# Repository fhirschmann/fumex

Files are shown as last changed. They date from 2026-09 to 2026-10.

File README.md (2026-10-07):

# FUMEX — a solder fume extractor that bends towards the work

Open the interactive 3D viewer (https://fhirschmann.github.io/fumex/)

Explore every part in the browser with an exploded view and section plane.

A 120 mm PWM fan pulls the smoke off the soldering iron through a 120 × 120 × 17 mm filter mat and blows it out the back, away from you. The housing stands upright over its electronics bay and then bends 15° forward, so the intake face looks down at the joint instead of past it. Battery powered: a 3.2 V 6000 mAh LiFePO4 pack runs it for hours and charges over USB-C while the fan keeps going.

Designed for a Bambu Lab H2S with AMS in Bambu PETG black and grey. The electronics are the ones from [LEO-AC1](https://github.com/fhirschmann/leo-ac1); only the fan is different.

**Status:** finished. The current revision has been printed and assembled, and all parts fit as designed.

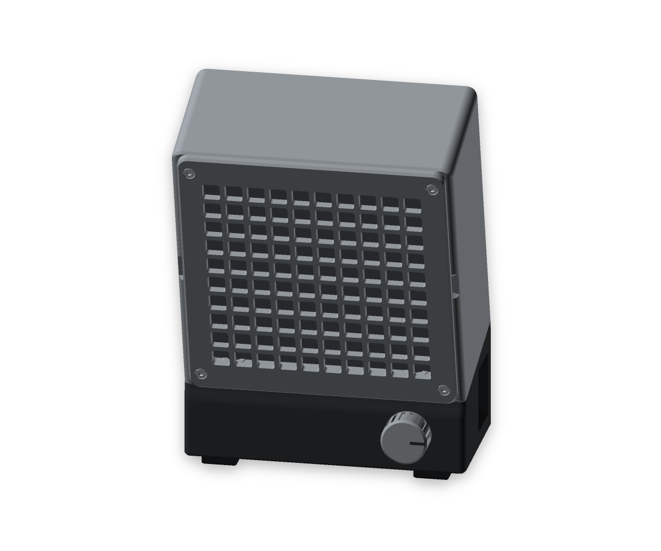
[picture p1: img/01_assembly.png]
Assembly (https://fhirschmann.github.io/fumex/)


| Exploded | Back |
|:---:|:---:|
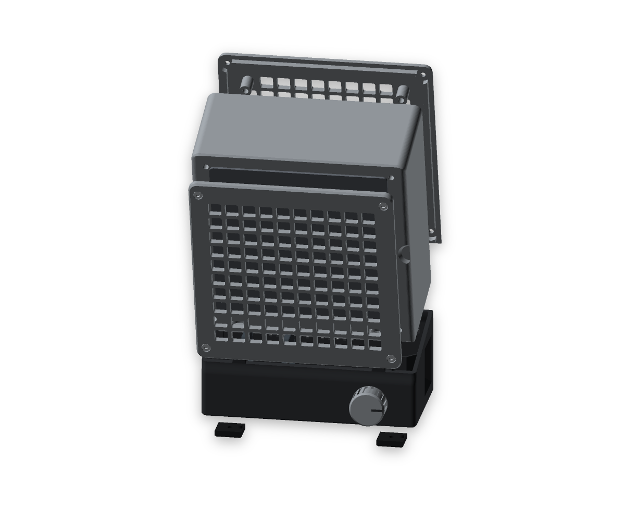
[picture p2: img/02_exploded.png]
Exploded
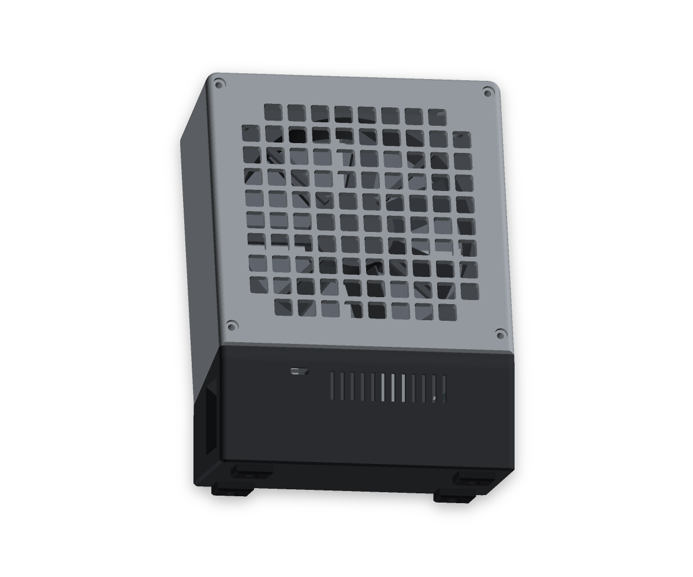
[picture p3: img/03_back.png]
Back
|  |  |

## How the air runs

```
grid of the cassette ─► mat 17 mm ─► support cross / throat 117 ─► fan 120 × 25 ─► plenum ─► slots in the back cover
```

The mat sits on the intake side, so flux resin settles in the fleece and the impeller stays clean. It is held by a continuous 2.25 mm lip around the 117 mm intake opening. A rear lip catches its edges, and a separate **support cross** behind the mat limits bowing towards the fan. Its solid 4 mm wide, 5 mm deep bars have a rounded centre and smooth transitions to wider end pads. The cross covers about 7.2 % of the opening, leaving 92.8 % open. It starts 0.5 mm behind the nominal mat rear face and leaves 5 mm between its central bars and the fan frame's front plane. The soft mat and printed bars can still flex; check for rubbing at full speed with the actual mat fitted.

| Filter support cross | Spring pad detail |
|:---:|:---:|
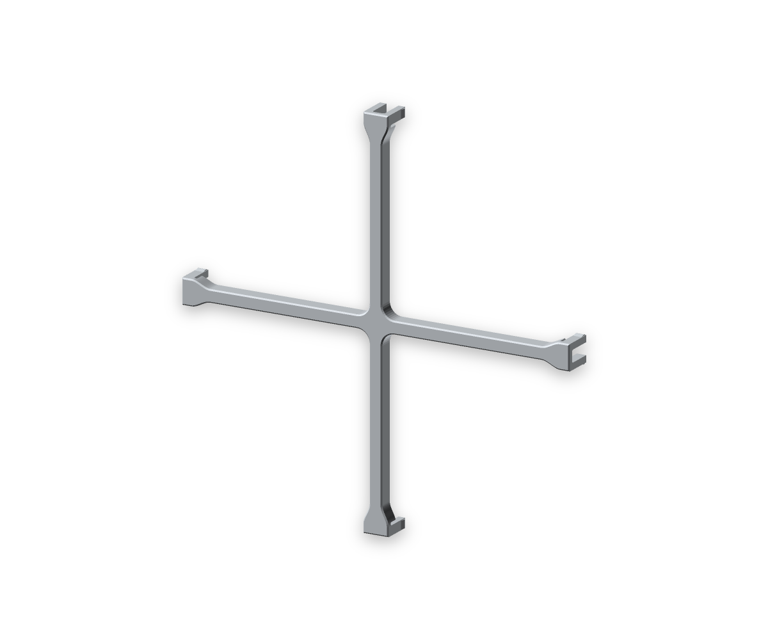
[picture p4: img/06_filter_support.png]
Filter support cross behind the mat
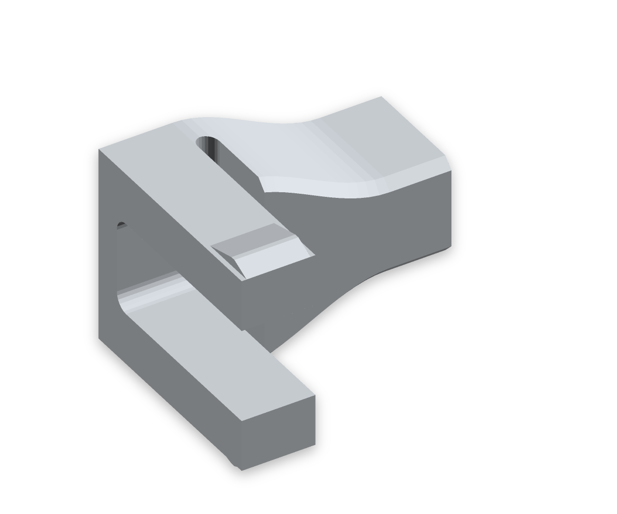
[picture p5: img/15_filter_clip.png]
Split spring pad and tapered gripping ribs
|  |  |

That rear lip is also the fan's seat: the filter tube ends as a ring the fan frame sits on. The support cross presses into four pockets from the back. Each end has two spring cheeks with tapered contact ribs: their free width is 8.7 mm against the existing 8.4 mm sockets, so they grip before the fan is fitted. Rounded relief slots let the cheeks flex; no screws or glue are needed. The fan frame supplies an additional rear stop. The fan is screwed to the **back cover** — four spacer posts on the cover carry its heat-set inserts, and the M3 × 30 go in from the front of the fan. Fan and cover are screwed together on the bench, where that face is reachable, and the pair goes into the head as one part. The four internal corner guides have 1.2 mm lead-in chamfers on both inner edges, widening the entry clearance to 1.6 mm per side before the straight 0.4 mm guides locate the frame.

Four **M3 × 8 Torx button-head screws** hold the filter cassette against the head, engaging Ruthex inserts in its four corners. The screws pass through Ø3.4 mm holes and sit in flat Ø6.4 mm recesses, 1.9 mm deep. Their heads lie fully inside the recesses, 0.25 mm below the cassette face. The cassette is 4 mm thick, with four smooth R6 corners matching the head’s upper corner radius. Its continuous 1.2 mm bevel leaves 2.8 mm of straight rim and R4.8 corners on the visible face. After removing the screws, use the two side finger scoops to lift it away. No magnets or insertion pauses are needed.

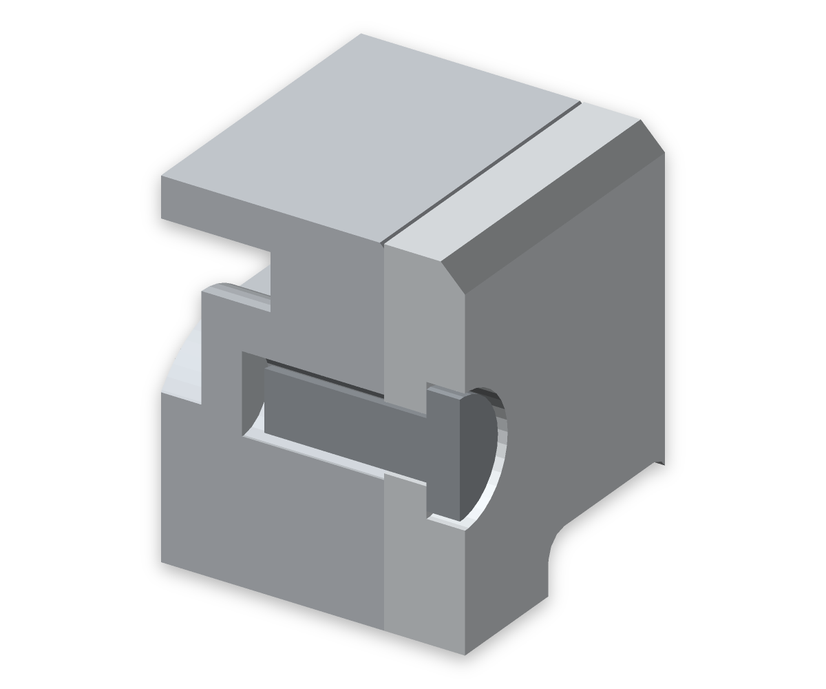
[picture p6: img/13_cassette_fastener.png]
Section through the recessed cassette screw and the head’s blind insert pocket


*Cassette corner section: the M3 × 8 head sits below the outer face; the Ruthex insert fits in the head’s blind pocket.*

The charge module stands upright on the ballast lid at the back of the bay. Its lower edge stands 9 mm above the lid. A separate holder modelled on LEO-AC1 grips only the cool OUT end: the end goes into a small L, then the board is pressed back until two spring jaws snap their hooks 0.9 mm over the part side at both long edges, and one cable tie through the holder's web secures it. The holder ends 11 mm from the OUT end, 5.7 mm before the 20 mm heatsink, and the hot end stays free. Its components face forwards and its heatsink faces the back wall, exposing both sides of the hot end to air. Five slots and the larger cable notch connect to the plenum behind the fan, with passages past the component side and the heatsink to the back-wall ventilation slots. This branch carries filtered air because it starts downstream of the mat. With the fan off, the same openings allow natural convection. Actual cooling must be checked with the assembled wiring and the housing closed.

| Component side | Heatsink side |
|:---:|:---:|
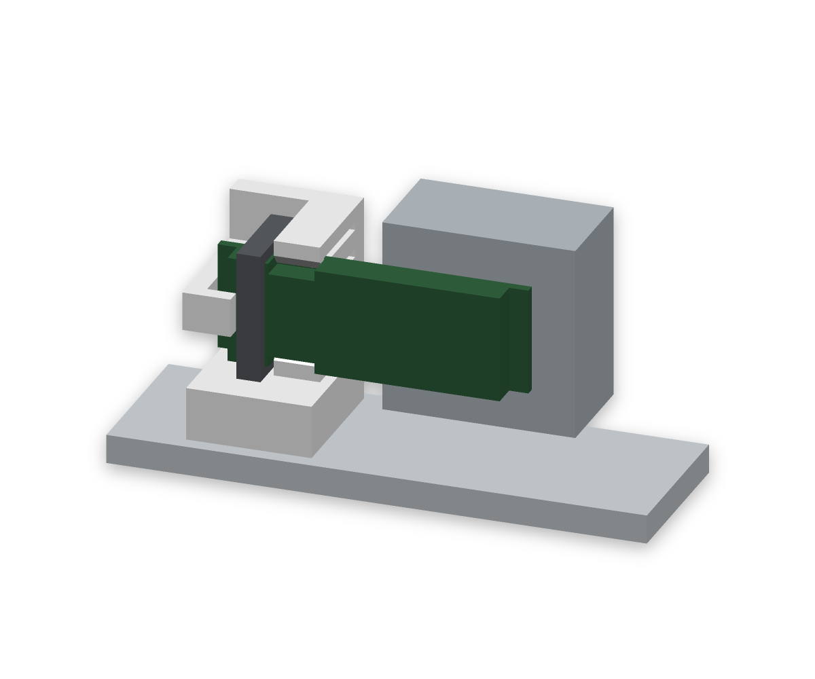
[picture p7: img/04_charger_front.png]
Upright charge module, component side
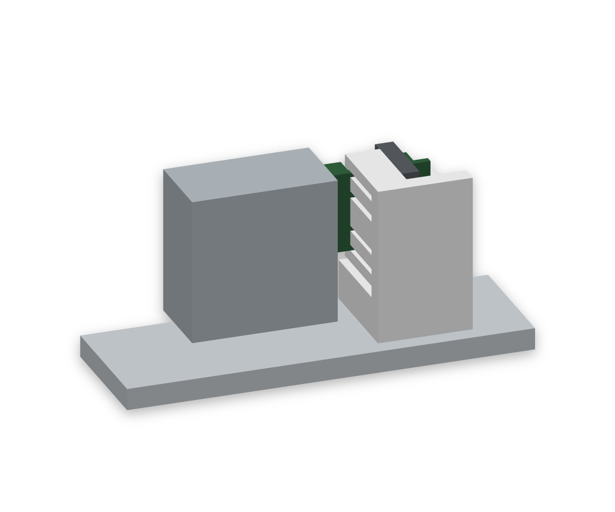
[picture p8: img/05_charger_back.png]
Upright charge module, heatsink side
|  |  |

## Printed parts

Nine part types, twelve printed pieces including the four feet.

| Part | Qty | Material | Size (mm) | Print orientation |
|---|---|---|---|---|
| `head` fan and filter housing | 1 | PETG grey | 145 × 145 × 70 | intake face on the bed |
| `base` electronics bay | 1 | PETG black | 145 × 74 × 57.3 | bottom on the bed |
| `head_back` back cover | 1 | PETG grey | 145 × 144.7 × 15.9 | outside on the bed |
| `ball_lid` ballast lid and USB keeper | 1 | PETG grey | 132.6 × 18.6 × 24.2 | flat on the bed |
| `chg_holder` charge-module clip holder | 1 | PETG grey | 13 × 21.5 × 16.1 | back plate on the bed, jaws upwards, 100 % infill |
| `filter_support` support cross | 1 | PETG grey | 123 × 123 × 9.8 | mat-facing side on the bed, four posts upwards |
| `cassette` filter cassette | 1 | PETG grey | 138 × 143 × 4 | grid face on the bed |
| `knob` speed knob | 1 | PETG grey + black pointer | Ø 24 × 13.5 | top on the bed |
| `foot` foot | 4 | TPU | 18 × 16 × 6.5 | ground face on the bed, 100 % infill |

All parts are in the Bambu Studio project [`stl/fumex_all_parts.3mf`](stl/fumex_all_parts.3mf): plate 1 head, plate 2 base, plate 3 cassette, plate 4 grey back cover, ballast lid, support cross and charge-module holder, plate 5 knob, plate 6 TPU feet. Head and cassette remain on their own plates; neither needs an insertion pause. The head is grey like the cassette, while the base is black. Filaments: 1 PETG black, 2 PETG grey, 3 TPU, 4 PETG black for the knob pointer. Map slots 1 and 4 to the same dark spool. The knob has a flush dark pointer in its first 0.8 mm and uses a prime tower on its own plate; all other plates are single-colour. Every part prints without supports.

Print profile: 0.20 mm layers, **1 wall on the first layer**, 4 walls on subsequent layers, 5 top/bottom layers, 20 % gyroid; support cross, charge-module holder and TPU feet at 100 % infill.

The six plates use about **480.1 g of filament and 16.3 hours**, including the knob's
two-colour prime tower. Head and cassette together use about **271.8 g and 8.1 hours**.

Use the **Engineering Plate with 3DLAC**. The saved positions let three successive
jobs use separate areas of one full-bed coating:

| Coating | Print these virtual plates in order |
|---|---|
| 1 | 1 Head → 2 Base → 3 Cassette |
| 2 | 4 Grey covers and support → 5 Knob → 6 TPU feet |

Between jobs, remove the finished parts, brims, prime tower and purge-line remnants;
leave the adhesive on the unused areas. Keep the saved positions instead of using
Auto Arrange or centring the parts again. The standard printer start and calibration
routines stay enabled and may revisit their usual areas. The filament profiles set
the Engineering Plate to 70 °C for PETG and 35 °C for TPU.

Before printing the base, use [`stl/fumex_usb_fit.3mf`](stl/fumex_usb_fit.3mf) to check the USB board in small sections of the real base and lid (about **10.0 g and 62 minutes**). With the lid section removed, lower the board in front of the channel and slide it towards the rear wall. Then place the lid section on its two small fixture pads and the retained screw-post seat: its central keeper secures the board from the front and above while leaving both side wire exits open. Two low triangular ribs brace the keeper against the lid. These two optional test pieces are not part of the full assembly.

A rounded end wall in the base sits beside the battery’s right end with 0.5 mm axial clearance. A full-height web joins the stop to the ballast trough wall for lateral support; its sloping top clears the removable lid. The left housing wall and this stop prevent lengthwise sliding. Two cable ties through integrated loops under the cell hold it down in its three saddles, including while the base is open. The ties run directly around the shrink-wrapped pack, without printed spacers. Tighten them gently by hand so the pack stays seated without crushing the wrap or electronics beneath it. Cut and replace the ties to remove the battery. Optional cushioning must not raise the cell from its designed seating height.

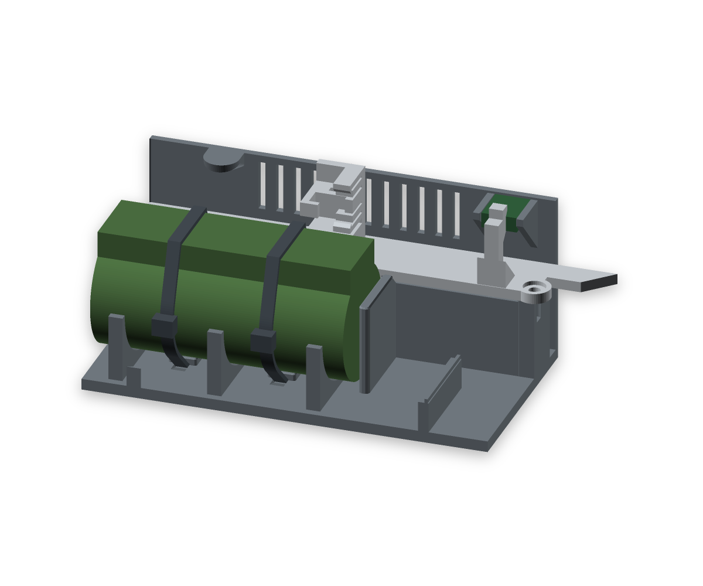
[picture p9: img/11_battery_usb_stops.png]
Direct battery cable ties and central removable USB-board keeper


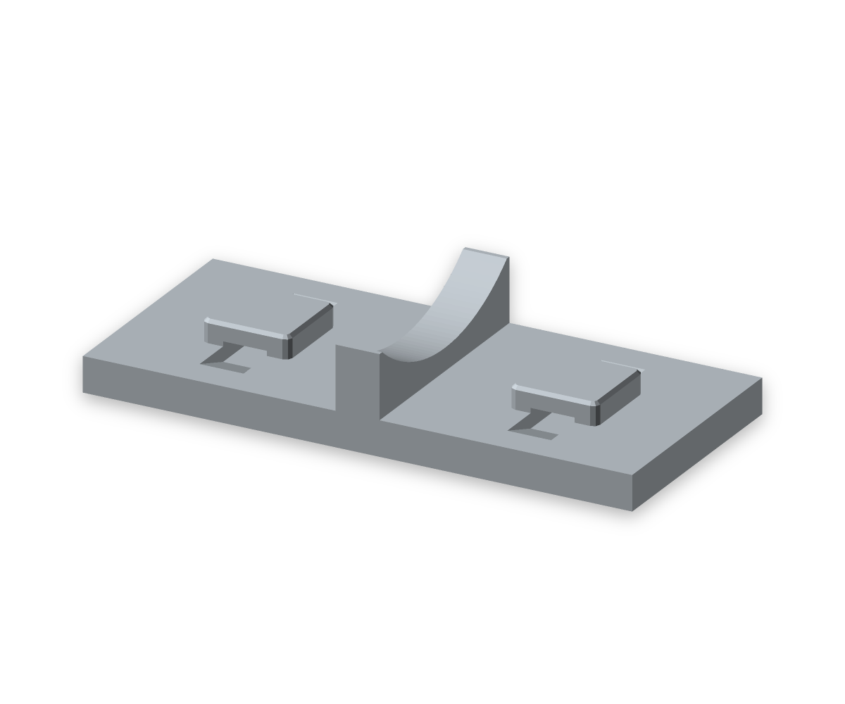
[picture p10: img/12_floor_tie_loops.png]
Two floor loops with shallow threading ramps, battery removed


## Bought parts

| Part | Qty | Link | Notes |
|---|---|---|---|
| Fan ARCTIC P12 Pro (PST) | 1 | [arctic.de](https://www.arctic.de/en/P12-Pro-PST/ACFAN00306A) | 120 × 120 × 25 mm, 185 g, 600–3000 rpm, 131 m³/h, 6.9 mmH₂O, 12 V / 0.33 A, 0 rpm below 5 % PWM; pressure-optimised, which is what a filter mat needs. Blowing towards the back |
| Filter mat, 120 × 120 × 17 | 1 | – | cut from a cooker hood mat: white fleece plus a carbon layer. **Fleece side to the front**, carbon behind it |
| Battery 3.2 V 6000 mAh LiFePO4 pack with protection board (BMS), JST-PH 2.0 | 1 | [eremit.de](https://www.eremit.de/p/3-2v-6000mah-pack-mit-schutz-arduino-aio-jst-ph-2-0-stecker) | cell Ø 32.5 × 71.6 mm, lying across the bay, protection board up; charge only with a LiFePO4 charger (3.65 V), **no** TP4056 |
| Charge/boost module "2-in-1 3.2 V LiFePO4", **12 V variant** | 1 | [AliExpress](https://de.aliexpress.com/item/1005008094801881.html) | eletechsup LFUPSMA, board 32.2 × 11 × 1.0 mm; IN± 5 V charging, B± battery, O± 12 V. See the note on its 0.32 A rating below |
| Aluminium heatsink 20 × 20 × 10 mm with a 1 mm insulating silicone thermal pad | 1 | – | on the back of the charge module behind the charger IC, overhanging the IN end by 4.5 mm and facing the back-wall vents; the pad must cover the whole heatsink face |
| PWM fan controller CNY-FA5-PRO, DC 8–24 V, with potentiometer and switch | 1 | [AliExpress](https://de.aliexpress.com/item/1005010113177510.html) | 41 × 32 × 15 mm, flat in the bay, shaft through the front panel |
| USB-C PD trigger module, Type A (default 5 V) | 1 | [AliExpress](https://de.aliexpress.com/item/1005010610660644.html) | charging socket high in the back wall, above the ballast lid. **Leave pads 1–4 open** (they select 9/12/15/20 V); the charge module only takes 4–6 V, check 5 V with a multimeter before connecting |
| ON-OFF rocker switch, snap-in, 21 × 15 mm (cut-out 19.2 × 12.2 mm) | 1 | [AliExpress](https://de.aliexpress.com/item/1005008871215158.html) | in the right side wall, long side upright |
| LED 3 mm, breathing/fading, 3.3 V, water clear | 1 | [AliExpress](https://de.aliexpress.com/item/1005005336879647.html) | charge indicator beside the knob, fitted from inside behind a closed 1.8 mm front skin; check visibility through the chosen PETG |
| Additional Ø3 mm LED, optional | 1 | – | second closed-front pocket beside the charge indicator; select and wire it for the intended signal |
| Resistor 220 Ω, 1/4 W | 1 | – | series resistor for the LED on the 5 V USB input |
| Resettable PTC fuse Bourns MF-R160 or RXEF160 (1.6 A hold) | 1 | – | optional, between battery plus and the switch, in heat shrink |
| Thermoplastic screws 2.5 × 8, flat underside, head Ø4.5 | 2 | user’s stock | PWM controller into the two floor bosses |
| Heat-set inserts Ruthex RX-M3x5.7 | 22 | [ruthex.de](https://www.ruthex.de) | 4 cassette, 4 fan, 4 back cover, 4 head screws, 4 feet, 2 ballast lid |
| M3 × 30, ISO 7380 Torx | 4 | – | fan to the back cover; the frame alone is 25 mm thick, so nothing shorter reaches a thread |
| M3 × 8, ISO 7380 Torx | 18 | user’s stock | cassette (4), back cover (4), head screws (4), feet (4), ballast lid (2) |
| Iron offcuts for the ballast | – | – | up to 40.3 cm³, about 189 g, loose in the trough under its lid |
| JST-PH 2.0 cable, 2-pin, mating the battery plug | 1 | – | battery to the switch and B+ / B− |
| Cable tie, 2.5 mm wide × 1.2 mm thick | 1 | – | secures the clipped charge module through the holder's web |
| Cyanoacrylate gel (superglue gel) | a few drops | – | glues the charge-module holder over its two pads on the ballast lid |
| Cable tie, 3.6 mm wide × 1.2 mm thick, 150 mm long | 2 | – | battery restraint directly around the wrapped pack through the floor loops; tighten gently by hand |
| Silicone wire 24 AWG, red and black | about 1 m | – | USB-C module, switch, LED, 12 V to the PWM controller |
| Heat-shrink tubing 2–3 mm | – | – | every solder joint |
| Thin cushioning, optional | – | – | only if it compresses without raising the cell; the ties provide retention. Leave the protection board free |

## Wiring

```
USB-C PD trigger 5 V ─┬──► IN+ / IN−   charge/boost module (12 V) ──► O+ / O− 12 V ──► PWM controller ──► 4-pin fan
                      └──► 220 Ω ──► LED ──► IN−
battery (JST-PH, built-in BMS) ──► (PTC) ──► rocker switch ──► B+ / B−
```

- The module charges the battery with up to 1 A and delivers 12 V at the same time, so the fan keeps running while it charges. Use a USB power supply with at least 2 A.
- With the switch in the battery line, off really disconnects the battery, and the battery only charges with the switch on. To charge without the fan running, turn the knob down until it clicks.
- The LED shows that the charging cable is plugged in, not the charge state.
- **Start slow.** The module is specified for 0–0.32 A at 12 V and the P12 Pro draws 0.33 A at full speed, so the top of the knob range sits right at its limit: it gets warm there, and switching on at 100 % may brown out. Turn the knob up once the fan is running. At half speed the pack lasts far longer than the roughly four hours it manages flat out.
- The CN3058E on the module is a linear charger: at 1 A from 5 V it turns about 1.6 W into heat while the battery charges. The upright board exposes its components at the front and its heatsink at the back to the passages between the head-floor slots and the back-wall vents. Keep wires clear of both sides and check temperatures in the closed housing while charging, with the fan running and stopped.
- If that is still not cool enough for your taste, replace the ISET resistor (marked 122, 1.2 kΩ) with 2.4 kΩ: half the charge current, half the heat, and 12–13 hours for a full charge.

## Assembly

The spring support cross fits the existing 8.4 mm head sockets: replace only the cross to add retention in an already printed head. The front insert posts extend farther down into the base front wall at their original 9.2 mm width, without broad reinforcement feet. Their wall connections follow the curved outer face without a projecting ledge. Their screw positions and upper fit still match an already printed head. The screw-fastened cassette requires the matching **new head and cassette**; the former magnetic parts do not provide this screw interface. If the screw-version head is already printed, only the cassette needs replacing for the rounded-corner refinement. The base and current back cover remain compatible. Very early versions need the current back cover with its shorter fan posts.

1. Press in the 22 heat-set inserts: 4 into the head’s intake corners from the front, 4 into the spacer posts of the back cover from the fan side, 4 into the bosses along the head’s side walls from the back, 2 into the raised base bosses behind the front wall and 2 into its rear rim, all four from above, 4 into the base floor from below, and 2 into the ballast-lid posts from above. The cassette inserts sit flush with the intake face in Ø4 × 7 mm blind pockets; their bosses have 2 mm closed ends.
2. Align all four support-cross pads with the rear-open pockets, then press the cross in evenly, with its flat crossed face towards the mat. The split spring pads grip the sockets without the fan fitted. Check that every pad holds and that the cross stays seated when the open head is turned over. Pull it out evenly for service; do not twist the spring tips. No screws or glue are needed.
3. Lay the back cover on the bench, set the fan on its four posts **blowing towards the cover**, so it pushes the air out through its grid, and screw it down with M3 × 30 from the front of the fan. The cable comes out on the side that will face the head floor.
4. Place the PWM controller flat on its rib pads, with the potentiometer through the front wall. Insert it before the rocker switch: keep the PCB rear tilted up, feed the shaft through the covered front slot, then lower it onto the pads and bosses. Fasten its two front PCB holes into the floor bosses with the 2.5 × 8 thermoplastic screws, without a nut or washer on the front. Use a driver with a slim shaft no wider than 4 mm for the first 25 mm above the head and tighten gently by hand.
5. Glue the LED into its blind pocket from inside, with its flange against the rear of the boss and the front skin intact. A second matching pocket sits 12 mm to its left. With the head and ballast lid removed, lower the USB-C board into the bay in front of its channel, then slide it straight towards the back wall until the receptacle sits in the opening. The channel’s two raised 45° gussets support the board. Its 10.26 mm guide width gives the 10.06 mm PCB a nominal 0.10 mm clearance per side; small lead-in bevels ease insertion through the open front. Route the wires upwards on both sides of the central lid keeper and leave the rocker switch out until the ballast lid is secured. Keep wires clear of the lid and switch recess.
6. Put CA gel into the two sockets under the charge-module holder and press it over the two pads on the ballast lid until the socket floors sit on the pads. Stick the insulating pad onto the metal pad on the back of the charge module and the heatsink onto the pad, centred across the board and 4.5 mm past the IN end. With the IN end swung slightly forwards, slide the board's OUT end into the holder's small L, components facing forwards; then press the board back until both jaws snap over its long edges. Secure it with one 2.5 × 1.2 mm cable tie through the tunnel in the holder's web and around the board, 3.35–5.85 mm from the OUT end, between the OUT wire pads and the jaws. Check the hooks and tie against the actual components and solder joints before tightening. Leave the heatsink end free, leave slack in the wires and keep the air passages open. To remove the board, cut the tie, spread both jaws, slide the board 3.5 mm towards its IN end out of the L, pull it forwards from under the upper jaw and lift it out.
7. Fill the ballast trough behind the battery with iron offcuts — up to about 189 g. With the battery and rocker switch still out, lower the loaded lid into the bay in front of the USB channel. Slide it rearwards in two stages, lowering it between them, until it rests on its two screw posts. The central keeper sits just in front of the USB board and overlaps its upper edge, leaving both wire exits open. Two triangular ribs at its foot spread the load into the lid. The raised 45° supports stay above the plain lid. Fasten it with two M3 × 8 into the heat-set inserts; the right screw sits farther inwards and forwards so a straight driver clears the head-mounting bosses. Refit the rocker switch. Fill the trough properly or pack the rest with foam to prevent loose pieces rattling.
8. Thread a cable tie through each floor loop before laying the battery into its three saddles, protection board up and cable end to the right. Its right end sits beside the base’s rounded end wall. Close each tie directly around the wrapped pack and tighten gently by hand, with the tie heads in front of the cell, and trim the tails. Keep the battery cable above the end stop. The ties hold the battery even before the head is installed.
9. Push the knob onto the shaft until it bottoms; it then stands 1.2 mm off the wall and turns freely. Keep it as a removable press fit for access to the controller; check retention on the actual shaft.
10. Lower the head onto the base rim. With the cassette and mat removed, fit two M3 × 8 straight down through the shallow front pockets into the raised base inserts, in the same direction as the rear pair. Reach them through the intake with the small Wera ratchet and a 25 mm TX10 bit fitted directly into the ratchet. Fit the rear pair of M3 × 8 down through the head floor before installing the fan-and-cover assembly. All four screws clamp directly against the base. Bend the lower edge of the soft mat over the two exposed front screw heads when refitting it; they extend about 2.8 mm into its nominal envelope. Hold the fan-and-cover assembly back while feeding its connector down into the base. Lay the cable into the **16 mm wide, rear-open floor notch**, then slide the assembly in from the back — the corner guides in the head take it onto its seat — and check that the actual fan frame captures all four support-cross posts. Screw the cover down with 4 × M3 × 8.
11. Screw the four TPU feet on from below with M3 × 8; the small peg beside each screw stops them turning.
12. Push the mat in past the lip so the white fleece ends up facing **forwards**, towards the cassette, and the dark carbon layer faces the fan. Place the cassette on the intake face and fasten its four corners with M3 × 8. Tighten gently by hand against the flat bottoms of the recesses; the button heads sit fully below the cassette face.

| Two lid screws, lifted for clarity | USB-C mount, cutaway |
|:---:|:---:|
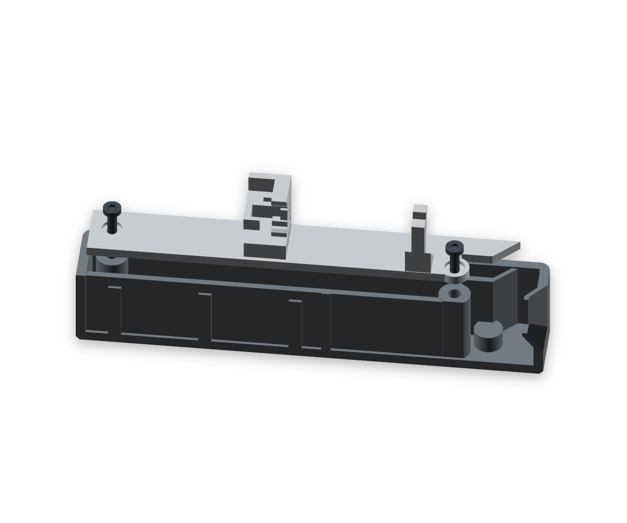
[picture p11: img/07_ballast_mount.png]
Two M3 screws into Ruthex insert posts
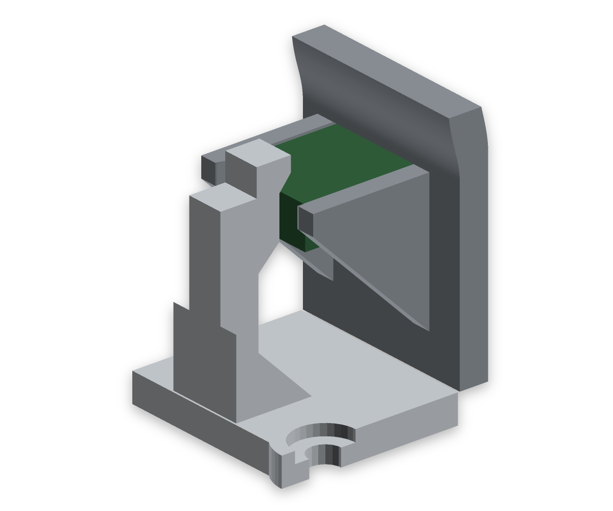
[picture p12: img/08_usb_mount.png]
USB-C channel supported by 45-degree back-wall gussets
|  |  |

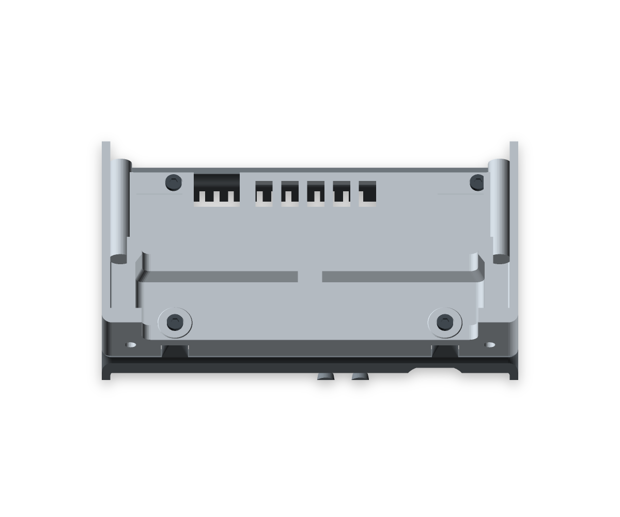
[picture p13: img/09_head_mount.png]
Four head screws with narrow, downward-extended front insert posts


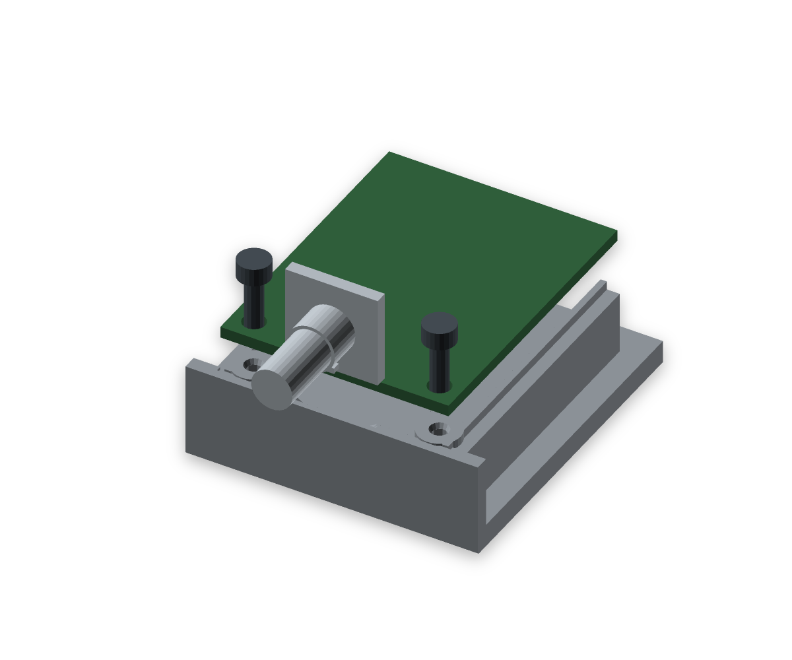
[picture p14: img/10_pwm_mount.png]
PWM PCB and two floor bosses, exploded with components omitted


To change the mat: remove the four M3 × 8 cassette screws, lift the cassette off using its side scoops, pinch the flexible mat and pull it past the retaining lip, then press the new one in and refasten the cassette.

For electronics service, remove the head, cut the two battery ties and lift out the battery, release the rocker-switch clips and pull the switch out through the side. Unscrew the ballast lid, lift it about 3.4 mm, pull it 4 mm forwards, lift it another 3 mm, then pull it another 16 mm into the empty battery bay. Centre it slightly to the right (about 0.2 mm) and lift it out. Leave enough wire slack for this movement. The USB board then slides forwards out of the rear opening and lifts out. For PWM-controller removal, also remove the knob and its two PCB screws before tilting and withdrawing the PCB. Tilt its rear up partway, pull it farther backwards under the front insert post, then continue tilting it upwards. Once the shaft clears the front rim, move the controller about 9 mm left before the final upward lift, clearing the rear mounting area.

## Design notes

- The base has a 145 × 74 mm footprint. Its upper 8 mm curve inwards to meet the projected outline of the head at the 15° joint, so the head closes the electronics bay without a separate cover or a projecting base lip. The four cassette fasteners sit in the intake corners, clear of the airflow opening.
- The head leans forward, so the centre of mass moves towards the front feet. The model computes it from the part masses and checks that it stays at least 15 mm inside the foot polygon: 29.3 mm at the front, which is 21.8° of tip angle at about 1.01 kg. That angle is measured from the sole of the feet and against the contact patch the pads' bottom chamfer actually leaves, not against their full outline. The ballast does most of that work — the cell sits well forward so everything behind it is one trough across the full width, 40.3 cm³ or about 189 g of iron offcuts under a screwed lid, with the USB-C socket above it.
- **Filling the ballast:** only behind the cell, never in front of it — mass ahead of the centre of mass makes tipping worse, and the large free space at the front is exactly the wrong place. The screwed lid keeps the loose pieces away from the wiring. Two M3 × 8 screws at the left and right ends engage heat-set inserts in the printed posts.
- Walls 3 mm, base floor 3.2 mm, back cover 4 mm. Corner radius 6 mm at the top of the head, 3.5 mm on the four vertical edges, and 0.5 mm where head and base meet — the joint is a straight parting line that runs into the rounded vertical edge, and that edge carries the corner. A larger radius there put two different arcs plus the chamfers around the joint into the same corner, which looked like a jumble. The plan and elevation radii blend smoothly at the four upper corners. The base rim follows the tilted head contour around the joint; the deliberate 15° bend and rear edge chamfers remain. The existing outline and corner radii are retained around the new cassette insert bosses.
- The joint plane rises 15° towards the back, so it meets the vertical back face of the base at 75°. That edge — the one the back cover lands on — is chamfered at 45°, as is the lower edge of the cover itself, and the two form one groove instead of a sharp rim.
- Four M3 × 8 screws secure the corner regions of the joint directly into the base. The front insert posts retain their 9.2 mm width and continue farther down into the front wall. Their lower ends slope upwards towards the inside to print without supports and clear the PWM controller. There are no broad reinforcement feet. The top faces, insert entries and screw positions still fit the existing head. Their screw heads sit in shallow 0.7 mm pockets; fit the front pair through the empty intake with a small bit ratchet and the rear pair before the fan and cover. The soft mat bends locally over the exposed front screw heads.
- The mat is 17 mm of soft fleece, so it seals against the chamber walls: everything downstream of it is filtered air.
- The two LED pockets are Ø3.2 mm, 12 mm apart, and stop 1.8 mm behind the closed front surface. Their flange seats are 6.8 mm behind the front, leaving the LED lenses 0.3 mm clear of the pocket bottoms. Leave the front closed and check LED visibility through the chosen printed material.
- PETG softens well below a soldering iron. Keep the tip away from the housing.

## Build from source

Model: [`fumex.scad`](fumex.scad) (OpenSCAD, parameters at the top), project settings and checks: [`print_project.py`](print_project.py). The tools of the skill `openscad-print-project` (`opp`, version pinned in [`requirements.txt`](requirements.txt); not public, they run locally) export and check the meshes, slice with the Bambu Studio CLI and build the [3D assembly viewer](https://fhirschmann.github.io/fumex/), published from [`docs/index.html`](docs/index.html) on GitHub Pages. [BOSL2](https://github.com/BelfrySCAD/BOSL2) supplies the edge profiles and is pinned as the `BOSL2/` Git submodule; initialise it before opening the model in OpenSCAD or running the tools.

```sh
git clone --recurse-submodules https://github.com/fhirschmann/fumex.git
cd fumex
git submodule update --init --recursive          # pinned BOSL2 geometry library
python3 -m venv .venv
.venv/bin/python -m pip install -r requirements.txt   # opp, needs access to the private tools repository
.venv/bin/opp all      # export and check stl/, asm/, docs/verification.json; islands, overhangs, thickness,
                       # fins, inlays; Bambu Studio CLI and project 3MF; viewer incl. docs/index.html
.venv/bin/opp render   # img/, transparent PNGs
```

The fan in the model and the viewer is a simple parametric placeholder; no manufacturer CAD is used or needed.

## Licence

Model, printable files, images and documentation: [CC BY-NC-SA 4.0](LICENSE). The BOSL2 submodule retains its own [BSD-2-Clause licence](BOSL2/LICENSE).

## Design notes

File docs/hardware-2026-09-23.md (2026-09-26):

# FUMEX – Filterstütze, Platinenhalter und Ballastdeckel

Stand: 23. September 2026. Dieser Nachtrag ersetzt die früheren Beschreibungen der Ladeplatinenhalter und Deckelverschraubung im [BOSL2-Bericht](bosl2-charger-2026-09-23.md). Das [ursprüngliche Audit](audit-2026-09-23.md) bleibt als historischer Prüfstand erhalten.

## Änderungen

| Bereich | Aktueller Aufbau und Nachweis |
|---|---|
| Filtermatte | Separates, eingeschobenes Kreuz mit 2,4 mm breiten und 3,2 mm tiefen Stegen. Vier Enden werden zwischen Kopf und Lüfterrahmen gehalten. 2,3 mm Abstand zur nominellen Mattenrückseite, 5,0 mm von den mittleren Stegen zur Rahmenvorderseite. Das Kreuz belegt 4,101 % des freien Ansaugquerschnitts. |
| Ladeplatine | Einseitige Befestigung am kühlen OUT-Ende wie bei LEO-AC1. Die Kühlkörperseite hängt frei; der gedruckte Halter endet 4,7 mm davor. Untere Auflage, rückseitige Auflage und Endanschlag sind jeweils durch Kontaktproben nachgewiesen. |
| Kabelbinder | Ein 2,5 × 1,2 mm breiter/dicker Binder läuft an der LEO-Position 11,25–13,75 mm vom OUT-Ende durch die Halterung. Zusammenhängender Durchgang, 0,3 mm Spiel zum gedruckten Halter und kollisionsfreies Band nachgewiesen. Zum Platinenwechsel Binder durchschneiden und ersetzen. |
| USB-Platine | Der innere Kabelausgang ist offen; ein 2,7 mm breiter seitlicher Anschlag nimmt die Steckkraft auf. Der Anschlag greift nach 0,25 mm. Zentraler Endkorridor und Kabelwege ober- und unterhalb der Platine bleiben frei. |
| Rückwand | Die beiden bisherigen Kabelbinderösen sind entfernt. |
| Ballastdeckel | Genau zwei M3 × 8, links und rechts mittig bei (10, 63) und (135, 63) mm. Ruthex RX-M3x5.7 in Ø4 × 7 mm Taschen und Ø10 mm Domen. Geschlossene Kopfsitze, vollständiger Gewindeeingriff, 0,8 mm Abstand zum Taschenboden und gerader Werkzeugzugang sind geprüft. |
| Schalter | Aussparung in Wanne und Deckel folgt dem Schaltergehäuse und der verbreiterten Aufnahme. Auch die Anschlussfahnen haben jetzt 1,5 mm Abstand; vorher lag die Deckelkante dort tangential an. |
| Ballastabdeckung | Die hinteren Deckelecken folgen der tatsächlichen Innenkontur. Nach Entfernen der früheren Eckpfosten hätten die alten 5-mm-Abschrägungen Öffnungen hinterlassen. Der neue Deckel schließt die Ballastfläche bis auf die vorgesehene 0,2-mm-Montagefuge. |

Ladeplatine mit einseitigem Halter und Kabelbinder

## Aussagekraft der Prüfungen

Die neuen Prüfungen verwenden exportierte Netze. Negativkontrollen erkennen den alten beidseitigen Platinenhalter, den verschlossenen Binderkanal, den früheren USB-Querbalken, die vier alten Deckelschrauben, die zu großen hinteren Deckelecken und die Berührung der Schalteranschlüsse.

Die Ladeplatine samt Kühlkörper lässt sich nach Entfernen des Binders 30 mm nach oben herausnehmen. Der bestückte Deckel ist einschließlich Binder über 10 mm Hub geprüft. Ein vollständiger Ausbau durch anschließendes Kippen ist mit diesem geraden Prüfweg nicht nachgewiesen.

Die Lüfterseite des Stützkreuzes ist auf das vereinfachte Lüftermodell abgestimmt. Nachgiebigkeit und Kriechen der gedruckten Stege sowie Wölbung und lose Fasern der realen Filtermatte sind nicht simuliert. Die reale Matte deshalb bei maximaler Drehzahl auf Berührung prüfen. Die freien Luftkorridore an der Ladeplatine belegen geometrischen Zugang, keine ausreichende Kühlleistung. Kabelbinderkopf, tatsächliche Lötstellen und flexible Kabel bleiben reale Montageprüfungen.

## Abschließende Prüfung

Der vollständige Export besteht: **8 Druckteiltypen, 11 Druckteile, 340 koaxiale Merkmals-Paare, 496 Baugruppenpaare und 9 geradlinige Montagewege**. Alle Drucknetze sind geschlossen, jeweils ein Körper und ohne degenerierte Dreiecke. Alle vier Analysen über alle acht Typen sind **CLEAN**: Inseln, Überhänge (100-mm²-Schwelle), Wanddicke und freie dünne Stege. Die bekannten numerischen Trimesh-Warnungen am Kopf bleiben; 64.941 von 65.128 Wanddickenproben liefern einen Messwert.

Bambu Studio slict alle acht Teile und vier Platten erfolgreich mit deaktivierten Stützen: **468,9 g / 15,3 h** als angeordnete Platten, **469,3 g / 16,3 h** als Einzelteilaufträge. Die bekannten Hinweise „floating cantilever“ an Basis und Kopf bleiben bestehen. Deckel und Stützkreuz erzeugen keinen zusätzlichen Slicerhinweis.

Ballastkapazität **44,0 cm³**, etwa **207 g** bei der angenommenen Packungsdichte. Geschätzte Gesamtmasse **1.020,5 g**, Kippwinkel **21,8°**, Abstand des Schwerpunkts zur vorderen Aufstandskante **28,9 mm**. Keine physischen Druck-, Festigkeits-, Luftstrom- oder Temperaturversuche.

STLs, 3MF, Bilder, README und beide Viewerdateien wurden neu erzeugt. Modell-SHA-256: `7381a66bf0c48c11e6b923835a3fbaf9c79f2a9c6862184d3fb3efd0b7a828b8`.

Nachweise: [Geometrie und Montage](verification.json), [Druckbarkeitsanalysen](hardware-2026-09-23/analysis.json), [Slicer](slicer-summary.json), [Viewer](index.html).

Die allgemeine Falle beim Versetzen von Eckpfosten wurde im Skill `openscad-print-project` ergänzt: Deckung eines Inhaltsvolumens separat von Netzdichtigkeit und Schraubenkontakt prüfen; Insertbohrungen nicht als Ballastvolumen mitzählen.

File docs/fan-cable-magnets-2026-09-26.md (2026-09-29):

# FUMEX – Korrektur nach dem ersten Druck

Stand: 26. September 2026  
Modell-SHA256: `d2d21113b80c1214a133452ce8b9820178cb5de3a1354b2a165ddce98acb4137`

> Historical report for the source revision above. The 2026-09-29 cassette screw conversion supersedes its magnet geometry, hardware and insertion-pause instructions. The linked production 3MF contains the current screw version; this report and its magnet-section image remain historical evidence.

## Ergebnis und benötigte Teile

Die Lüfterkabeldurchführung ist vergrößert und nach hinten geöffnet. Alle acht Magnete werden jetzt während des Drucks eingelegt und vollständig eingeschlossen, mit **1,2 mm Kunststoff auf beiden axialen Seiten**. Neu zu drucken sind **Kopf, Kassette und Rückdeckel**. Die Base und das Filterkreuz können weiterverwendet werden.

Die Kopf-Ansaugplatte ist nun 5,6 mm dick. Filter, Stützkreuz und Lüfter sitzen innen 2,4 mm weiter hinten; die vier Rückdeckelpfosten werden entsprechend kürzer. Dadurch bleiben der volle Filterraum und der 5-mm-Abstand zwischen Kreuz und Lüfterrahmen erhalten. Ein bloßes Ansetzen von vier Magnetböden nach innen hätte stattdessen die Filterecken gedrückt. Die Außenmaße des Kopfs bleiben unverändert, die Kassette wird von 4,5 auf 5,6 mm dicker.

## Magnete und Druckpausen

- Acht geschlossene Kavitäten Ø10,3 × 3,2 mm für nominell Ø10 × 3 mm große Magnete.
- In beiden Drucklagen: Taschenboden bei Z1,2, Taschenende bei Z4,4 und Teilwandende bei Z5,6 mm.
- Das Projekt-3MF enthält auf **Platte 1 „Head“ und Platte 3 „Cassette“** jeweils eine Pause **vor der 4,6-mm-Schicht**, bevor diese die vier Kammern schließt. Das gilt für das enthaltene 0,2-mm-Schichtprofil; nach Änderung der Schichthöhe die Pausenposition erneut prüfen.
- Vorher denselben Pol auf allen acht Magneten markieren. Auf beiden Platten jeweils vier Magnete **mit der Markierung nach oben** einlegen; in Einbaulage stehen sich dadurch anziehende Pole gegenüber.
- Jeden Magneten flach auf den Taschenboden setzen. Ein 3-mm-Magnet endet bei Z4,2, also 0,2 mm unter dem zuletzt gedruckten Rand. Erst dann fortsetzen. Kleber ist nicht erforderlich.
- Die beiden sichtbaren Kunststoffhäute ergeben 2,4 mm Wand zwischen den Paaren; mit dem modellierten axialen Spiel beträgt der Abstand der auf ihren Druckböden liegenden Magnete 2,6 mm. Eine reale Abzugskraft ist nicht gemessen.

**Die Pausen stecken im [Projekt-3MF](../stl/fumex_all_parts.3mf), nicht in den STL-Dateien.** Auch einzelne Diagnose-3MFs unter `build/` sind keine Druckvorlage mit diesen Pausen.

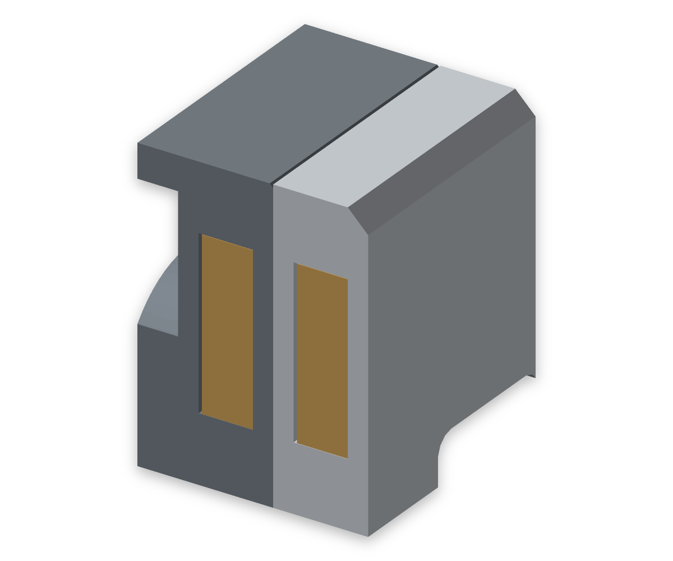
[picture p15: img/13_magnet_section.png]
Schnitt durch Kopf und Kassette mit eingeschlossenen Magneten


## Kabeldurchlass

Der neue U-Ausschnitt ist **16 × 13,3 mm** groß und reicht bis zur offenen Rückseite des Kopfs. Die benachbarte erste Lüftungsöffnung entfällt; zur nächsten bleiben 5,5 mm Boden stehen. Die übrigen fünf Schlitze bleiben an ihrer ursprünglichen Position, mit 3,3 mm Material bis zum hinteren Bodenrand.

Bei der Montage die auf dem Lüfter befestigte Rückwand noch etwa 40 mm zurückhalten, den Stecker in die Base führen und das Kabel in die offene Aussparung legen. Erst danach Lüfter und Rückwand einschieben. So muss kein Stecker durch ein bereits geschlossenes Gehäuse gefädelt werden. Schraubensitz und Auflagering neben dem Ausschnitt bleiben vollständig erhalten.

Der geprüfte kontinuierliche Einlegeweg verwendet eine **angenommene** Steckerhülle von 14 × 8 × 16 mm, mit mindestens 0,65 mm geometrischem Abstand. Der anschließende 8 × 4 mm große Kabelkorridor bleibt auch während des Einschiebens frei. Der tatsächliche Arctic-Stecker und der flexible Verlauf bis zum Kabelauslass sind nicht vermessen.

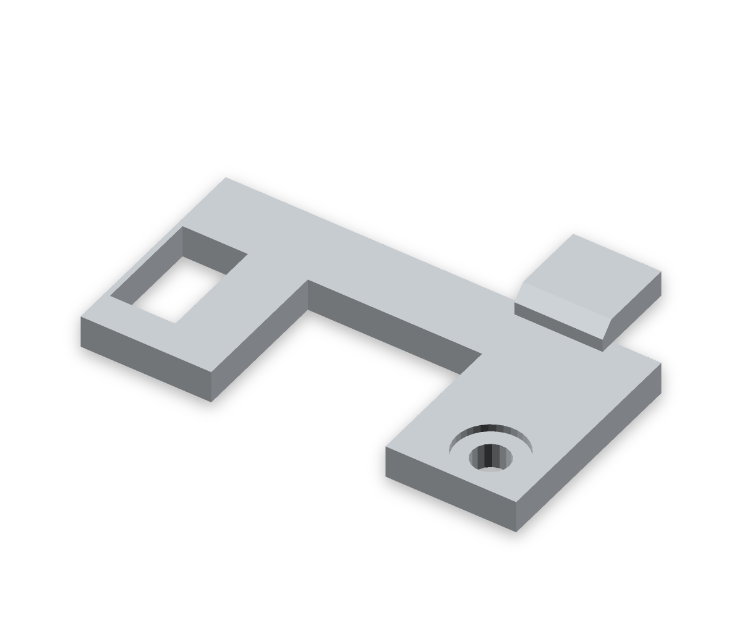
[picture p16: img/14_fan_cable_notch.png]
Kabelöffnung und benachbarter Schraubensitz


## Korrektur der bisherigen Prüfung

Beim alten Kopf waren sowohl Frontplatte als auch Magnettaschen 3,2 mm tief: Die Taschen hatten dadurch keinen durchgehenden Boden. Die bisherigen Proben erfassten nur die radialen Seitenwände. Auch der zu kleine Kabeldurchlass war ohne Steckerweg als plausibel eingestuft worden. Diese beiden Aussagen des [vorherigen Audits](preprint-audit-2026-09-25.md) werden durch die reale Druckrückmeldung und die neuen Prüfungen korrigiert.

Die neuen Proben untersuchen alle acht Kavitäten, beide vollflächigen axialen Wände, die ebenen Anschläge, Magnetlage sowie Kabelöffnung und Steckerweg am exportierten Netz. Als Gegenprobe fallen die alten Kopf- und Kassettennetze durch; die alte Kabelöffnung blockiert die neue Mindestöffnung mit 232,255 mm³. Geschlossene Hohlraumschalen werden jetzt korrekt von getrennten Materialkörpern unterschieden. Diese allgemeine Werkzeugkorrektur ist im gemeinsamen Skill als `9fedfc0` übernommen und mit 13 Regressionen sowie der vollständigen Projektvorlage geprüft.

## Freigabeprotokoll

- **Export:** zehn gültige Drucknetze mit jeweils einem Materialkörper; Kopf und Kassette enthalten zusätzlich je vier korrekt orientierte Kavitätsschalen. 431 koaxiale Merkmals-Paare und alle zehn regulären Montagewege bestanden. 561 mögliche Körperpaare ergeben nach 29 begründeten Ausnahmen 532 allgemeine Kollisionsprüfungen.
- **Detailproben:** alle acht Magnetkavitäten und Vollhäute bestanden. Beide kontinuierlichen Steckerwege frei; fünf hintere Stege gemessen jeweils 3,300 mm. Alle vier verkürzten Lüfterauflagen samt Insertwänden und Blindböden vollständig. Lokale Mattenberührungen bleiben auf die bisherigen Schraubenzonen begrenzt.
- **Druckbarkeit:** Inseln, Überhänge, Wanddicke und freistehende dünne Stege jeweils CLEAN im regulären Prüflauf. Zehn einzelne Teile, alle fünf Produktionsplatten und die USB-Testplatte ohne Slicerwarnungen, Supports deaktiviert.
- **Pausen:** Die unabhängige [G-Code-Auswertung](fan-cable-magnets-2026-09-26/gcode-pauses.json) findet bei allen acht Taschen Bodenbahnen bis Z1,2, keine Überdeckung zwischen Z1,4 und Z4,4 und die erste Deckbrücke bei Z4,6. Auf beiden Platten steht die Pause vor der ersten Extrusion dieser Lage.
- **Material/Zeit:** 491,4 g und 16,5 h für die fünf angeordneten Produktionsplatten; 491,7 g und 17,4 h als Einzeljobs. Die neuen drei Teile einzeln: Kopf 225,6 g, Kassette 60,8 g, Rückdeckel 59,3 g. Zeiten enthalten keine manuelle Wartezeit beim Einlegen.
- **Nachweise:** [Exportbericht](fan-cable-magnets-2026-09-26/verification.json), [Slicerbericht](fan-cable-magnets-2026-09-26/slicer-summary.json), [Geometrievergleich](fan-cable-magnets-2026-09-26/change-scope.json), [Negativkontrollen](fan-cable-magnets-2026-09-26/regression-controls.json), [Dateiprüfsummen](fan-cable-magnets-2026-09-26/manifest.json). Das bisherige Generic-PETG-Profil bleibt unverändert; die im vorigen Audit beschriebene Auswahl eines passenden Profils für die tatsächliche XPETG-Rolle gilt weiterhin.

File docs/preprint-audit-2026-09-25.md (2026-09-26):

# FUMEX – Audit vor dem Druck

> **Korrektur nach dem realen Druck, 26.09.2026:** Der Nutzer hat fehlende Rückwände der Kopf-Magnettaschen und einen zu kleinen Lüfterkabeldurchlass festgestellt. Dieses Audit hatte nur die radialen Magnetwände geprüft und keinen Steckerweg durch den Durchlass. Die damalige Bewertung deckt diese beiden Stellen nicht ab. Die konstruktive Korrektur und erweiterte Prüfung stehen im [Nachtrag](fan-cable-magnets-2026-09-26.md).

**Stand: 25. September 2026 · geprüfter Commit: `4a11856`**  
Modell-SHA256: `152bdde96866f33b4eff4f85b12d2b582b43e39602d3c16a702fa8b487168946`

**Ergebnis: Kein neuer geometrischer Druck- oder Montageblocker gefunden. Die aktuelle Konstruktion ist für den nächsten Prototypendruck plausibel. Das ausgelieferte 3MF sollte mit deinem extrudr XPETG aber erst nach Wahl eines passenden Filamentprofils neu gesliced werden: Es enthält weiterhin 255 °C für Generic PETG.**

Das Audit verändert weder Modell noch Druckprofile. Es prüft die aktuellen STL-/3MF-Dateien, deren Übereinstimmung mit dem unmittelbar zuvor vollständig geprüften Export, zusätzliche Montageproben, kleinere Überhänge, kritische Wandbereiche und die sichtbare Form. Die identischen Slices wurden nicht unnötig wiederholt. Die Referenzberichte sind für diesen Stand als [Exportprüfung](preprint-audit-2026-09-25/verification.json) und [Slicerprüfung](preprint-audit-2026-09-25/slicer-summary.json) eingefroren; Dateiprüfsummen stehen im [Manifest](preprint-audit-2026-09-25/manifest.json).

## Vor dem Druckstart

| Punkt | Bewertung | Konkrete Konsequenz |
|---|---|---|
| **F1 – XPETG-Profil** | Vor dem Druck korrigieren | Materialfamilie PETG beibehalten, für die tatsächlich eingelegte XPETG-Rolle jedoch ein passendes Temperatur-/Kühlprofil wählen und neu slicen. |
| **F2 – USB-Passung** | Vor dem großen Base-Druck prüfen | Den vorhandenen kleinen USB-Passtest mit der echten Platine, Buchse und angelöteten Kabeln verwenden. Die Geometrie passt zur gemessenen Hülle; die obere Haltenase ist nicht gegen jedes reale Bauteil auf der Platine abgesichert. |
| **F3 – Knappe reale Passungen** | Beim ersten Zusammenbau prüfen | Werkzeug, PWM-Platine und beladener Deckel haben stellenweise nur etwa 0,2–0,3 mm modelliertes Spiel. Das berücksichtigt keine Druckabweichungen oder frei liegende Kabel. |
| **F4 – Betrieb und Wärme** | Vor längerem Betrieb prüfen | Lüfter/Filter auf Schleifen und Ladeelektronik im geschlossenen Gehäuse auf Erwärmung prüfen. Die bekannten Leistungs- und Temperaturgrenzen sind durch CAD-Prüfungen nicht erledigt. |

### F1: Das 3MF ist geometrisch aktuell, das Filamentprofil passt noch nicht zur gewählten Rolle

Beide PETG-Slots verwenden tatsächlich `Generic PETG @BBL H2S`. In `Metadata/project_settings.config` stehen **255 °C für erste und weitere Schichten**, **70 °C auf Textured PEI**, **12 mm³/s** Volumenlimit und **40–90 %** normale Bauteilkühlung. Vorhandener Diagnose-Gcode bestätigt die Temperatur mit echten Heizbefehlen; es handelt sich nicht nur um einen falschen Profilnamen.

Extrudr empfiehlt für XPETG Matt **210–240 °C**, **60–90 °C Bett**, **20–50 % Kühlung** und höchstens **12 mm³/s**. Bett und Volumenlimit passen; Temperatur und obere normale Kühlung weichen ab. Die Herstellerwerte sind ein Ausgangspunkt für das passende Profil, keine Garantie für die konkrete Rolle oder jeden Brückenbereich. [Extrudr, aktuelle Materialangaben](https://www.extrudr.com/en/gb/products/xpetg-matt/).

Die Einstufung als **PETG im AMS bleibt richtig** und ist von diesen Druckparametern getrennt. Das Audit erfasst die exportierten Dateien, nicht eventuell bereits abweichende Einstellungen in deinem offenen Bambu Studio. Die graue Rolle wurde dabei nicht als XPETG identifiziert; nur die tatsächlich damit belegten Slots entsprechend einstellen. Das 3MF enthält kein ausführbares Gcode und muss ohnehin gesliced werden. Die folgenden Gewichts-/Zeitangaben gelten für das bisherige Generic-PETG-/TPU-Profil.

## Geometrie und sichtbare Übergänge

Die Gesamtform wirkt weiterhin zusammengehörig: senkrechte Base, nach vorne geneigter Kopf, bewusst aufgesetzte Kassette, innenliegende Füße und eine ruhige Außenfläche. Die letzten Änderungen bleiben im Innenraum. Die neue Verbindung zwischen Akku-Anschlag und Wanne beseitigt einen freistehenden Wandabschnitt, ohne neue Außenkanten zu erzeugen.

- **Obere Kopfecken:** Der frühere Schnitt zweier Radien mit etwa 38° Normalensprung ist ersetzt. Die unabhängige Wiederholung der Eckprüfung findet an Kopf und Rückdeckel maximale benachbarte Facettenwinkel von **6,11–7,83°**, keine Kantenlänge oberhalb der Prüfgrenze. Das sind tessellierte Rundungen, keine mathematisch glatte STL-Oberfläche.
- **Kopf-/Base-Fuge:** Der frühere rund 1,26 mm breite Versatz wurde durch den 8 mm hohen Übergang ersetzt. Der beabsichtigte 15°-Knick, die Trennfuge und ihre Fasen bleiben sichtbar. Die gemeldete Spannendifferenz von etwa 0,408 mm stammt aus Schnitten **2 mm ober- und unterhalb** der Fuge; sie ist kein gemessener 0,408-mm-Spalt und kein Beweis vollständiger Tangentenstetigkeit.
- **Fasen:** Die fertigen Konturen werden mit BOSL2 verrundet beziehungsweise gefast. Die vorhandenen Profilprüfungen messen die tatsächlichen Exportkanten; die früher abgeschnittene seitliche Kassettenfase ist nicht wieder aufgetreten. Die bewussten Funktionskanten an Schraubensitzen, Griffmulden und Steckführungen bleiben.
- **Frontbefestigung:** Zusätzliche Querschnitts-/Materialproben finden keine früheren dünnen Resthäute vor den erhöhten Schraubdomen. Erhaltene Frontwand und der geschlossene Ring unter den Kappen sind vollständig vorhanden.
- **Magnettaschen:** Die geprüften radialen Materialringe von 1,21 mm bleiben erhalten. Reale Magnetmaße und Klebehalt sind weiterhin eine Passprobe.

[Zusätzliche Oberflächenmessungen](preprint-audit-2026-09-25/surface-evidence.json), [linker Frontschnitt](preprint-audit-2026-09-25/front-root-section-x25.5.svg) und [rechter Frontschnitt](preprint-audit-2026-09-25/front-root-section-x119.5.svg).

| Obere Ecke am exportierten Netz | Fuge zwischen Kopf und Base |
|---|---|
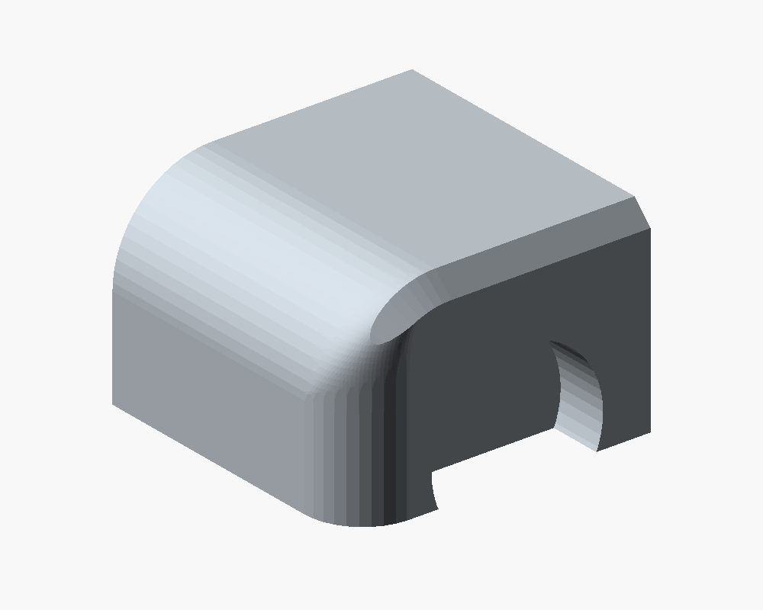
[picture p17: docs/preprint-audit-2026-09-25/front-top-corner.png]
Vergrößerte obere Ecke
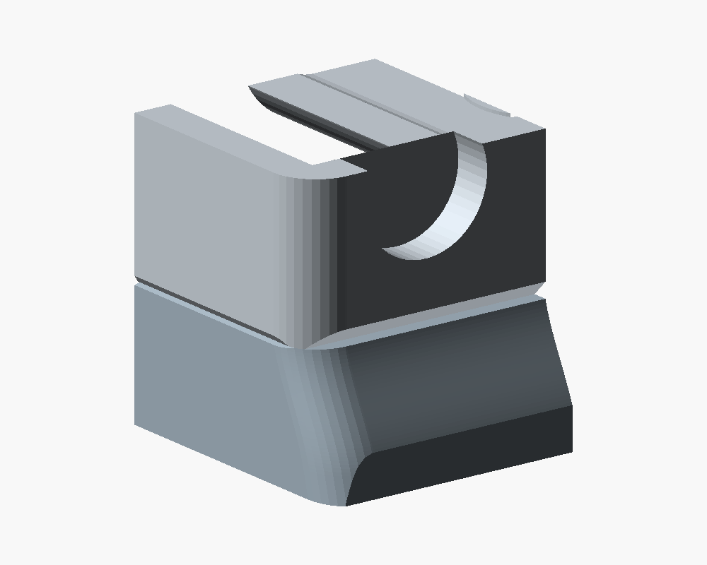
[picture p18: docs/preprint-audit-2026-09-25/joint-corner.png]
Vergrößerte Gehäusefuge
|  |  |

Die Ausschnitte sind zur Prüfung aufgeschnitten; die großen offenen Schnittflächen sind keine zusätzlichen Öffnungen am Bauteil.

## Montage und Befestigungen

| Bereich | Ergebnis am aktuellen Modell | Grenze der Aussage |
|---|---|---|
| Akku längs | Rechts 0,50 mm Nennspiel; linker Anschlag greift bei ungefähr 0,85 mm. Beide Seiten in neun verschobenen/angehobenen Lagen geprüft. | Schrumpfschlauch, tatsächliche Kabel und Drucktoleranzen sind nicht vollständig modelliert. |
| Akku nach oben | Zwei geschlossene Kabelbinder über den vorhandenen Bodenschlaufen; etwa 2,71 mm Abstand zum Kopf. 150-mm-Binder haben rund 29,55 mm Reserve für Verschluss und Ende. | Die Binder liegen direkt über dem gesamten Pack einschließlich BMS. Nur handfest anziehen; keine Druckentlastung der Elektronik behauptet. |
| Neuer Anschluss zur Wanne | 3 mm breiter, durchgehend am Boden angebundener Steg. Material über dem ehemaligen Spalt und in beiden Anschlüssen vollständig vorhanden. | Zur Deckelvorderkante bleiben diagonal 0,283 mm, vertikal über der Wannenwand 0,4 mm. Festigkeit und Kriechen wurden nicht physisch gemessen. |
| Wannendeckel | Genau zwei M3×8 in Ruthex-Inserts. Vollständiger Ausbau mit montiertem Lademodul, Kühlkörper und Binder besteht; nach dem ersten Hub mindestens 0,20 mm Abstand. | Kopf, Akku, Schalter und Deckelschrauben vorher entfernen; Kabelschlaufen müssen den beschriebenen Weg mitmachen. |
| USB-PD-Modul | Offener Einbauweg, mittiger unterer Anschlag und obere Sicherung. Einsetzen zusätzlich mit bereits montiertem PWM, Poti und LEDs kontinuierlich geprüft. Beide Kabelseiten bleiben frei. | Die gemessenen 4,3 mm beschreiben die Modulhülle einschließlich Bestückung. Tragfähige, bauteilfreie Kontaktfläche unter der oberen Nase am Original prüfen. |
| Kopf auf Base | Vier M3×8 mit direkter Gegenauflage, zwei vorne und zwei hinten, alle gleich nach unten. Je Schraubenkopf etwa 16,44 mm² Auflage. Vorne 1,6 mm tragender Sitz, 6,4 mm Eindringtiefe und 0,6 mm Bodenreserve. | PETG-Klemmkraft, Insert-Auszug und Langzeitkriechen sind keine rein geometrischen Eigenschaften. |
| Schraubenzugang | Frontweg der modellierten kleinen Ratsche mit 25-mm-Bit frei, begrenzter Schwenkweg mit mindestens 0,902 mm Reserve. | Wera-Maße sind angenommen. Hinten rechts hat der modellierte Schraubendreher lokal nur 0,325 mm Abstand zur Wand. |
| PWM-Platine | Zwei Bodenschrauben und ihre Auflagen stimmen. Zusätzliche Wegprüfung findet nach dem Freiheben mindestens etwa 0,192 mm im ersten Kippabschnitt. | Beim anfänglichen Hub schneiden zwei winzige Ecken der konservativen Anschluss-Hülle die Bosskanten, maximal 0,0000517 mm³. Das liegt unter der Prüftoleranz, ist aber kein absolut kollisionsfreier Nachweis für die reale Verkabelung. |
| Ladeplatine | Nur das kühle OUT-Ende gehalten; 4,7 mm Abstand zwischen Halter und Kühlkörper. Vorder- und Rückseite besitzen offene Luftwege. | Binderverlauf, Lötstellen und Kabel am echten Modul prüfen; freie Luftwege beweisen keine ausreichende Kühlung. |
| LEDs | Zwei geschlossene 1,8-mm-Fronthäute, 12 mm Mittenabstand, Einsetzen von innen möglich. | Sichtbarkeit durch anthrazitfarbenes XPETG ist ungeprüft. |
| Filterstütze | Verstärktes Kreuz sitzt in vier Aufnahmen und wird vom Lüfterrahmen gehalten. Zentral 5 mm Rahmenabstand, ungünstigster nominaler Anschlag 4,8 mm. | Den echten Rahmenkontakt aller vier Enden prüfen. Flexible Matte, lose Fasern und Biegung bleiben unmodelliert. |

**Poti-Achshöhe zusätzlich prüfen:** Die gemeinsame Messnotiz nennt nur ungefähr 6,0 mm über der PWM-Platine; das Modell verwendet 6,3 mm bei 0,2 mm radialem Buchsenspiel. Falls die echte Höhe genau 6,0 mm ist, wäre das nominelle Spiel um etwa 0,1 mm überschritten. Das ist eine konkrete Messunsicherheit, kein bestätigter Passungsfehler. Vor dem Festschrauben prüfen, dass die Platine flach auf beiden Bossen und den Auflagen liegt und das Poti frei sitzt.

Der Schnappmechanismus des Schalters und der Verschlusskopf des Ladeplatinen-Binders sind nicht vollständig modelliert. Den beladenen Deckel deshalb vor endgültiger Verdrahtung probeweise einsetzen und herausnehmen, einschließlich erreichbarer Schalterclips und tatsächlich platzierter Kabel/Binderköpfe.

Die örtliche Verformung der weichen Filtermatte über den vorderen Schraubenköpfen ist die ausdrücklich gewählte Lösung: maximal **2,75 mm**, auf zwei Bereiche begrenzt. Sie ist kein versehentlicher harter Teilekontakt. Die beiden früheren Akku-Auflagen sind auch im Druckprojekt vollständig entfernt.

Die Ballastwanne hat keine große offene Ecke mehr. Es bleiben konstruktive Fugen von ungefähr 0,25 mm seitlich beziehungsweise 0,4 mm über der Wand: grobe Metallreste werden zurückgehalten, feine Späne oder Metallpulver sind dadurch nicht zuverlässig eingeschlossen.

[Zusätzliche mechanische Proben](preprint-audit-2026-09-25/mechanical-probes.json).

## Druckbarkeit und Dateikonsistenz

| Prüfung | Ergebnis |
|---|---|
| Drucknetze | 10 gültige Netze: 8 Produktionstypen und 2 optionale USB-Testtypen; je ein geschlossener Körper, keine entarteten Dreiecke. |
| Tatsächliche Teilezahl | 11 Produktionsteile einschließlich 4 Füßen; keine Akku-Auflagen. |
| STL → 3MF | Rücktransformierte Netzkoordinaten stimmen innerhalb von 0,000006 mm überein; keine stillen Reparaturen. |
| Lage und Bauraum | Alle Teile in vorgesehener Drucklage auf Z0, innerhalb des H2S-Bauraums; nur Drehungen in der Plattenebene. Mindestens 2 mm Abstand zwischen Objekten. |
| Platten | Kopf/Deckel/Kreuz; Base/Rückdeckel; Kassette/Knopf; vier TPU-Füße. Separates 3MF für die zwei USB-Testteile. |
| Standardanalysen | Inseln, Überhänge, Wandstärke und dünne freistehende Stege ohne Befund bei den festgelegten Schwellen. |
| Zusätzliche Überhangprüfung | Bei 5 statt 100 mm²: 31 kleine Bereiche an den Produktionsteilen, 2 Wiederholungen im USB-Testboden. Keine neue freischwebende Geometrie. |
| Slicer | 10 Einzelnetze, 4 Produktionsplatten und USB-Testplatte ohne Warnungen und ohne Supports gesliced. |
| Prozess | 0,20 mm, 4 Wände, 5 Deck-/Bodenschichten, 20 % Gyroid; Kreuz und Füße 100 %. Jede Platte verwendet nur ein Filament. |
| Aktuelle Schätzung | 475,9 g / 15,8 h als angeordnete Platten; 476,3 g / 16,8 h als Einzeljobs. USB-Passtest etwa 10,0 g / 62 Minuten. |

Die kleinen Überhänge sind nicht wegdefiniert: Der größte ist die **10,75-mm-Brücke unter dem USB-Sitz** mit etwa 60 mm². Dazu kommen Griffmulden, kurze Führungsansätze, Tunnel, Insertdächer und Öffnungen. Sie sind supportfrei angelegt; ihre Unterseiten und Maßhaltigkeit am ersten Druck prüfen, besonders nach dem Wechsel zum XPETG-Profil.

Die Dickenanalyse ist eine Stichprobe mit Flächen- und Kantenfiltern. Beispielsweise bleiben am Kopf 65.253 gültige Messstrahlen von 65.414; einzelne numerische Strahlfehler sind bekannt. „Ohne Befund“ bedeutet deshalb nicht, dass jeder winzige Rand mindestens 1,2 mm dick ist. Die belasteten Schrauben-, Stop- und Halterbereiche werden zusätzlich separat geprüft.

**Prüfzahl präzisiert:** 34 Baugruppenkörper ergeben 561 mögliche Paare. Davon werden **533** regulär auf Kollision geprüft; **28** sind begründete Montagezustände oder beabsichtigte Kontakte. Kritische Ausnahmen für PWM-Schraubgewinde und flexible Matte sind zusätzlich begrenzt. Akku, USB und der neue Wannenanschluss besitzen keine pauschale Kollisionsausnahme. [Datei- und 3MF-Nachweise](preprint-audit-2026-09-25/artifact-evidence.json).

## Stabilität und Betrieb

Die bestehende Rechnung ergibt mit etwa 189 g Ballast **28,3 mm vordere Standreserve und 21,0° Kippwinkel** bei 1,013 kg. Eine zusätzliche Rechnung mit den aktuellen Slicer-Massen der Druckteile statt der pauschalen effektiven Dichte ergibt **27,5 mm, 20,2° und 1,090 kg**. Der Schwerpunkt bleibt deutlich innerhalb der geforderten 15-mm-Reserve; die veröffentlichte Massenschätzung ist aber rund 77 g niedriger als dieser alternative Ansatz. Beide Rechnungen verwenden vereinfachte Masseverteilungen und geschätzte Kaufteilmassen.

Mit halbem Ballast sinkt der Winkel im bisherigen Modell auf etwa 17,5°, ohne Ballast auf etwa 13,7°. Das ist eine Sensitivitätsrechnung, kein physischer Kipptest und keine Aussage über Zug am USB-Kabel. [Berechnung](preprint-audit-2026-09-25/tipping-sensitivity.json).

Die bekannte elektrische Reserve bleibt offen: Der P12 Pro PST ist mit **0,33 A bei 12 V** spezifiziert. Die Projektnotizen nennen für das LFUPSMA-Modul **0,32 A**; dessen reale Ausgangsleistung wurde in diesem Audit nicht neu gemessen oder unabhängig vom vorhandenen Modulnachweis bestätigt. Ein problemloser Dauerbetrieb bei Vollgas ist damit nicht nachgewiesen. [ARCTIC-Datenblatt](https://www.arctic.de/media/2c/de/c6/1750758983/Spec_Sheet_P12_Pro_PST_EN.pdf).

Die Luftkanalprüfung zeigt freie Wege auf beiden Seiten des Ladeboards, keine Temperaturmessung. XPETG-Materialkennwerte ersetzen diese Messung ebenfalls nicht; Extrudr nennt aktuell 67 °C HDT/B unter einer definierten Prüflast, keine pauschale zulässige Dauergebrauchstemperatur für diese dünnen Halter. [Extrudr](https://www.extrudr.com/en/gb/products/xpetg-matt/). Filter-Druckverlust, Absaugwirkung und tatsächliches Schleifen bei voller Drehzahl bleiben Funktionsprüfungen am aufgebauten Gerät.

## Praktischer Ablauf

1. In Bambu Studio das passende Profil für die tatsächlich eingelegte XPETG-Rolle wählen, Materialfamilie PETG lassen und neu slicen.
2. Zuerst den vorhandenen USB-Passtest mit echter Platine und Kabeln zusammenstecken: Einschub, oberen Halt und seitliche Kabelwege prüfen.
3. Danach die Base aus dem geprüften Stand drucken. Die letzte Verstärkung änderte ausschließlich ihre Produktionsgeometrie; die übrigen passenden Teile müssen dafür nicht neu gedruckt werden.
4. Beim Zusammenbau Binder nur handfest, knappe Wege ohne Gewalt und alle vier Filterstützen auf tatsächlichen Rahmenkontakt prüfen. Abschließend Lüfterlauf und Erwärmung im geschlossenen Aufbau testen.

Es ist derzeit keine weitere CAD-Änderung aus diesem Audit zwingend abgeleitet. Der offene Punkt vor dem XPETG-Druck ist das Profil; die restlichen genannten Grenzen betreffen Passung und Betrieb des realen Prototyps.

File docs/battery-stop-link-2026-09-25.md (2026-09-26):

# Battery end-stop connection — 2026-09-25

The battery's axial stop is joined directly to the ballast trough front wall. A 3 mm thick web closes the former 2 mm gap and grows continuously from the base floor. Its top slopes down towards the trough so the removable ballast lid stays clear.

The web spans x76.1..79.1 and y49.6..54. Its top descends at 45 degrees from z29 to z25.6 at y53, then extends 1 mm into the trough wall. The original rounded and beveled battery contact wall remains; the connection is added at its rear end. Nominal axial pack clearance stays 0.5 mm. The top is below the BMS and cable exit.

Only the base production geometry changes. A mesh comparison against commit `1b54fd944d2346e6f1fc193c08e591844d3a9e4e` finds 154.869 mm³ added and no material removed, with unchanged outside dimensions. The other seven production STLs are byte-identical and both USB fit pieces are geometrically unchanged. The connection prints with the base without supports; the lid remains a separate removable part. This provides a second attachment for the stop but does not establish an ultimate strength or creep rating.

## Verification

Source SHA-256: `152bdde96866f33b4eff4f85b12d2b582b43e39602d3c16a702fa8b487168946`.

The [assembly report](verification.json) passes with ten closed single-body print meshes, zero degenerate faces, 443 coaxial feature pairs, 561 assembly pairs and ten standard service paths. Independent material probes cover the full height of the former gap and both stop/trough junctions: all report 100% material. The same gap probe rejects the preceding base from commit `1b54fd944d2346e6f1fc193c08e591844d3a9e4e`, where only the floor fills about 0.67% of it.

Battery clearance remains 0.5 mm in the installed pose, and all nine shifted/lifted axial-retention checks pass. The upper BMS/cable corridor has no overlap. The actual connection has 0.283 mm minimum distance to the lid's front edge across its diagonal top (0.4 mm vertically over the trough wall). Battery, head, PWM and complete loaded-lid removal remain clear; loaded-lid clearance after the initial lift remains at least 0.20 mm.

All ten meshes are CLEAN at the configured thresholds in [islands](battery-stop-link-2026-09-25/islands.json), [overhangs](battery-stop-link-2026-09-25/overhangs.json), [thickness](battery-stop-link-2026-09-25/thickness.json) and [fins](battery-stop-link-2026-09-25/fins.json). All ten individual slices, four production plates and the USB fit plate pass without slicer warnings or supports. The [slicer report](slicer-summary.json) gives 119.472 g for the base, 475.9 g / 15.8 h for arranged production and 476.3 g / 16.8 h for individual jobs. The USB fit plate stays at 10.0 g / about 62 minutes.

The static assembled estimate is 1012.8 g, with a 28.3 mm front margin and 21.0° tip angle. Both 3MF projects, all twelve documentation views and both viewer copies are rebuilt. Shared scripts match the print-project skill. The local file viewer requires manual reload because automatic refresh is blocked.

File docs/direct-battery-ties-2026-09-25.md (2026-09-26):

# Direct battery cable ties — 2026-09-25

The two loose printed bridges between the battery and cable ties are removed at the user's request. The ties now follow the shrink-wrapped pack directly and use the same two floor loops. No replacement spacers are added. The remaining printed parts, including the base and head, retain their geometry.

The removed bridges were load spreaders: they bore on the cell shoulders above a free channel for the BMS. The direct strap envelope instead includes the measured full-length side board (approximately 20 mm wide and 4 mm thick) as part of the wrapped pack. It does not demonstrate pressure isolation of that board. Tighten gently by hand, without crushing the wrap or electronics, and cut the ties for battery removal.

The print set now has eight production types and eleven pieces, including the four feet, plus two optional USB fit types. The bridge STL, plate instances, assembly body and viewer item are removed. The shallow existing head reliefs stay compatible with previously printed housing parts.

## Verification

Source SHA-256: `b918a76215a4885e8c215c0fe97e16c3aa9fbab6748c803e2b0783f3ac3178f7`.

The [assembly report](verification.json) passes with ten closed single-body print meshes, zero degenerate faces, 443 coaxial feature pairs, 561 assembly pairs and ten standard service paths. The complete PWM, USB and loaded-lid paths also pass. The two ties remain in place during the 60 mm head-removal check.

The direct ties clear the head by 2.709 mm. Each band needs about 120.448 mm along its centreline, leaving 29.552 mm for buckle and tail with a nominal 150 mm tie. The existing tunnels have 0.4 mm width and 0.6 mm thickness clearance; all floor, roof and side-wall material probes pass. The battery cable corridor stays clear.

The model deliberately reports cell and BMS contact separately: at 0.1 mm upward pack movement, contact is with the BMS envelope only (3.600053 mm³ per band); at 0.3 mm, contact also includes the cell (0.929589 mm³). This is direct pack restraint, not the previous bridge's load isolation. Clamp force, shrink-wrap integrity and flexible strap behaviour have not been tested physically.

All ten meshes are CLEAN at the configured thresholds in [islands](direct-battery-ties-2026-09-25/islands.json), [overhangs](direct-battery-ties-2026-09-25/overhangs.json), [thickness](direct-battery-ties-2026-09-25/thickness.json) and [fins](direct-battery-ties-2026-09-25/fins.json). Thickness sampling retains 65,253 of 65,414 head rays with the known numerical warnings. All ten individual slices, four production plates and the USB fit plate pass without slicer warnings or supports. The [slicer report](slicer-summary.json) gives 475.8 g / 15.8 h for arranged production and 476.2 g / 16.8 h for individual jobs. The USB fit plate remains 10.0 g / about 62 minutes.

All eight remaining production types and both USB test pieces are geometrically unchanged from commit `2beb14ea21e3c4499f302b4efcb3e42927a42121`. Seven production STLs and the fit lid are byte-identical. The base and fit base have different STL serialization but zero bidirectional Boolean difference and identical bounds. No housing reprint is required for this change.

The static assembled estimate is 1012.6 g, with a 28.3 mm front margin and 21.0° tip angle. Both 3MF projects, all twelve documentation views and both viewer copies are rebuilt. Shared scripts match the print-project skill. The local file viewer requires manual reload because automatic refresh is blocked.

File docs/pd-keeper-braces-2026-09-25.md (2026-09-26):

# Reinforced PD-trigger keeper foot — 2026-09-25

Two triangular cheeks now brace the lid-mounted USB-PD keeper at its foot. Each extends 2 mm beyond the 4 mm stem, overlaps it by 0.2 mm, rises 8 mm above the lid, and runs 8 mm rearwards. The widened and lengthened foot distributes plug loads into the lid. The sloped tops print without support.

The cheeks occupy x102..104.2 and x107.8..110, with feet from y53.2 to y61.2 and upper tips at z37. The keeper's PCB-edge stop, upper return and the two side cable exits remain unchanged. The ribs end below the wire corridors; they are integral to the lid, with no separate fasteners or glue.

Changed print geometry: `ball_lid` and the matching `usbc_fit_lid` coupon. Base and other production parts keep their existing geometry.

## Verification

Source SHA-256: `7e90185f184b1b34f1a70f9b1028df8e681000716e65b3594a7d6f6cf688a46d`.

The [assembly report](verification.json) passes with eleven closed single-body print meshes, zero degenerate faces, 445 coaxial feature pairs, 595 assembly pairs and ten standard service paths. Both ribs have complete material at their feet, through the webs, into the stem and in the lid beneath them. The new probes reject the preceding unbraced lid.

All six cable corridors stay clear. The lower PCB stop, upper return and 2.9° lift-capture check remain valid. The complete loaded-lid service path passes with at least 0.20 mm clearance after the initial lift. The keeper clearance probe includes both entire ribs. The updated USB fit coupon also passes its seat, stop and insertion checks.

All eleven meshes are CLEAN in [islands](pd-keeper-braces-2026-09-25/islands.json), [overhangs](pd-keeper-braces-2026-09-25/overhangs.json), [thickness](pd-keeper-braces-2026-09-25/thickness.json) and [fins](pd-keeper-braces-2026-09-25/fins.json). All eleven individual slices, four production plates and the USB fit plate pass without warnings or supports. The [slicer report](slicer-summary.json) gives 8.43 g for the lid, 477.4 g / 15.9 h for arranged production and 478.0 g / 17.2 h for individual jobs. The USB fit plate is 10.0 g / about 62 minutes.

The static assembled estimate is 1014.0 g, with a 28.3 mm front margin and 21.0° tip angle. These checks establish geometry and printability; physical keeper strength, PETG creep and cable-lever forces have not been measured.

STLs, both 3MF projects, all twelve documentation views and both viewer copies are rebuilt. Shared scripts match the print-project skill. The local file viewer requires manual reload because automatic refresh is blocked.

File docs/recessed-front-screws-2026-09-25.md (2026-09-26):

# Shallow front screw recesses — 2026-09-25

The two front M3 × 8 heads now sit in flat-bottom Ø6.4 × 0.7 mm pockets, matching the rear recess depth. Their upper 0.95 mm remains exposed. The screw axes and the base geometry are unchanged from the [straight-screw revision](straight-front-clamp-2026-09-25.md); only the production head geometry changes.

Front bearing thickness is 1.6 mm, directly backed by the base. Each screw reaches 6.4 mm into its 7 mm pocket, leaving 0.6 mm before the blind end. Rear bearing thickness remains 2.3 mm, with 5.7 mm penetration. The cap tops stay at local z62.3 and the front bearing faces move to z61.6. The intake cutter preserves the complete cap rims and their outer bevels, avoiding a thin remnant beside each pocket.

The soft mat's local geometric allowance drops from 3.45 to 2.75 mm over the screw heads. The printed caps still reach 1.8 mm into its nominal envelope. The tool access, PWM service sequence and fastener count stay the same.

## Verification

Source SHA-256: `fd2fbc0cf9d9d500c3e94c05c317dcb5912706031bdcfc5565e9813130792e07`.

The [assembly report](verification.json) passes: eleven closed single-body meshes, zero degenerate faces, 445 coaxial feature pairs, 595 assembly pairs and ten standard service paths. Both front recesses measure 0.699999 mm at the exported mesh. Bearings, pocket rims, direct backing faces, insert walls and blind floors have 100% material in the probes. The complete PWM service path and ratchet entry/working stroke pass; the assumed ratchet envelope retains a conservative 0.902 mm swing clearance.

All eleven meshes are CLEAN in [islands](recessed-front-screws-2026-09-25/islands.json), [overhangs](recessed-front-screws-2026-09-25/overhangs.json), [thickness](recessed-front-screws-2026-09-25/thickness.json) and [fins](recessed-front-screws-2026-09-25/fins.json). All eleven individual slices, four production plates and the USB fit plate pass without warnings or supports. The [slicer report](slicer-summary.json) gives 477.3 g / 15.9 h for arranged production, 477.8 g / 17.2 h for individual jobs, and 9.9 g / about 62 minutes for the USB fit plate.

Nominal mat overlap is 280.800581 mm³ from the caps plus 98.748029 mm³ from the screws, totalling 379.548611 mm³. The two local zones permit at most 1.8 mm and 2.75 mm depth respectively, with a tightened total-volume gate of 400 mm³. Physical mat forces, print fit, PETG creep and actual ratchet dimensions remain unverified.

The base has zero geometric difference from commit `39c6441` in the Boolean mesh comparison. Only the head production geometry changes. Both 3MF files, twelve documentation views and both viewer copies are rebuilt. The local file viewer needs a manual reload; automatic refresh remains blocked. Shared scripts are unchanged and match the print-project skill.

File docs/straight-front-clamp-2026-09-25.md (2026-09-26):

# Straight front head-to-base screws — 2026-09-25

This revision predates the [0.7 mm front recesses](recessed-front-screws-2026-09-25.md); its recorded dimensions and results describe the fully exposed front heads.

All four head screws are M3 × 8 and point down in the same direction into the base. The front inserts sit in raised bosses directly behind the front wall. Their screw heads are exposed above flat seats, with no enclosing plastic wall. This supersedes the [angled front arrangement](front-clamp-2026-09-25.md).

## Geometry and assembly

| Pair | Insert entry in the untilted head frame (mm) | Direction | Screw | Bearing thickness | Engagement |
|---|---|---|---|---|---|
| Front left | 25.5, 6.5, 60 | 0, 0, −1 | M3 × 8 | 2.3 mm | 5.7 mm |
| Front right | 119.5, 6.5, 60 | 0, 0, −1 | M3 × 8 | 2.3 mm | 5.7 mm |
| Rear | x25/131, y66, z48 | 0, 0, −1 | M3 × 8 | 2.3 mm | 5.7 mm |

All axes follow the joint normal, exactly as the rear pair did; the housing's existing 15° tilt is unchanged. Front bosses are Ø9.2 × 9 mm, with Ø4 × 7 mm Ruthex pockets and 2 mm closed bottoms. Short hull roots join them to the front wall. Each head seat has a complete bearing ring and a directly contacting base face behind it.

The head's Ø12.2 mm front caps join the lower filter tube between local z59.5 and z62.3. Their Ø9.7 mm guide openings provide 0.25 mm clearance around the bosses, with 1.25 mm radial material closing the surrounding path. The outer bevel ends at the flat seat. No printed material encloses the exposed screw head above it. Two small rectangular front reliefs below local z57.5 remove thin remnants around the supporting roots; at least 1.254 mm front wall remains above them, with the filter-tube floor closed. The intake opening trims the frontmost sector of the cap bevel; the complete bearing ring remains intact.

The nominal mat begins at z60.5. The caps extend 1.8 mm into that envelope and the bare screw heads 3.45 mm. The user accepts local bending of the flexible mat; contact is limited to these two regions and checked by location, depth and volume. This is a geometric allowance, not a model of mat force or stiffness.

Remove the cassette and mat for front fastening. Enter through the intake with the small Wera ratchet and a 25 mm TX10 bit fitted directly into it. Install the rear screws before the fan-and-cover assembly. Refit the mat with its lower edge bent locally over the front heads.

The complete PWM removal path now uses two pitching stages: after the initial lift and shaft retraction, tilt the rear up to 20°, withdraw another 7.9 mm, then continue to 35° before the existing lift and sideways extraction. The earlier direct pitch to 35° collided with the new front boss. Remove the head, battery, switch and loaded ballast lid first, followed by the knob and both PCB screws. Reverse this route for installation.

Total hardware: **14 M3 × 8, four M3 × 30 and 18 Ruthex RX-M3x5.7 inserts**, plus the existing two 2.5 × 8 thermoplastic PCB screws.

## Verification

Source SHA-256: `b45799ece7eedaee3dce09ec6baf3b646c45baf648104f66f1b36f7e49f55787`.

The [assembly report](verification.json) passes with eleven closed single-body meshes, zero degenerate faces, 427 coaxial feature pairs, 595 assembly pairs and ten standard service paths. All four screw-bearing rings, backing rings, insert-wall rings and blind-floor probes contain 100% material; all nominal clamping gaps are zero. The complete 532-pose PWM path passes, including both separate screw withdrawals and knob removal, with a maximum numerical overlap of 0.000052 mm³.

All eleven meshes are CLEAN in [islands](straight-front-clamp-2026-09-25/islands.json), [overhangs](straight-front-clamp-2026-09-25/overhangs.json), [thickness](straight-front-clamp-2026-09-25/thickness.json) and [fins](straight-front-clamp-2026-09-25/fins.json), at the configured thresholds. The base uses the normal CGAL fallback; no mesh repair is applied.

The conservative ratchet model assumes a Ø22 × 14 mm head, 87 mm overall length, 14 mm handle width and 2 mm engagement of the 25 mm bit. Tool dimensions are not measured. Continuous entry and seating sweeps are free; the ±6° swing has 0.969 mm sampled clearance and a conservative 0.902 mm lower bound between angular samples. The cassette and mat are removed for this operation; the actual housing and installed electronics remain obstacles.

Nominal mat contact is 313.069 mm³ for the two printed caps and 108.392 mm³ for the screw heads, together 421.460 mm³. The independent gate allows less than 450 mm³ only in the two specified local zones, with maximum depths of 1.8 and 3.45 mm respectively. No flexible-force, physical tool-fit, creep or strength validation is claimed.

All eleven individual slices, four production plates and one USB fit plate pass without warnings or supports. The [slicer report](slicer-summary.json) gives **477.3 g / 15.8 h** for the arranged production project and 477.9 g / 17.2 h for individual jobs. The USB fit plate remains 9.9 g and about 62 minutes. Static assembled estimate: 1013.9 g, 28.3 mm front margin and 21.0° tipping angle; bought-part masses remain partly estimated.

The changed production parts are the base and head; use the matching current pair. STLs, both 3MF projects, all twelve documentation images and both viewer copies are regenerated. The local viewer tab requires a manual reload because browser policy blocks automatic refresh.

Shared scripts remain identical to the print-project skill. Skill commit `00197d8` records the thin shell remnants created by raised-boss release windows and the need to check them in the print pose.

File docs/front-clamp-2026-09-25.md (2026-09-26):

# Angled front head-to-base screws — 2026-09-25

Historical revision: superseded by the [straight front screws](straight-front-clamp-2026-09-25.md). The measurements below describe the earlier angled arrangement.

All four head screws now fasten down into the base. The front pair uses M3 × 16 at 40° outwards from the downward joint normal; the rear pair retains the M3 × 8 mounting from the [rear-clamp revision](head-clamp-2026-09-25.md). The old high front tongues, front-face screw holes and mating windows are removed.

The user accepts bending the soft filter mat locally over the front screw heads. The sealed head wells end 2.7 mm above the nominal bottom of the mat; the screw heads overlap that nominal envelope by about 2.5 mm. Only these two small contact regions are allowed. Both edges of each well mouth are chamfered. This is a permitted local deformation envelope, not a simulation of fleece stiffness or sealing pressure.

## Fasteners and assembly

| Pair | Insert entry in the untilted head frame (mm) | Direction | Screw | Clamped material | Engagement |
|---|---|---|---|---|---|
| Front left | 9.1, 10, 52 | −0.6427876, 0, −0.7660444 | M3 × 16 | 10.3 mm | 5.7 mm |
| Front right | 135.9, 10, 52 | +0.6427876, 0, −0.7660444 | M3 × 16 | 10.3 mm | 5.7 mm |
| Rear | x25/131, y66, z48 | 0, 0, −1 | M3 × 8 | 2.3 mm | 5.7 mm |

Each screw head bears on a complete ring backed directly by the base. Front bosses are Ø9.2 × 9 mm with Ø4 × 7 mm insert pockets and 2 mm closed ends. Their full inclined contact faces remain intact; support roots meet the side walls without obstructing the battery or PWM board. The head wells close the space between the filter tube and the head floor around each shaft.

The base print envelope is now 145 × 74 × 57.3 mm; the head is 145 × 145 × 70 mm in print orientation.

The total hardware becomes **12 M3 × 8, two M3 × 16, four M3 × 30 and 18 Ruthex inserts**, plus the two existing 2.5 × 8 thermoplastic PCB screws.

Remove the cassette and mat for front fastening. Insert a 25 mm TX10 bit directly into the small Wera ratchet and enter through the front. The rear screws go in before the fan-and-cover assembly. Refit the mat with its lower edge bent slightly over the front wells.

## Tool access

The linked tool is the Wera Tool-Check PLUS 1 (05049055001), containing the 8001 A / Zyklop Mini 1, a 25 mm TX10 bit and a ratchet with 6° return angle. See the official [set data sheet](https://hybris-media.wera.de/en/05049055001.pdf) and [ratchet data sheet](https://hybris-media.wera.de/download/pdfgenerator-datasheets/en/05073230001.pdf).

The access model assumes a Ø22 × 14 mm ratchet head, 14 mm handle width and 2 mm bit engagement. These dimensions are not measured. The complete 25 mm bit remains represented above the screw outer face, with a Ø7.4 mm envelope around its hex shank. The head starts 9 mm behind that face. The handle points forwards through the intake.

The check uses the actual exported housing and installed parts. It verifies the complete tool at the screw, continuous convex-piece swept volumes for entry and seating, and a ±6° handle swing with a bound between angular samples. The mat and cassette are removed; electronics, support cross and fan remain obstacles.

## Verification

Source SHA-256: `168a78f6f4feee21a4a681cc80e19e1eff23b0a5b94902d21c74bd88b72ffc9a`.

The [assembly report](verification.json) passes with 11 closed single-body meshes, zero degenerate faces, 445 coaxial feature pairs, 595 assembly pairs and 10 service paths. All four bearing rings, direct backing rings, insert-wall rings and blind-floor probes contain 100% material; every nominal clamping gap is zero. The original complete PWM service path remains unchanged and passes with a maximum numerical overlap of 0.000052 mm³.

- All 11 meshes are CLEAN in [islands](front-clamp-2026-09-25/islands.json), [overhangs](front-clamp-2026-09-25/overhangs.json), [thickness](front-clamp-2026-09-25/thickness.json) and [fins](front-clamp-2026-09-25/fins.json), at the configured thresholds.
- Ratchet entry and seating sweeps have zero collision. The ±6° swing has 0.442 mm sampled minimum clearance and a conservative 0.376 mm lower bound between samples, using the assumed tool envelope.
- Nominal mat overlap is 248.438 mm³ for the head wells and 42.380 mm³ for the screw heads, together 290.818 mm³. The independent gate limits this to the two specified regions, 2.7 mm maximum depth and 330 mm³ total. These are permitted local contacts, not a stiffness or compression-force result.
- Static assembled estimate: 1015.5 g, 28.2 mm front margin and 21.0° tipping angle. Bought-part masses remain partly estimated.

All 11 individual slices, four production plates and the USB test plate pass without warnings or supports. The arranged production project uses 478.8 g and 15.9 hours; individual jobs total 479.4 g and 17.3 hours. The USB fit project remains 9.9 g and about 62 minutes. See the [slicer report](slicer-summary.json).

The updated production geometry is the base and head; use them as a matching pair. The back cover retains the preceding revision's rear-screw clearances. STLs, both 3MF projects, all documentation images and both viewer copies are regenerated. The local viewer tab needs a manual reload because browser policy prevents refreshing it automatically.

Shared scripts remain identical to the skill. Skill commit `32581a6` records angled-boss release clearance, checking nearby PCB service paths, complete ratchet envelopes and bounded flexible contacts. No physical strength, creep, tool-fit or mat-force validation is claimed.

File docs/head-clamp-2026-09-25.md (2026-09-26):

# Direct head-to-base clamping — 2026-09-25

The front fasteners in this snapshot are superseded by [the angled front mounting](front-clamp-2026-09-25.md). The rear mounting remains unchanged.

The previous screw heads did bear on complete rings: a 5.7 mm head over a 3.4 mm clearance hole gives 1.15 mm radial overlap and about 16.44 mm² nominal bearing area. However, a 0.25 mm gap behind each seat interrupted the direct compression path to the insert tongue. Tightening would first deform a seat or tongue. The earlier checks proved head contact, insert engagement and printable geometry, but did not establish a rigid clamp stack or retained preload.

At the user's request, the rear screws now run down through the head floor directly into the base rim. Rear horizontal tongues are removed. The front screws retain their accessible front entry, with the axial gap removed and direct bearing against the base tongues. Guiding clearance remains on the non-clamping faces.

The revised check measures the material immediately on both sides of each clamped interface, as well as the head bearing ring, insert walls and bottom, screw engagement and tool access. This establishes a direct geometric load path; tightening torque, PETG creep and ultimate strength still require physical validation.

The joint illustration now shows the assembled relationship. In the previous illustration the head was lifted while the screws stayed in their installed positions, which obscured their actual bearing surfaces.

## Final joint dimensions

| Pair | Insert entry, local head coordinates (mm) | Screw direction | Material below head | M3 × 8 engagement |
|---|---|---|---|---|
| Front | x7.5/137.5, y4.5, z68 | Towards the rear | 2.05 mm | 5.95 mm |
| Rear | x25/131, y66, z48 | Down, normal to the joint | 2.30 mm | 5.70 mm |

Rear bosses are Ø10 × 9 mm, with Ø4 × 7 mm Ruthex pockets and 2 mm closed ends. The rear screw seats are at local z50.3. All four interfaces have zero nominal axial gap; material probes on both sides are completely filled. The [regression evidence](head-clamp-2026-09-25/backing-regression.json) shows that these same front-backing probes find 0% material in the previous published base and 100% in the revised base.

The base, head and back cover are updated. The cover's forward lip now has small round clearances around the rear screw heads instead of the former large tongue clearances. Screw and insert quantities remain unchanged. Assemble both front screws with the cassette removed and both rear screws before fitting the fan/back-cover assembly.

## Verification

Source SHA-256: `fd7bafbd62166f591abb133d0b37a50bc666eee8350e060e27a03c67f91f983d`.

The [assembly report](verification.json) passes with 11 closed single-body print meshes, zero degenerate faces, 429 coaxial feature pairs, 595 assembly pairs and 10 service paths. Screw-bearing and backing rings, insert walls/bottoms, pressing access and driver access all pass. The back-cover removal path now also checks the head screw heads as fixed obstacles.

- All 11 meshes are CLEAN in [islands](head-clamp-2026-09-25/islands.json), [overhangs](head-clamp-2026-09-25/overhangs.json), [thickness](head-clamp-2026-09-25/thickness.json) and [fins](head-clamp-2026-09-25/fins.json) at the configured thresholds.
- All 11 individual [slices](slicer-summary.json), four production plates and the USB test plate pass without warnings or supports. Production totals: 479.3 g / 16.0 h as arranged plates; 479.8 g / 17.4 h as individual jobs. USB test: 9.9 g / about 62 minutes.
- Static assembled estimate: 1016.5 g, 28.2 mm front margin and 21.0° tipping angle. Bought-part masses remain partly estimated.
- STLs, both 3MF projects, documentation views and both viewer copies were rebuilt. The local viewer tab still requires a manual reload because browser policy prevents refreshing it automatically. Project scripts match the shared skill.

The shared skill now explicitly requires checking the compression path behind a screw seat, in addition to head contact and insert engagement (`a3823d0`). No physical preload, pull-out, strength or creep validation is claimed.

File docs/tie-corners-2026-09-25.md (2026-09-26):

# Battery ties, four-corner head fastening and USB hold-down — 2026-09-25

The head-fastener arrangement in this report is superseded by [direct head-to-base clamping](head-clamp-2026-09-25.md). Battery and USB features remain in use.

This revision replaces the head-mounted battery shoulder retainers and the single rear row of head fasteners. It also adds an upper return to the central USB keeper. Updated production parts are `base`, `head`, `head_back` and `ball_lid`, plus two new `battery_bridge` pieces. Use the matching new base, head and back cover together.

## Battery restraint

Two integrated cable-tie loops sit under the cell, between its three existing saddles, at x26 and x54. Each has a 4 × 1.8 mm clear tunnel, 2 mm side walls and a 1.6 mm roof. Recessing the tunnel into the floor preserves the battery's installed height: 1.85 mm of floor remains underneath, and the loop top stays 0.5 mm below the nominal cell. Shallow ramps expose both tunnel mouths for threading before inserting the battery.

Two removable printed bridges under the ties transfer their load into the cylindrical cell shoulders. The protection board occupies the full measured cell length, so placing a bare circumferential tie elsewhere along the cell would not establish a board-free band. The bridges provide a 25 mm opening and nominal 0.5 mm clearance above the board. Both feet contact the cell after 0.2 mm of downward settling, leaving 0.3 mm above the board. Their 1.6 mm roofs print flat on the bed, feet upwards; each piece measures 8 × 29 × 14.8 mm.

Use two ties up to 3.6 × 1.2 mm, nominally 150 mm long, with their buckles in front of the cell. The model checks a 6 × 4 × 5 mm buckle envelope and a 130 mm closed band path, leaving about 20 mm for closure and the tail. The head clears the bridges by 0.4 mm and the bands by at least 0.237 mm. Local head-floor recesses retain 1.3 mm of material.

The base's existing right end wall and the left housing wall retain the cell axially. The cable ties retain it vertically even with the head removed. Cut and replace both ties for service. The geometry checks do not measure tie strength, tightening force, bridge deflection, creep or pressure through the real shrink wrap. Verify actual board clearance while tightening gently.

## Four-corner head fastening

The previous four vertical screws shared one row behind the fan because the permanent filter tube and fan blocked the forward tool paths. The new design changes the screw direction: two fasteners are approached from the front after removing the filter cassette, and two from the rear after removing the fan/back-cover assembly. Their axes are distributed across the four corner regions; the front pair sits higher to clear the magnet pockets and PWM controller.

Coordinates below are in the untilted head frame:

| Pair | Axis coordinates x/y/z (mm) | Screw | Insert engagement | Material beneath screw head |
|---|---|---|---|---|
| Front | 7.5/0/68 and 137.5/0/68 | M3 × 8 | 5.7 mm | 2.05 mm |
| Rear | 25/70/53.7 and 131/70/53.7 | M3 × 8 | 6.4 mm | 1.35 mm |

Four rooted base tongues carry Ruthex RX-M3x5.7 inserts in 7 mm pockets. The corresponding head seats have complete bearing rings, clear driver paths and accessible insert mouths. The back cover's forward lip has matching reliefs; its outside face remains continuous. Hardware quantities are unchanged.

With cassette and fan/back cover removed, the head, mat, support cross and magnets lift together 60 mm clear of the base and installed battery ties/bridges. The checked PWM extraction now includes a 6.5 mm shift left after the shaft clears the front rim, before the final upward lift past the rear-right tongue.

## USB hold-down

The central 4 mm wide keeper on the ballast lid now extends 1 mm over the USB module's front edge. Its upper return has a 1.6 mm roof and a sloping underside. Both side wire routes remain open, and the raised 45° base supports still clear the plain lid by 4 mm. Insert the module before installing the lid and keeper.

In the rigid-envelope checks, 0.1 mm upward movement is free; 0.6 mm upward movement and 2.9° of front-edge lift meet the upper return. This establishes geometric capture, not resistance to a specified cable force. The measured 4.3 mm USB-board height includes components and cannot identify a component-free PCB bearing patch. Check actual contact, solder and wire clearances on the updated [USB fit print](../stl/fumex_usb_fit.3mf) before committing to the full base.

The complete loaded-lid removal path still passes: remove head, battery, rocker switch and lid screws; lift 3.4 mm, pull 4 mm forwards, lift 3 mm, pull another 16 mm forwards, shift 0.2 mm right and lift clear. Real wiring needs enough slack for this sequence.

## Verification

Source SHA-256: `e2618ebbf2db47b545d2ba26b4e51981ecd32fe97618b2e99e35e175a1ecc460`.

- [Assembly report](verification.json): PASS; 11 print meshes (9 production types plus 2 optional USB test pieces), 13 production pieces, 435 coaxial feature pairs, 10 service paths and 595 assembly pairs. Every print mesh is closed, consistently wound, one connected body and free of degenerate triangles.
- Print analyses: [islands](tie-corners-2026-09-25/islands.json), [overhangs](tie-corners-2026-09-25/overhangs.json), [thickness](tie-corners-2026-09-25/thickness.json) and [fins](tie-corners-2026-09-25/fins.json) all CLEAN at their configured thresholds. This is a mesh-analysis result, not physical print validation.
- [Bambu slicing report](slicer-summary.json): all 11 individual meshes and all 5 arranged plates PASS without warnings or supports. The production project has 4 plates, 481.3 g and 16.1 h; the optional USB fit plate is 9.9 g and about 62 minutes. Individual production jobs total 17.5 h. No prime tower or mixed-material parts.
- Static tipping estimate: 28.2 mm front margin and 21.0° at 1.019 kg, based partly on estimated bought-part masses. Ballast capacity remains 40.3 cm³, about 189 g at the assumed loose-iron density.
- Printable STLs, both 3MF projects, README renders, `build/viewer.html` and `docs/index.html` were regenerated from the final model. Project scripts match the shared skill.

Remaining physical checks include USB cable-lever loading, actual tie/buckle dimensions and bridge clearance under tension, PETG creep, LED visibility through the 1.8 mm skins, wiring during service, fan/mat clearance and charger temperature. No force, thermal or flexible-body simulation is claimed.

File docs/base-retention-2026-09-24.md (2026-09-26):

# Base retention and USB access — 2026-09-24

This revision supersedes the lid-mounted battery tongue and right-side USB keeper described in `print-fit-2026-09-24.md`.

## Geometry

- The battery's axial end wall is integrated into the base, with 0.5 mm nominal end clearance. Its rounded, bevelled top stays below the protection-board and cable envelope.
- Two retainers on the removable head engage the front shoulders of the cylindrical cell at x12 and x68. The rear cradle walls oppose the resulting rearward movement. A 25 mm central opening clears the 20 mm protection board under the shrink wrap, following the split-holder principle used in LEO-AC1. The head must be fitted for upward restraint.
- A single central L-stop on the ballast lid retains the USB board at its PCB edge. Both lateral wire exits remain open. The USB channel's 45-degree gussets begin above the lid, which no longer needs USB support slots.
- Both blind LED pockets and flange seats move 1 mm inward. The front skins are now 1.8 mm; lens-to-pocket clearance stays 0.3 mm. The earlier local thin-wall exception is retired.

## Battery checks

The cell cylinder and protection-board envelope are tested separately. Contact with the board cannot count as battery retention.

- Nominal cell-to-holder clearance: 0.497 mm.
- Nominal protection-board clearance to the complete head: 2.448 mm; sideways clearance to the shoulder holders: 2.5 mm.
- Both shoulders catch the nominal cell after 0.8 mm upward movement. With 0.4 mm rearward offset, contact occurs at 1.325 mm.
- A diagonal escape attempt follows the rear cradle wall as the rising cell gains lateral space: both shoulders catch at 1.525 mm lift and 0.552 mm rearward movement. The protection board still has 1.118 mm clearance.
- The base end stop catches nine shifted/lifted axial probes. The upper cable corridor remains open. Head removal releases the upper retainers for upward battery extraction.

These are rigid geometric checks, not strength, creep, impact or shrink-wrap tests. Verify the actual cell, wires and cushioning on the printed parts. LED visibility through the chosen PETG also needs a physical check.

## USB support and lid service

The two 2 mm wide guides begin at y58.72; their 45° undersides meet the rear wall at z33, 4 mm above the lid. The PCB remains supported on its rear seat. Six 2 mm wide corridor probes check both lateral wire routes, including their upward exits with the central L fitted.

The lid still uses two M3 × 8 screws and Ruthex RX-M3x5.7 inserts. The axes are now (10,63) and (117,56.8). The right post has a front flat with 1.85 mm remaining around the insert bore, preserving the PWM board’s service path. Moving the right screw inwards and forwards preserves straight tool access past the head's mounting bosses and keeps its ear clear of the switch well. The trough and lid share the new switch contour and close within the existing 0.3 mm seam allowance. Usable ballast volume is approximately 40.3 cm³, or 189 g at the established loose-iron density estimate.

Remove the head, battery, rocker switch and lid screws first. The loaded lid follows six straight stages: up 3.4 mm, forwards 4 mm, up another 3 mm, forwards another 16 mm, right 0.2 mm, then up 60 mm. The 392 sampled poses are collision-free with at least 0.20 mm clearance after the initial lift. The switch has a separate 35 mm outward path that also works with the lid and battery installed. Clip flexure, finger access and connected wires remain physical checks.

The updated USB fit coupon retains the cropped right screw post plus two small fixture pads. All three support the lid at its installed z26 height. The cropped screw region is not an insert-fit specimen; the test remains for USB insertion, board seating and the central keeper.

## Final verification

Source SHA256: `edbaddc6a11a0139257ecf6defe52e571f14585859154e7e769e51c90340af35`.

- Ten closed, consistently oriented meshes, each one body and without degenerate faces; eight production types, eleven production pieces and two optional test pieces.
- All 528 assembly pairs, 449 coaxial feature pairs, ten standard paths, the complete PWM service path and the 392-pose loaded-lid path pass. The USB board and fit coupon also pass their continuous swept installation paths.
- Islands, overhangs, thickness and fins: **CLEAN on all ten meshes**. Saved results: [islands](base-retention-2026-09-24/islands.json), [overhangs](base-retention-2026-09-24/overhangs.json), [thickness](base-retention-2026-09-24/thickness.json), [fins](base-retention-2026-09-24/fins.json).
- The head's known numerical Trimesh ray warnings leave 65,500 of 65,672 thickness samples usable; no region is flagged. These sampled checks do not establish every local wall thickness or printed strength.
- Estimated assembled mass 1012.6 g; front tipping margin 28.5 mm and tip angle 21.2°. Bought-part mass estimates and loose-iron packing density remain unmeasured.
- All ten individual slices, four production plates and the optional USB fit plate pass with supports disabled and no slicer warnings. Production totals are 476.8 g / 15.8 h as arranged plates, or 477.2 g / 16.8 h as individual jobs. The USB fit plate uses 10.3 g and takes about 65 minutes. Settings and individual results: [slicer summary](slicer-summary.json).
- Both viewer copies (`build/viewer.html` and `docs/index.html`) are rebuilt from the current assembly exports and are byte-identical. The affected documentation views are regenerated and visually checked. The open local browser tab could not be refreshed because browser policy blocked local-file access; it needs a manual reload.

The changed production pieces are `base`, `head` and `ball_lid`. Their replacements work together; the other production pieces retain their geometry. Both optional USB fit pieces are updated as well.

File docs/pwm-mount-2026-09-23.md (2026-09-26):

# PWM controller floor mounting — 2026-09-23

The PWM controller now fastens through its two front PCB holes into floor-connected bosses using the user's two 2.5 × 8 mm thermoplastic screws. There is no potentiometer nut or washer on the front. The knob diameter is 24 mm, down from 26 mm; shaft engagement and axial projection are unchanged.

PWM board, floor bosses and screws, exploded; components omitted

## Dimensions and installation

| Feature | Result |
|---|---|
| PCB | 41.05 × 32 × 1.6 mm, shared measured hardware |
| Holes | Ø3.2 mm, centres 3 mm from front and side edges; 26 mm pitch |
| Screw heads | Flat underside, measured Ø4.5 mm; 2.5 mm height used as an unmeasured clearance envelope |
| Floor bosses | Ø6 mm, bearing plane z13.1; existing edge pads support the rear |
| Pilot | Ø2.0 × 7.4 mm, relieved mouth Ø2.7 × 0.7 mm |
| Screw penetration | 6.4 mm through the PCB, 1 mm reserve to the pilot bottom |
| Floor reserve | 2.5 mm above the 3.2 mm floor |
| Tool access | Slim shaft Ø4 mm for at least 25 mm above the head |

Install the PWM controller before the rocker switch. Tilt the PCB rear upwards, feed the shaft through the concealed front opening, and lower the board onto the bosses and edge pads. The opening and internal recesses allow 3.5 mm of upward movement for installation; the knob covers the opening. The PCB remains in its original position because the switch limits rearward relocation. Keep the knob as a removable press fit; the former mandatory CA-glue instruction is removed so the controller remains accessible.

The pilot is a starting value for printed PETG, inferred from the 0.8D relation in the [EJOT DELTA PT thermoplastic design guide](https://www.ejot.com/medias/sys_master/Industry_Flyer/Industry_Flyer/h11/hc7/9331662782494/EJOT-DELTA-PT-Flyer-08.23-en.pdf). The user's unidentified screws are not asserted to be EJOT. Confirm driving torque and retention on a printed sample. The measured head diameter and the user's clearance confirmation are used; head height remains unmeasured.

## Verification

- Eight closed print types, eleven pieces; 443 coaxial feature pairs and 528 assembly pairs pass. Intentional screw/pilot interference is restricted to the two thread-forming regions.
- Both boss bearing rings and PCB bearing rings are complete. Each screw head and each PCB seat passes an individual contact probe. Pilot depth, material around the holes, bottom reserve and driver access pass.
- Nine standard paths and the LED access path pass. The new complete PWM removal path additionally checks 465 lift/translation/rotation poses, including the actual anti-rotation tab. Maximum computed overlap is 0.000052 mm³, below the 0.01 mm³ numerical tolerance. Remove the head assembly, knob, both PCB screws and rocker switch first. Battery, loaded ballast lid, USB board and LEDs may stay. Both screws independently clear 60 mm vertically; the knob clears 20 mm forwards. Reverse the PCB path for installation.
- Islands, overhangs at the standard 100 mm² threshold and fins are CLEAN across all eight parts. Thickness reports only the two intentional 0.8 mm LED skins (sampled areas 20 and 12 mm²). The head retains its numerical ray warnings: 65,204 valid samples out of 65,404. This is not a global thickness or physical-fit guarantee.
- All eight individual parts and four arranged plates slice without supports and with no warnings. Arranged plates: **471.9 g / 15.6 h**. Individual jobs: 472.3 g / 16.6 h.
- Estimated assembled mass 1017.2 g; front tipping margin 29.0 mm, tipping angle 21.7°. Ballast capacity is unchanged.

The STL files, four-plate 3MF, ten documentation views and viewer are rebuilt. Mesh source SHA: `b21de4cee404bf7ec0729d4387ee1f67255d2660a494efb6897dea5861848cb0`.

Evidence: [full geometry report](verification.json), [slicer report](slicer-summary.json), [printability evidence](pwm-mount-2026-09-23/thickness.json). Wiring, print tolerances, screw strength and actual hardware fit require physical verification. Previously documented airflow, thermal and ballast-lid extraction limits remain.

The lofted-wall recess pitfall found while extending the installation clearance is recorded in the shared print skill (commit `e72f129`). Project scripts remain identical to the shared skill.

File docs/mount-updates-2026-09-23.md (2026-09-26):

# Mount and control updates — 2026-09-23

Source SHA-256: `ef984926c92907ff6b44ab8dca544594ecc9b8692bdbae2d17ccce483a763e5b`.

| Request | Final construction |
|---|---|
| Remove the lid finger dish | Both duplicate cutters and their parameter are removed. The ballast lid has a plain top in that area. Its two M3 × 8 / Ruthex fasteners remain. |
| Use 45° supports for the USB-C PD module | Two gussets grow from the back wall, with at least 9.02 mm clearance above the trough floor. The existing rear-open lid slots pass around them. The gussets reach just below the lid to close those slots against loose ballast. |
| Four head-to-base screws | Four M3 × 8 screws with Ruthex RX-M3x5.7 inserts, at x25/45/118/127 and y66. Two pairs occupy the accessible rear row. Every screw has a complete bearing seat and checked tool access. |
| Second LED holder | A second blind Ø3.2 mm pocket at x80/z21 sits 8 mm beside the existing x88/z21 pocket. Both retain closed 0.8 mm front skins and inside flange seats. No electrical function is assigned to the additional holder. |
| More room for the PWM tab | Clearance is 0.4 mm per side, previously 0.2 mm. The anti-rotation-tab cut-out is now 2.9 mm wide instead of 2.5 mm. |
| Smaller knob | Diameter reduced from 28 to 26 mm; the shaft fit, internal sleeve and installed depth remain unchanged. |

Four head-to-base fasteners, lifted for clarity

USB-C support gussets, with the trough front cut away for visibility

## Geometry and assembly

All four head fasteners have 2.4 mm of bearing material, 5.6 mm screw penetration and 1.4 mm to the insert-pocket bottom. Each seat's material and closed-rim probes are fully filled, and each screw makes contact under a 0.05 mm seating displacement. The 0.6 mm shallow counterbore has a 0.8 mm rear lip; the load-bearing material below it remains complete. The left seat has a sloping connection to the cable-opening edge so it grows from existing material during printing.

The front filter tube leaves only about 4 mm above a possible front-row screw head. The four rear-row positions retain straight bit access without relying on unknown dimensions of the user's compact Wera ratchet. Existing charger air passages and the loaded lid's 10 mm vertical lift remain clear.

The USB gusset undersides measure a slope of −1 in Y/Z on both sides, corresponding to 45°. Their lower air volumes are empty, their upper load paths are continuous, and the PCB still bears on its rear seat. Both LED skins measure 0.8 mm; both nominal LED envelopes have the checked 15 mm inside-access path.

## Final checks and artifacts

- Eight closed print types, eleven physical pieces, 374 coaxial feature pairs and 496 assembly pairs pass. Nine standard sampled paths plus the combined LED-access path pass.
- Islands, overhangs at the standard 100 mm² threshold and fins are CLEAN. Thickness reports exactly the two intentional 0.8 mm LED windows; the 1.2 mm threshold is unchanged elsewhere. Head sampling retains the known Trimesh numerical warnings, with 65,204 usable samples out of 65,404.
- All eight individual parts and all four arranged plates slice with supports disabled and **no warnings**. The previous head floating-cantilever warning is gone.
- Arranged plates: **472.3 g / 15.5 h**. Individual jobs: **472.8 g / 16.5 h**.
- Ballast capacity: **42.42 cm³**, approximately **199 g** at the assumed packing density. Estimated assembly mass: **1019.3 g**; front margin **28.9 mm**, tipping angle **21.7°**.
- STLs, project 3MF, all nine documentation views and both viewer copies are rebuilt. Source/STL/slicer/3MF hashes agree; `build/viewer.html` and `docs/index.html` are identical.

[Verification report](verification.json), [slicer report](slicer-summary.json), and [archived evidence](mount-updates-2026-09-23/evidence.json). The evidence directory also contains the final build logs. The shared skill's screw-seat pitfall was updated in commit `6c9b8ec`; project scripts remain identical to the skill.

The loaded lid's complete extraction sequence remains unproven beyond its checked 10 mm lift. Physical fit, LED visibility, strength, thermal performance, airflow and flexible filter behaviour still require checks on the real assembly. The open viewer tab needs a manual reload because automated access to its local-file URL was blocked by the browser security policy.

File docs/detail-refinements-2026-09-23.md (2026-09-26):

# Detail refinements — 2026-09-23

The ballast lid uses exactly **two M3 × 8 screws**, one centred at each end, with **Ruthex RX-M3x5.7 inserts**. Both screw seats and insert access are verified in the freshly exported assembly.

The closed LED window, fan-guide lead-ins, continuous intake lip, floor-supported USB-C channel and wider switch recess pass the final geometry checks. The intentional 0.8 mm LED skin is the only reported wall-thickness exception. Slicing succeeds without supports; the base now has no warning, while the head retains its existing floating-cantilever warning.

Source SHA-256: `6bf5fd11fdefd249b418a3faa7921d67a7f2b9f68ec29cc29cbbd020050e2df5`.

## Geometry changes and direct checks

| Feature | Construction and evidence |
|---|---|
| Two lid fasteners | Axes (10,63) and (135,63), with y63 centred between the original trough interior faces y55/71. Two Ø10 mm posts contain Ø4 × 7 mm pockets. Both screw-seat and enclosure probes are 100% filled; straight Ø6.35 mm insert-tool access is clear. M3 × 8 provides 6.2 mm penetration for the 5.7 mm insert, with 0.8 mm clearance to the pocket bottom. |
| Closed LED front | A Ø3.2 mm blind bore starts at y=0.8 behind the unchanged outer front face. The Ø7 mm boss ends at y=5.8. Five mesh rays measure exactly 0.8 mm of skin; the full-disc material probe finds 0 mm³ missing. The inward pocket probe finds 0 mm³ obstruction. |
| LED installation | The nominal Ø3 mm body starts 0.3 mm behind the skin. Its Ø3.8 mm flange rests on the boss's rear face: the bearing-ring probe is 100% filled and a 0.05 mm forward displacement makes 0.16474 mm³ of contact there. A 15 mm inward removal path in 0.5 mm steps has no collision against all other installed physical bodies; reversing it gives the geometric insertion path. Temporary screwdriver envelopes are excluded. |
| Fan guide chamfers | Each of the four L-guides has a 1.2 mm, 45° chamfer on both inward-facing rear edges. The straight locating clearance remains 0.4 mm per side; entry clearance increases to 1.6 mm. Independent rays through all eight flanks at rear depths 0.1/0.6/1.1/1.3 mm measure clearance 1.5/1.0/0.5/0.4 mm. Maximum error over 32 samples: 0.000006 mm. The 2.4 mm guide retains 1.2 mm at the chamfered end. |
| Intake lip | Both half-round mat cut-outs are removed. All 114 sampled points in the former cut-outs, spanning both side lips, three face depths and ±9 mm vertically, are now solid. The separate cassette finger scoops at the outer housing sides remain. The straight-side retaining overlap is 2.25 mm. |
| USB-C support | Both channel walls now grow from the trough floor. The wider right foot carries the one-sided insertion stop; the rear board seat bridges 7.85 mm between supports. Four vertical material probes are 100% filled. Both rear-open lid slots have zero overlap with the enlarged support-clearance probes. The board sits at z=42.85 mm and produces 2.5875 mm³ contact after a 0.05 mm downward move. |
| Switch recess and lid | The wider matched trough/lid contour uses `ball_step=[118.5,60]`; a radius-4.6 mm ear keeps the right screw pocket enclosed. The two existing M3×8/Ruthex axes remain at (10,63) and (135,63). The terminal envelope has 5.5 mm of space in front of it, with 2.402 mm between switch and lid and 2.002 mm at the closest trough-to-switch point. Top-cover slices leave 0 mm² uncovered beyond the permitted 0.3 mm seam; the sampled effective maximum seam is 0.235 mm. |

The LED geometry follows the LEO-AC1 blind-pocket arrangement. The nominal LED body and flange are inherited dimensions, not measurements of the actual FUMEX LED. The black PETG skin still needs a physical light-transmission test. The 15 mm path checks the rigid nominal LED envelope; it does not model leads, adhesive or hand/tool access.

Two ballast-lid screws and the matching supports

USB-C channel on continuous support ribs

## Final verification

- Eight closed print meshes, eleven physical printed pieces, 337 coaxial feature pairs and 496 assembly pairs pass. Nine standard sampled assembly paths pass, plus the separate 15 mm LED path.
- Islands, overhangs (100 mm² threshold) and fins are CLEAN. The standard thickness threshold remains **1.2 mm**. The base's closed LED skin is the sole thickness finding: minimum/median 0.8 mm over the analyzer's 20 mm² sampled region. This is an explicit local optical exception, not an unconditional thickness pass.
- Head thickness sampling yields 65,088 valid points out of 65,277 with the known numerical Trimesh warnings. Sampling does not prove every possible wall thickness.
- All eight individual types and all four arranged plates slice with supports disabled. The base has **no warning**; only the existing head floating-cantilever warning remains.
- Arranged plates: **472.9 g / 15.4 h**. Individual jobs: **473.4 g / 16.4 h**.
- Net ballast capacity: **40.968 cm³**, approximately **192.55 g** at the assumed packing density. Estimated assembled mass: **1009.8 g**. Front stability margin: **28.6 mm**; tip angle: **21.3°**.

Only the loaded ballast lid's 10 mm vertical lift is established. Complete extraction and a tilt sequence remain unproven. Strength, light transmission, thermal performance, airflow, wire routing with real solder joints and flexible-mat behaviour still require physical checks.

## Evidence

The main results are in [verification.json](verification.json) and [slicer-summary.json](slicer-summary.json). The [evidence snapshot](detail-refinements-2026-09-23/evidence.json) records all four analyses, command exit codes, the intentional thickness exception and artifact hashes. Independent [fan-profile and restored-lip samples](detail-refinements-2026-09-23/geometry-review.json) use the actual exported mesh. The same evidence directory contains the final export, analysis, slicing, rendering and viewer logs.

The source, all eight STL hashes, the slicer's source meshes and the project 3MF match. Both viewer files are identical, rebuilt from the final assembly exports. All eight documentation images were regenerated; the two detail images above were visually inspected. The existing browser tab needs a manual reload: its local-file URL was blocked by the browser security policy for automated access.

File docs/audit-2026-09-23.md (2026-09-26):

# FUMEX – vollständiges Projektaudit

Stand: 23. September 2026 · geprüfter Commit: `a90c581` · Modell unverändert.

Nachtrag: Die ursprünglichen Befunde bleiben hier als Prüfstand erhalten. Die anschließenden Korrekturen sind in `AGENTS.md` dokumentiert; für G2 und G3 siehe [Nachprüfung der Rundungen und Sockelfuge](rounding-2026-09-23.md). Die spätere [BOSL2-Umstellung und aufrechte Ladeplatine](bosl2-charger-2026-09-23.md) sind separat nachgeprüft. Den aktuellen Aufbau von Filterstütze, Platinenhaltern, Schalterfreiraum und Deckelverschraubung beschreibt der [Hardware-Nachtrag](hardware-2026-09-23.md).

**Urteil: Die Grundkonstruktion ist plausibel und digital gut druckbar. Eine uneingeschränkte Aussage „alles montierbar, bündig und durchgehend gerundet“ ist derzeit nicht gerechtfertigt.** Es gibt konkrete Befestigungs- und Montageprobleme, eine offene Stelle im Ballastbehälter und echte Formkanten. Die vorhandenen Prüfungen laufen trotzdem durch, weil sie diese Eigenschaften teilweise nicht prüfen oder einen älteren Montageablauf abbilden.

Das Audit umfasst Quellcode, frisch erzeugte Netze, vorhandene Druckdateien, Slicerprofile, Stückliste, Montageanleitung, Werkzeugzugang, Bewegungswege, Stabilitätsrechnung und helle Render-/Schnittansichten. Es enthält keine Änderungen am Modell und keinen physischen Druckversuch. Gemeinsame Hardwaremaße wurden gegen die Messnotizen von LEO-AC1 betrachtet; eine vereinfachte Hardwarehülle ersetzt keine Passprobe am realen Teil.

## 1. Wichtigste Befunde

P1: vor Aufbau/Betrieb beheben. P2: vor dem endgültigen Komplettdruck klären oder korrigieren. P3: Dokumentation beziehungsweise Detailqualität nachziehen.

| ID | Priorität | Befund | Nachweis |
|---|---|---|---|
| A1 | P1 | Die Schalter-Aussparung im Ballastdeckel öffnet die Metallwanne zur Elektronik. | Freier Durchlass mindestens 9 × 3,5 mm. |
| A2 | P1 | USB-C-Platine kann beim Einstecken nach innen geschoben werden. | 15 mm kollisionsfreier Weg; kein innerer Anschlag/Clip. |
| A3 | P1 | Montageanleitung nennt die falsche Lüfterrichtung. | „Away from the cover“ kehrt den vorgesehenen Luftstrom um. |
| A4 | P2 | Der beschriebene gerade Einschub der Ladeplatine funktioniert mit der modellierten Bauteilhülle nicht. | Kollision mit Endauflage; vertikaler Ausbau kollidiert mit Haltenase. |
| A5 | P2 | Ballastdeckel: M3 × 12 reicht tiefer als das Kernloch; unter den Köpfen bleiben nur 1,1 mm. | 10,9 mm Eingriff bei 10 mm Lochtiefe; `thickness CLEAN` übersieht den Ring. |
| G1 | P2 | Die seitliche Kassettenfase wird abgeschnitten. | Lange Seiten bleiben über volle 4,5 mm scharfkantig. |
| G2 | P2 | Obere Kopfecken sind keine durchgehenden räumlichen Rundungen. | R3,5 und R6 schneiden sich mit deutlichem Normalensprung. |
| G3 | P2 | Gleicher lokaler Grundriss garantiert keine bündige Kopf-/Basisfuge. | Kippen verändert den Schnittgrundriss; sichtbare hintere Basislippe. |
| S1 | P2 | Kippwinkel überschätzt die Stabilität. | Fußhöhe und kleinere Aufstandsfläche fehlen; korrigiert etwa 21,6° statt 23,5°. |
| V1 | P2 | Montageprüfungen und offene Punkte bilden den aktuellen Aufbau unvollständig ab. | Falsche bewegte Gruppen, fehlende Befestigungen und Passtests. |
| D1 | P3 | README/AGENTS enthalten zahlreiche überholte Maße und Aussagen. | Inserts, Bauteilgrößen, Radien, Ballast, Prüfzahlen, Filterorientierung. |

## 2. Geometrie und ästhetische Wirkung

### Gesamtform

Die ruhige, funktionale Form passt zu einem Werkbankgerät. Der stehende Sockel, der nach vorn geneigte Kopf und die unten angeordnete Bedienung ergeben eine verständliche Gliederung. Kassetten- und Abluftgitter sprechen dieselbe Formensprache. Die Füße stehen innerhalb der Gehäusesilhouette; der seitlich versenkte Schalter und der große Knopf sind nachvollziehbare Funktionsdetails. Zusätzliche dekorative Elemente sind nicht erforderlich.

Die helle Darstellung dient der Formprüfung; sie ist keine Änderung der Filamentfarben. Die Render zeigen die gedruckten Teile ohne Hardware, damit die Konturen sichtbar bleiben.

| Vorderansicht | Rückansicht |
|---|---|
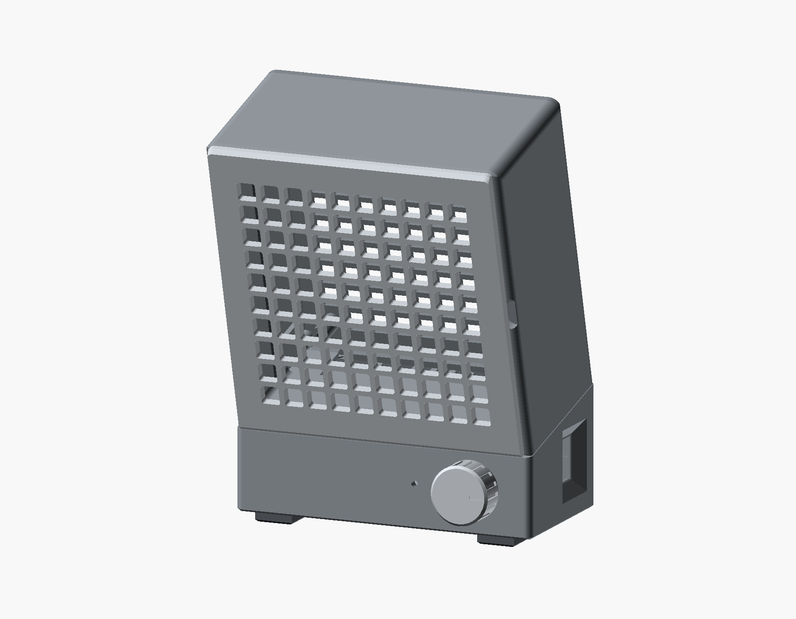
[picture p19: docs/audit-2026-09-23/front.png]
Front
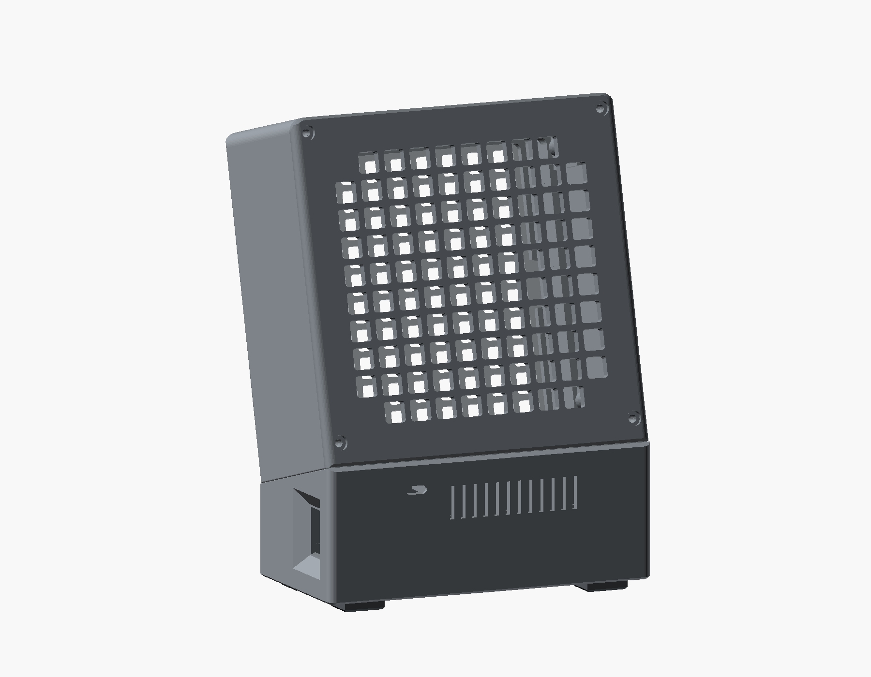
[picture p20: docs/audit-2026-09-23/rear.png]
Rear
|  |  |

Die problematischen Stellen liegen in der Umsetzung der Übergänge, nicht in der grundsätzlichen Proportionierung.

### G1 – Kassette: seitliche Fase fehlt tatsächlich

`cassette_body()` erzeugt zunächst eine 2-mm-Randfase. Anschließend schneidet `cassette_raw()` das gesamte Teil mit `cass_prism()`. Dessen nach vorn verlängerte Fläche beginnt bei `x = plan_r = 3,5` und endet bei `141,5`. Selbst die vorderste ursprüngliche Fasenkontur beginnt bereits bei `x = cass_inset + cass_c = 3,0`; der spätere Schnitt liegt weiter innen und entfernt daher die seitliche Fase vollständig.

Ergebnis: tatsächliche Breite **138 mm**, an beiden langen Seiten eine senkrechte Wand über **volle 4,5 mm** bis zur Vorderfläche. Die README-Aussage einer umlaufenden Fase mit nur 2,5 mm sichtbarer Stufe trifft dort nicht zu. Das ist eine echte modellierte Kante, kein Beleuchtungsfehler.

Beleg: `fumex.scad:364–366`, `:567–575`; [Querschnitt der Kassette](audit-2026-09-23/cassette_side_bevel.png).

**Empfehlung:** Die Fase aus der endgültigen Kassettenkontur ableiten. Anschließend Magnetabstand und verbleibende Haut erneut prüfen; die bisherige Magnetbedingung allein belegt die fertige Außenkante nicht.

### G2 – Obere Kopfecken: Schnitt zweier Radien erzeugt eine Formkante

Der Kopf ist der Schnitt eines im Grundriss gerundeten Prismas mit einer im Aufriss gerundeten Hülle: **R3,5 in XY**, **R6 in XZ**. Zwei separat gerundete Profile ergeben durch ihre Schnittmenge keinen tangentialen räumlichen Eckübergang.

Analytisches Beispiel im ungedrehten Kopfsystem: ungefähr `x = 0,5`, `y = 1,6972`, `z = 189,3979`. Die beiden Flächennormalen unterscheiden sich dort um **38,21°**. Der Punkt liegt hinter der 1,2-mm-Frontfase. Im STL finden sich an derselben Ecke entsprechende Sprünge von etwa **34–44°** zwischen benachbarten Außenflächen. Diese diagonale Kante bleibt auch bei feinerer Tessellierung bestehen.

Beleg: `fumex.scad:360–363`, `:377–383`, `:413`; [Detail der oberen Ecke](audit-2026-09-23/head_top_corner_close.png).

**Empfehlung:** Wenn die Ecke wirklich weich durchlaufen soll, einen gemeinsamen räumlichen Übergang konstruieren. Bloß `$fn` zu erhöhen löst diesen Befund nicht. Die vorhandene Begrenzung durch Magnettaschen und Wandstärke bleibt dabei maßgeblich.

### G3 – Fuge zwischen Kopf und Basis: bündig nur in Teilbereichen

`plan_prism()` verwendet den Basisgrundriss im **lokalen Kopfsystem**; anschließend kippt `head_at()` diesen um 15°. Die Basis bleibt senkrecht. Damit sind die Grundrisse an der Fugenebene nicht identisch.

Ohne Randfasen liegt die vordere/hintere Kopfkante an der Fuge in Weltkoordinaten jeweils rund **1,261 mm innerhalb** der senkrechten Basisaußenfläche: `37 × (1 − cos 15°)`. Im lokalen Kopfsystem reicht der Schnitt der Basis dagegen bis ungefähr `y = −1,305` beziehungsweise `75,305`, während der Kopf auf `0…74` begrenzt ist. Fasen verändern den sichtbaren Verlauf zusätzlich; die genannte Zahl ist deshalb die Grundrissabweichung, kein überall gleich breiter sichtbarer Absatz.

Der [Schnitt hinten](audit-2026-09-23/rear_joint.png) und die [Seitenansicht](audit-2026-09-23/side.png) zeigen die verbleibende Basislippe. Die absichtliche 0,3-mm-Deckelfuge und ihre Fasen sind sinnvoll, begründen aber nicht die Aussage, alle Außenkonturen liefen stufenlos durch.

Beleg: `fumex.scad:355`, `:360–363`, `:413`, `:516–558`.

**Empfehlung:** Gewünschte Fugenkontur in einem gemeinsamen Koordinatensystem definieren und daraus beide anschließenden Teile ableiten. Die sichtbare Trennfuge darf bleiben; die Außenkontur sollte unabhängig davon geprüft werden.

### Kleiner Halsradius und bewusst sichtbare Kanten

Der kleine Übergang an der Seitenwand ist ebenfalls nicht überall glatt: `joint_neck()` lässt den R1-Auslauf die senkrechte Basiswand schneiden, statt dort tangential einzulaufen. Im exportierten Mittelschnitt ist der untere Abschnitt eine einzelne Gerade von ungefähr `(x=0, z=47,8532)` nach `(0,5, 48)`. Der R0,5 darüber besteht unter `$fs = 0,6` nur aus zwei Facetten. Die vergrößerte [Schnittansicht](audit-2026-09-23/side_neck.png) belegt das. Wegen der kleinen Abmessung ist dies ein Detailbefund; die fehlende Tangentialität und die grobe Auflösung sind zwei verschiedene Ursachen.

Die aufgesetzte Filterkassette, die hintere Deckelfuge, die Bodenfasen, Griffmulden und Knopfriffelung sind hingegen bewusste Funktionsdetails. Eine sichtbar abgesetzte Kassette ist gestalterisch vertretbar. Es ist nicht erforderlich, alle funktionalen Kanten in große Radien umzuwandeln.

## 3. Montage, Befestigung und Wartung

### A1 – Ballastbehälter ist an der Schalterausnehmung offen

Die rechte Aussparung des Deckels reicht von etwa `x=129…143`, `y=52…63`. Der zurückgesetzte Wanneninnenraum beginnt dort bereits bei `y=59`. Somit entfernt der Deckelausschnitt auch Abdeckung über tatsächlich vorhandenem Ballastvolumen.

Ein Prüfquader bei `x=129,1…138,1`, `y=59,25…62,75`, `z=25…31` überschneidet das Ballastvolumen um **31,5 mm³**, aber weder Basis, Deckel, Schalter noch Ladeelektronik. Er belegt eine mindestens **9 × 3,5 mm große offene Verbindung** vom Metallinhalt in den Elektronikraum. Ob ein bestimmtes verwendetes Reststück hindurchpasst, hängt von dessen Abmessungen ab; die behauptete vollständige Rückhaltung ist geometrisch widerlegt.

Zusätzlich bleibt durch `ball_rim=0,4` ein schmaler Spalt zwischen Wannenwand und Deckel. Dieser ist bei groben Stücken wesentlich weniger kritisch, hält aber feine Metallspäne nicht zurück.

Beleg: `fumex.scad:211–223`, `:678–683`, `:698–705`, `:717–721`.

**Empfehlung:** Wannenbegrenzung und Aussparung aufeinander abstimmen oder den Ballast separat geschlossen einschließen. Der Schalter muss dabei weiterhin montierbar bleiben.

### A2 – USB-C-Platine hat keine Sicherung gegen Einsteckkraft

Der Kanal positioniert die Platine seitlich und unterhalb, besitzt aber nach innen keinen formschlüssigen Anschlag. Der Körper `usbc` lässt sich **15 mm nach innen** bewegen, ohne Basis, Kopf, Akku, PWM-Platine, Schalter, Deckel oder Ladeelektronik zu schneiden. Die Kabelbinder halten die Leitungen, nicht nachweisbar die Platine selbst. Eine zusätzliche Fixierung wird in der Montageanleitung nicht verlangt.

Damit kann ein eingestecktes Kabel die Platine in das Gehäuse schieben. Ein kollisionsfreier Endzustand ist hier gerade kein Befestigungsnachweis.

Beleg: `fumex.scad:649–665`, `:842–844`; `README.md:90`.

**Empfehlung:** Zugänglichen Anschlag/Clip vorsehen oder eine konkrete, belastbare Fixierung festlegen. Anschließend Einstecken und Abziehen am realen Modul prüfen.

### A3 – Lüfterrichtung und Filterorientierung in der Anleitung korrigieren

`README.md:89` fordert einen Lüfter, der vom Deckel weg bläst. Für den beschriebenen Aufbau muss er **zur Rückwand hin und durch deren Gitter hinaus** blasen. Das ist funktional relevant, insbesondere für die vorgesehene Kühlung der Ladeplatine aus dem Plenum.

`README.md:97` verlangt außerdem, die Matte mit der Vliesseite zuerst hineinzuschieben. Beim Einführen von vorn landet diese Seite hinten. Die Stückliste verlangt dagegen zutreffend **Vlies nach vorn, Kohleschicht nach hinten**. Eine eindeutige Endlagenbeschreibung ist besser als „Seite zuerst“.

### A4 – Ladeplatine: dokumentierter gerader Montageweg kollidiert

Der linke Halter besitzt eine Nase über der Platine. Daher kollidiert ein vertikales Anheben der Ladebaugruppe bereits nach **0,25 mm** mit dem Ballastdeckel. Der derzeitige `chg_off`-Test übersieht dies, weil er den Deckel nicht als Hindernis enthält.

Auch der in `README.md:91` beschriebene gerade seitliche Einschub von rechts ist für die aktuelle Hülle nicht frei: Beim entsprechenden Auszug schneiden die nach unten ragenden Bauteile die rechte Endauflage; erste Kollision nach **0,25 mm**, im untersuchten Verlauf bis etwa **59,1 mm³**.

Das beweist einen Fehler der beschriebenen geraden Bewegung, **nicht**, dass jede schräge oder elastische Montage unmöglich wäre. Ein solcher anderer Weg ist gegenwärtig nicht belegt.

Beleg: `fumex.scad:485–501`, `:834–841`; `print_project.py:153–164`.

Hinzu kommt eine Lücke der Hardwarehülle: Sie behandelt die letzten 2 mm an beiden Platinenenden als bauteilfrei. Die LEO-AC1-Notizen zur Platinenbelegung nennen am OUT-Ende dagegen Lötpads samt Kabeln in beiden Ecken auf den ersten 0–2,8 mm, aus Fotos mit etwa ±0,3 mm abgeleitet. Die tatsächlichen Lötstellen und ihre Kabelrichtung müssen gegenüber der Endauflage freigestellt werden; die momentane Hülle kann diesen Kontakt nicht erkennen.

**Empfehlung:** Entweder Halter für einen tatsächlich freien Weg ändern oder die schräge Montage am realen Modul durchführen und genau beschreiben. Kontakt mit bestückten Platinenflächen darf dabei nicht als elastische Reserve angesetzt werden.

### A5 – Ballastdeckel: Schraubenlänge, Kopftasche und Prüfmodell passen nicht zusammen

Die Deckelplatte ist 3 mm dick, die Kopftasche 1,9 mm tief. Der Schraubenkopf trägt deshalb auf einem nur **1,1 mm dicken Ring**; dessen radiale Breite beträgt `(6,4 − 3,4)/2 = 1,5 mm`. Die 1,1 mm wurden an allen vier Taschen am STL bestätigt. Sie liegen unter der projektweiten 1,2-mm-Richtgröße, und genau dort wirkt die Klemmkraft.

Eine M3 × 12 reicht ab dieser Auflage **10,9 mm** in den Pfosten. Das vorgeformte Kernloch ist nur **10 mm** tief. Die Spitze muss somit etwa **0,9 mm in ungebohrtes Material** vordringen, bevor der Kopf vollständig sitzt. Ohne konkrete Schraubengeometrie ist das kein verlässlicher Schraubanschlag. M3 × 10 oder ein ausreichend tieferes Kernloch sind mögliche Korrekturen, jeweils passend zur echten gewählten Kunststoffschraube.

Die vier Deckelschrauben fehlen als Körper in `ASSEMBLY`; nur ihre Werkzeuge werden modelliert. Deshalb kann die Baugruppenprüfung diese Längenkollision nicht finden.

Warum `thickness CLEAN`? Der dünne Ring liegt vollständig innerhalb des voreingestellten 2-mm-Ausschlussbereichs um scharfe konvexe Kanten. Der Bericht enthält zwar `p01=1,1 mm`, meldet aber keine Region. Ohne diesen Kantenausschluss erscheinen die Taschen als dünne Bereiche. Dies ist eine konkrete Abdeckungslücke, kein Beleg für eine überall eingehaltene Mindestwandstärke.

Beleg: `fumex.scad:218`, `:225–226`, `:686–709`, `:884`; `scripts/analyze.py:164–171`.
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

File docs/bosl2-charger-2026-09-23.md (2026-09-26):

# FUMEX – Randfasen und aufrechte Ladeplatine

Stand: 23. September 2026. Ergänzung zum [Projekt-Audit](audit-2026-09-23.md) und zur [Nachprüfung der Rundungen G2/G3](rounding-2026-09-23.md).

Nachtrag: Die hier beschriebene beidseitige Platinenhalterung und die frühere Deckelverschraubung wurden inzwischen ersetzt; siehe [aktueller Hardware-Aufbau](hardware-2026-09-23.md). Die verlinkten README-Bilder zeigen den aktuellen Stand, die folgenden Messwerte den damaligen Prüfstand.

## Umgesetzte Änderungen

**Die vorgesehenen Randfasen werden mit BOSL2 aus ihren tatsächlichen Endkonturen erzeugt.** `profile_sweep_y()` verwendet `offset_sweep()` und `os_chamfer()` für Kopf, Rückwand und Kassette; die Bodenfase der Basis folgt demselben Verfahren. Die Fasenhöhe hängt damit nicht mehr von dünnen Hilfskörpern einer Hülloperation ab. BOSL2 ist als Git-Submodul auf `989cc33b56313238f3ffeafcbd2876b71a0a593a` festgelegt.

Die tangentialen R3,5-Rundungen entlang der langen Gehäuseseiten bleiben erhalten. Auch die geglätteten oberen Ecken, der angepasste Sockelübergang und der gewollte 15°-Knick bleiben bestehen. Die Änderung betrifft gezielt die Randfasen.

**Die Ladeplatine steht jetzt aufrecht auf dem Ballastdeckel.** Die Bauteile zeigen nach vorn, der Kühlkörper nach hinten. Zwei schmale, oben offene Endhalter ersetzen die umschließende Wanne. Links führt eine 1,4-mm-Nut die 1-mm-Platine; rechts bleibt die Rückseite wegen des überstehenden Kühlkörpers offen. Die Platine wird von oben eingesetzt.

| Bauteilseite | Kühlkörperseite |
|---|---|
| Aufrechte Platine von vorn | Aufrechte Platine von hinten |

Die Platine reicht von z = **32,2 bis 43,2 mm**, Kühlkörper samt Pad von **30,7 bis 44,7 mm**. Unter dem Kühlkörper bleiben 1,7 mm zur Deckelfläche. Der gedruckte Deckel ist einschließlich Halter 12,4 mm hoch.

## Geometrische Nachweise

- **Randfasen:** 24 Messungen an den tatsächlichen Netzkonturen; größte Abweichung vom vorgesehenen Profil etwa **0,0002 mm**.
- **Luftzugang:** Freiräume unmittelbar vor den Bauteilen und hinter dem Kühlkörper bleiben offen. Zwei zusammenhängende **Ø1,2-mm-Prüfkorridore** verbinden sie durch vorhandene Kopfbodenschlitze mit dem Plenum und durch Rückwandschlitze mit der Umgebung. Die Bauteilseite wird um das linke Platinenende herum angebunden.
- **Halter und Montage:** Die endgültigen Netze lassen Platine und Kühlkörper über 30 mm senkrecht ein- und ausbauen. Anschläge begrenzen die Verschiebung nach vorn und hinten. Der geprüfte Deckelhub umfasst Platine und Kühlkörper gemeinsam.
- Die bestehenden Prüfungen für obere Eckübergänge und Sockelfuge bleiben aktiv.
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

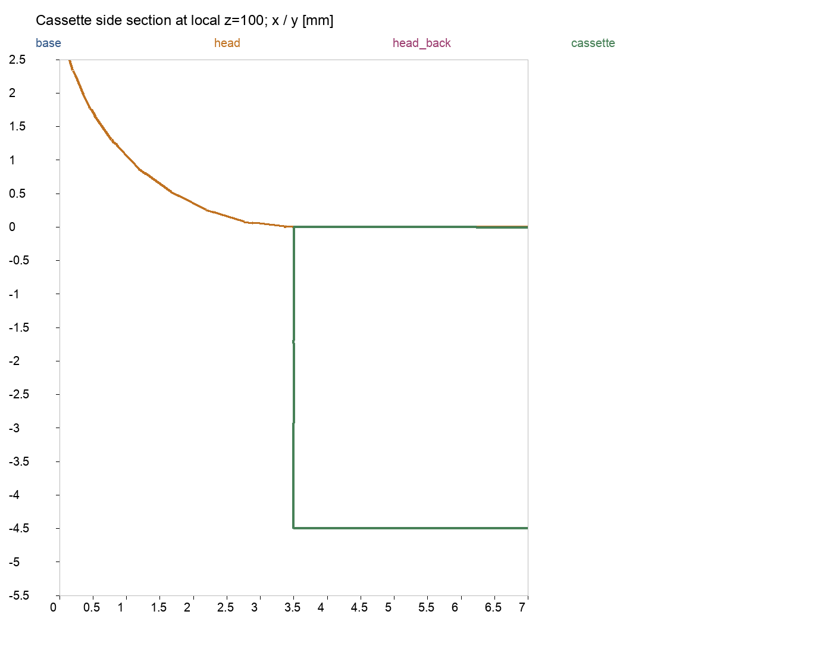
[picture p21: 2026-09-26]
docs/audit-2026-09-23/cassette_side_bevel.png

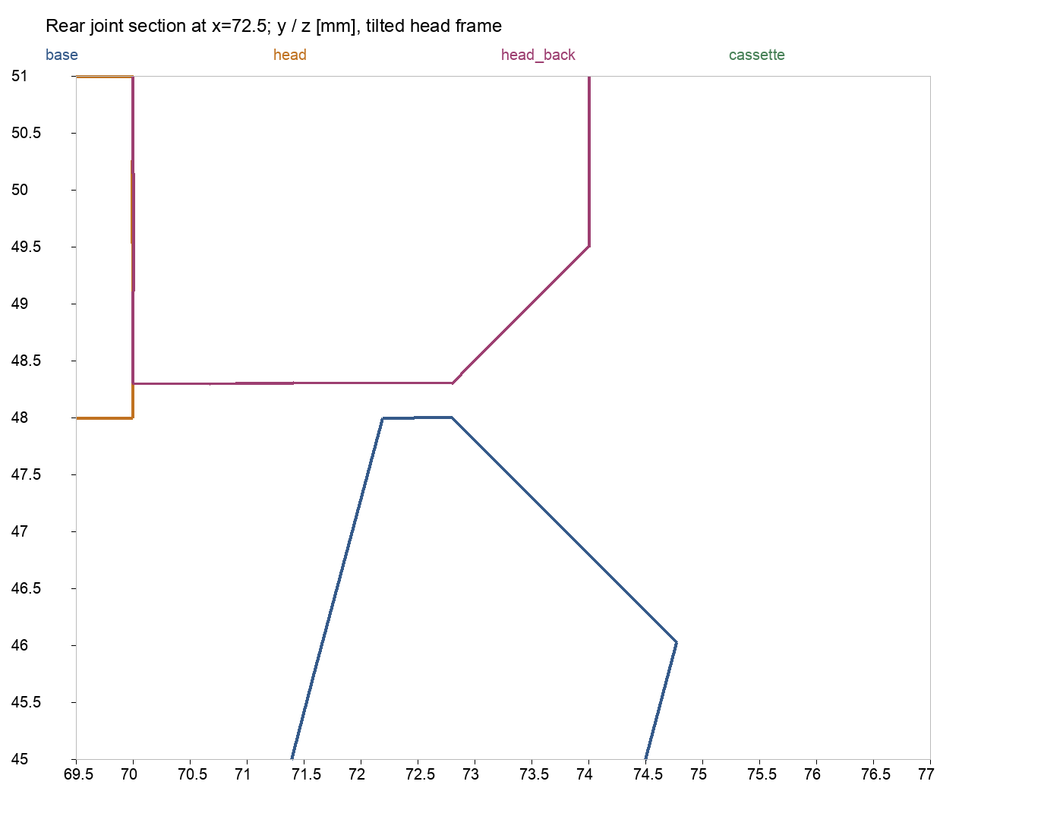
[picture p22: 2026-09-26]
docs/audit-2026-09-23/rear_joint.png

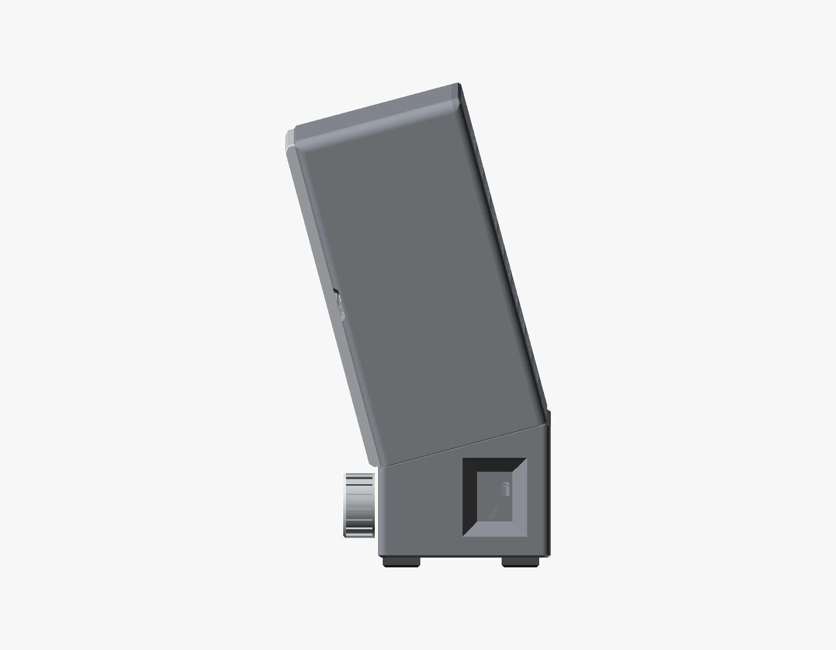
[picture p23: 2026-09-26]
docs/audit-2026-09-23/side.png

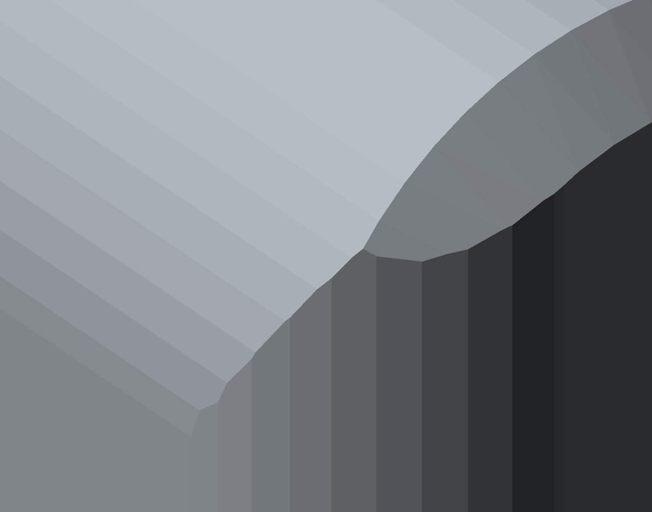
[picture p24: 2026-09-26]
docs/audit-2026-09-23/head_top_corner_close.png

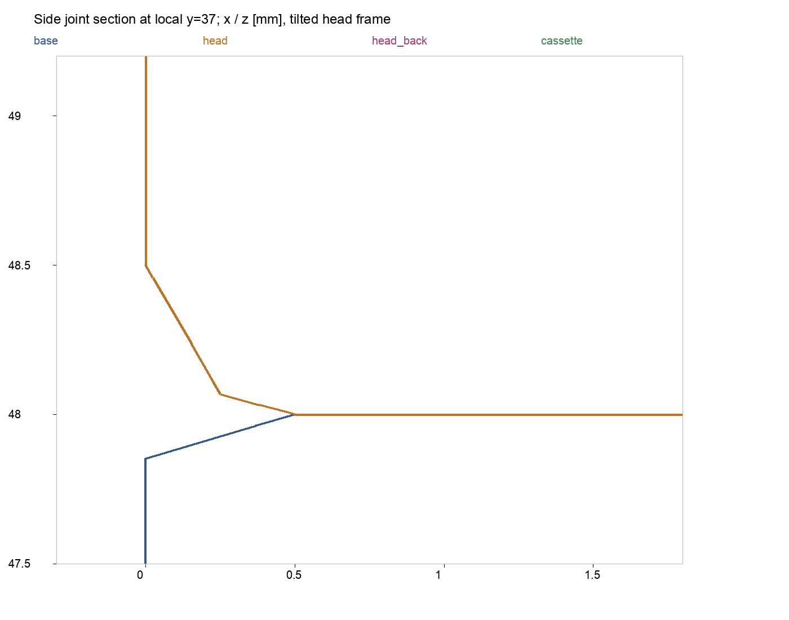
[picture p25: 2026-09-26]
docs/audit-2026-09-23/side_neck.png

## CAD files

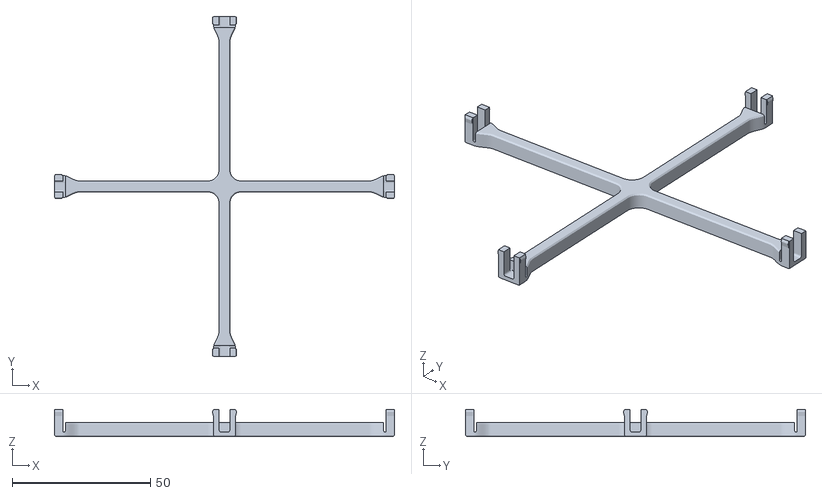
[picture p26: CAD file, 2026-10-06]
stl/filter_support.stl
123.0 x 123.0 x 9.80

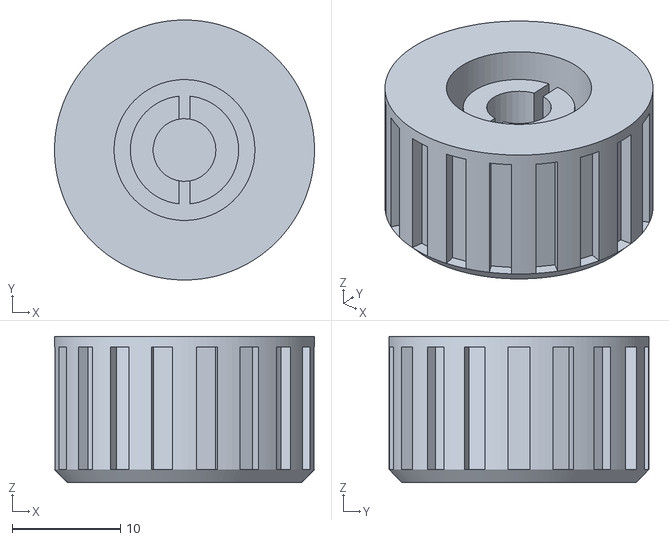
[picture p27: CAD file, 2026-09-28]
stl/multicolour/knob_base.stl
24.0 x 24.0 x 13.5

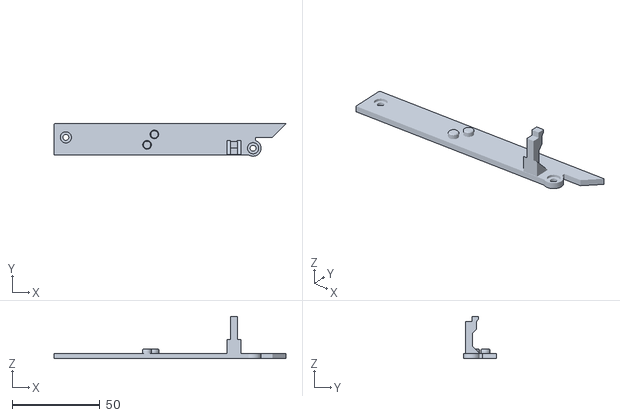
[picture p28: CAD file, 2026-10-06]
stl/ball_lid.stl
132.6 x 18.6 x 24.2

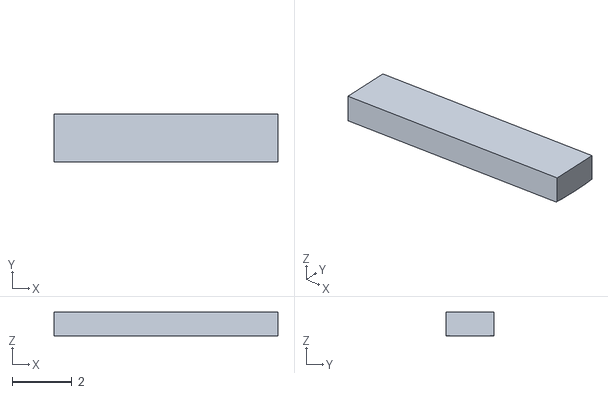
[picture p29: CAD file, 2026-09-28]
stl/multicolour/knob_pointer.stl
7.50 x 1.60 x 0.8

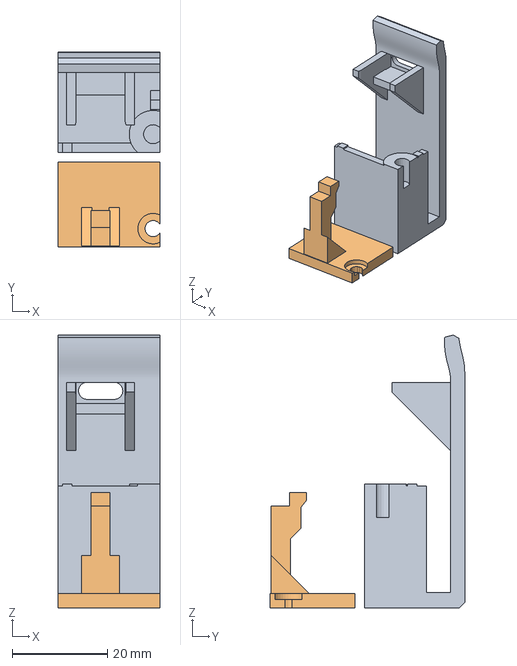
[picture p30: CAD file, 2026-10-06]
stl/fumex_usb_fit.3mf
21.5 x 40.8 x 57.3 mm
usbc_fit_base_1
usbc_fit_lid_1

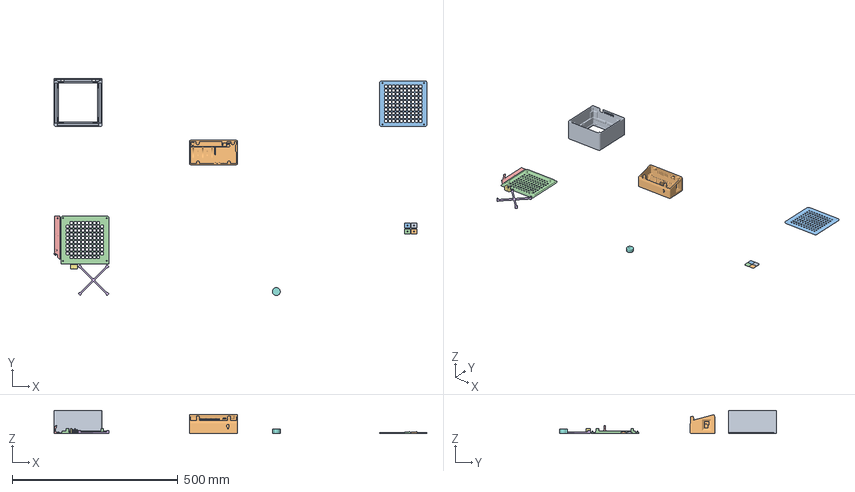
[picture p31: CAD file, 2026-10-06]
stl/fumex_all_parts.3mf
1124.0 x 654.0 x 70.0 mm
head_1
base_1
cassette_1
head_back_1
ball_lid_1
filter_support_1
chg_holder_1
knob
foot_1
foot_2
foot_3
foot_4

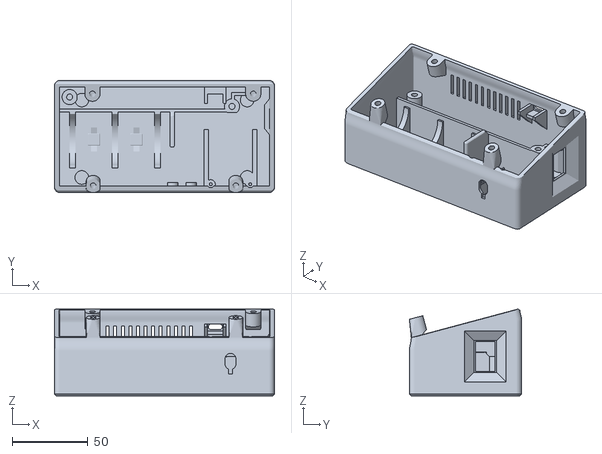
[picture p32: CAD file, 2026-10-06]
stl/base.stl
145.0 x 74.0 x 57.3

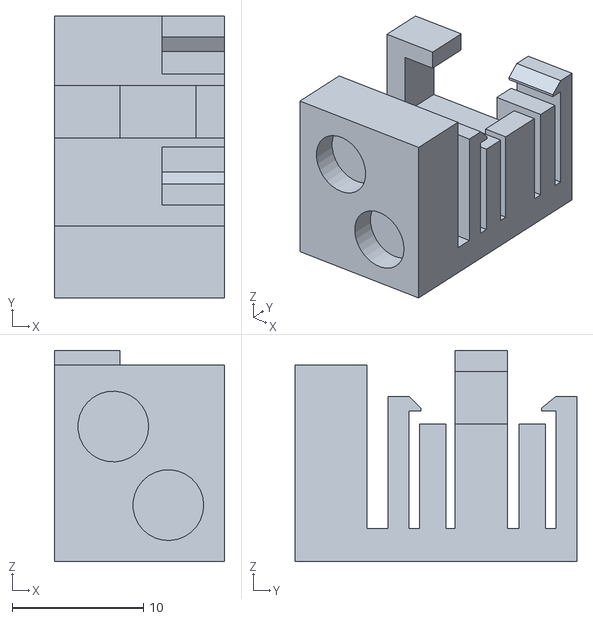
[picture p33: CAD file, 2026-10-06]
stl/chg_holder.stl
13.0 x 21.5 x 16.1

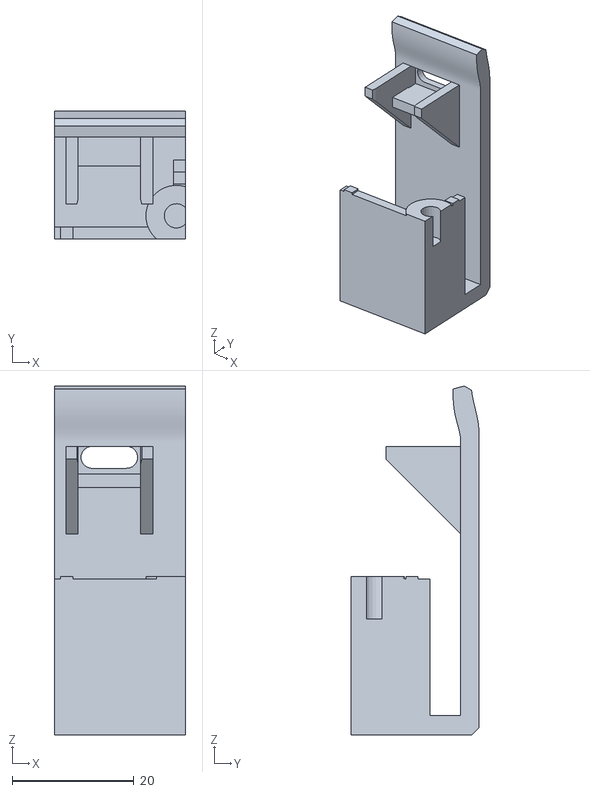
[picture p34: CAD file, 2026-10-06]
stl/usbc_fit_base.stl
21.5 x 21.0 x 57.3

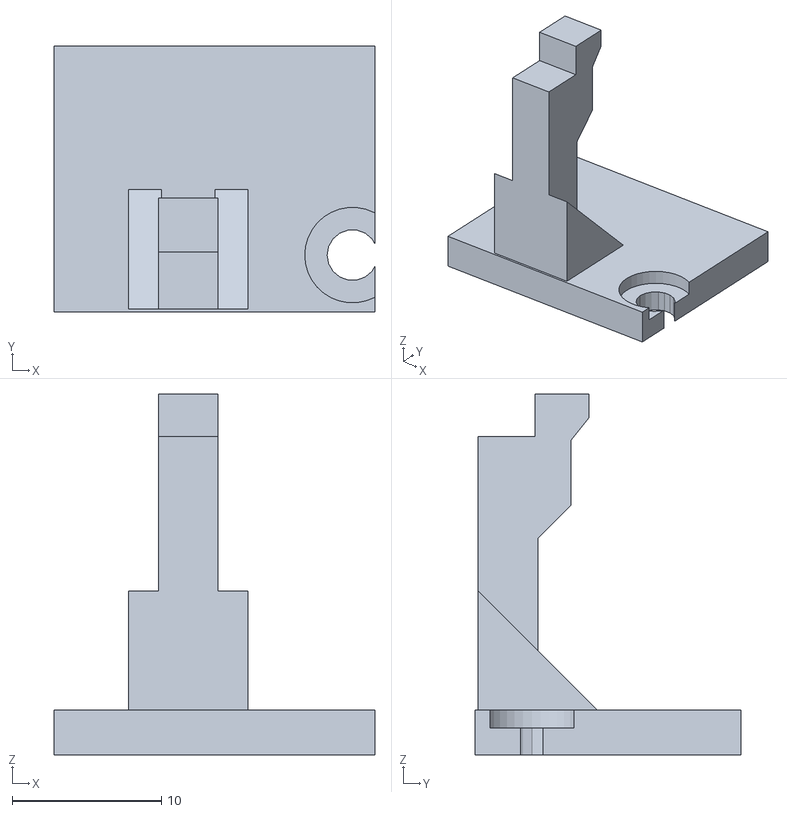
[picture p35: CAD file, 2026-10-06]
stl/usbc_fit_lid.stl
21.5 x 17.8 x 24.2

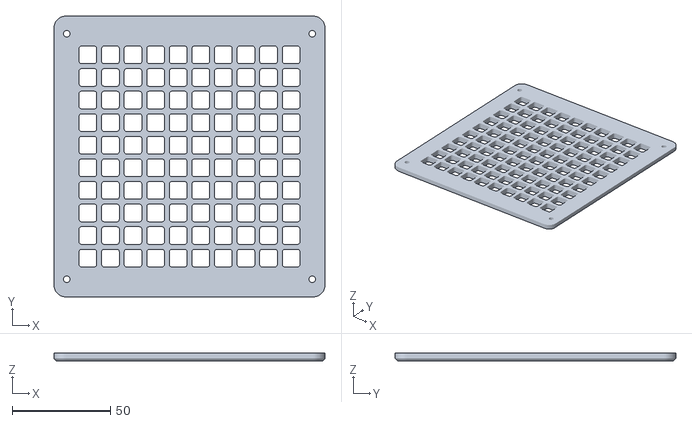
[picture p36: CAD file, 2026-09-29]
stl/cassette.stl
138.0 x 143.0 x 4.00

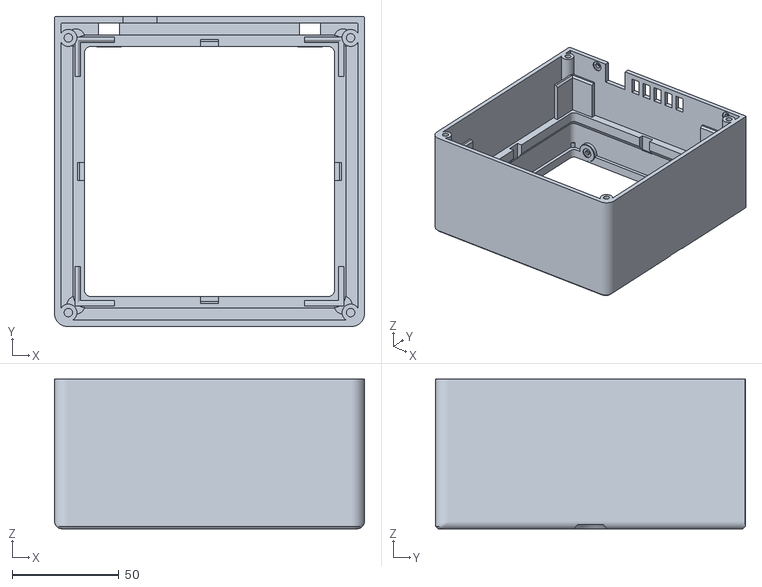
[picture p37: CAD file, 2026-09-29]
stl/head.stl
145.0 x 145.0 x 70.0

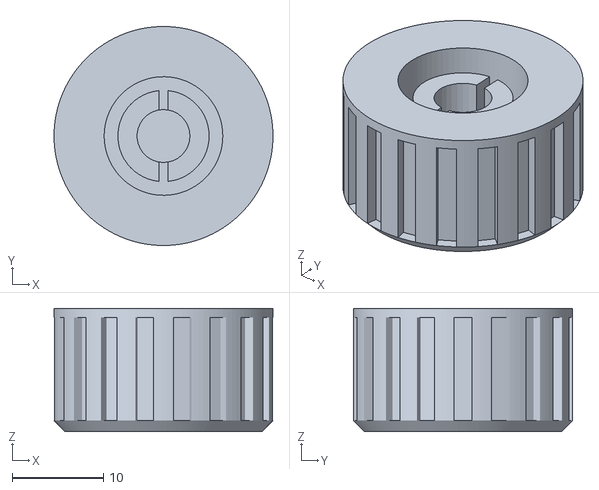
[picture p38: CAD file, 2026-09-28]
stl/knob.stl
24.0 x 24.0 x 13.5

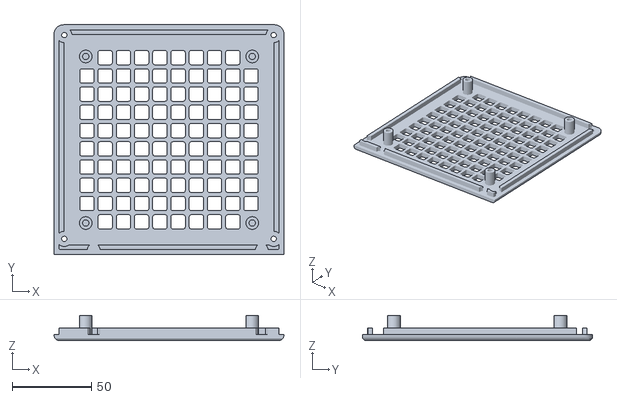
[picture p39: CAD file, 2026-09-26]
stl/head_back.stl
145.0 x 144.7 x 15.9

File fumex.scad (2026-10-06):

// FUMEX: solder fume extractor. A 120 mm PWM fan (Arctic P12 Pro) draws through a 120 x 120 x 17 mm
// filter mat and blows out the back; 3.2 V 6000 mAh LiFePO4 pack, same electronics as LEO-AC1.
// Skill openscad-print-project. Units mm, Z up.
// Installed frame: x = width (left to right seen from the front), y = depth (front face at y = 0,
// back at y = body_d), z = height (underside of the base at z = 0).
// The housing bends: the base stands upright, the head above it leans `tilt` degrees forward so the
// intake looks down at the work. Head modules are written in the UNTILTED frame (same axes, head
// floor on the plane z = base_h); head_at() tilts them about the joint line.
// Modules build every part in its INSTALLED position; the part branches at the end put each print
// part into PRINT orientation (largest flat face on the bed at z = 0). The tools set `part`.

include <BOSL2/std.scad>

part = "assembly";   // print part, "assembly", "exploded", "metrics", "none"
$fa = 2;
$fs = 0.6;
eps = 0.01;
tip = 0.2;           // thickness of hull tips: eps-thin tips leave degenerate triangles in Manifold exports

/* [Housing] */
body_w = 145;        // outer width (x); retained housing footprint and four corner cassette fasteners
body_d = 74;         // outer depth (y): base and head share one footprint, so the head closes the bay
wall = 3;            // walls, at least seven 0.4 mm lines
floor_t = 3.2;       // base floor
corner_r = 6;
top_corner_steps = 28; // angular subdivisions of the tangent corner blend
plan_r = 3.5;        // shared vertical-edge radius; retains the existing base/head joint outline
corner_rb = 0.5;       // at the joint: small enough that the base rim can follow it, see head_outline()
neck_r = 1;        // the same arc mirrored into the base rim, half a millimetre wider - see joint_neck()
edge_c = 1.2;        // 45 degree chamfer on the bed edges
tilt = 15;           // forward lean of the head (user: the housing itself makes the bend)
base_h = 48;         // joint plane height at mid-depth; the plane rises towards the back
joint_y = 37;        // the joint plane turns about this line (mid-depth)
base_joint_h = 8;    // smooth transition to the tilted head footprint, measured normal to the joint
base_joint_steps = 32;
base_joint_wall_extra = 0.15; // extra material inside the transition keeps normal wall thickness >= 3 mm

/* [Head: fan and filter] */
head_h = 145;        // head height (z) in the untilted frame
front_t = 5.6;       // solid intake face; retains the existing filter and fan positions
open_sq = 117;       // square opening in the intake face; its lip holds the mat in the chamber
open_r = 3;
mat_stop_rise = 1.5;  // flank of the rear lip: 1.5 mm of depth per mm inwards, so it is not an overhang
mat_support = [4, 5, 123, 23.1, 32.9, 8, 58.5, 0.2];
// Cross: bar width/depth, outer span, front/rear y, end-pad width, post inner radius, pocket clearance.
// Printed separately, mat-facing side down. Keep these socket dimensions compatible with printed heads.
mat_clip = [0.35, 1.6, 3.8, 0.9, 0.6, 1.4, 0.8];
// Side bulge, solid foot, central slot, radial relief, slot-root radius, lead ramp, rear ramp (mm).
// Eight spring cheeks grip the unchanged 8.4-mm sockets at a free width of 8.7 mm.
chamber_sq = 121.5;  // filter chamber, 0.75 mm wider than the hand-cut mat all round
chamber_d = 17.5;    // the mat is 17 mm (user, cut from a cooker hood mat)
tube_w = 3;          // wall of the filter chamber inside the shell
lug_d = 10;          // chamber depth behind the mat; the rear lip runs on to the fan frame's seat
plenum = 11.9;       // shortened by the thicker intake face; outer housing depth stays unchanged
back_t = 4;
lip_h = 4;           // back cover lip reaching into the head
lip_t = 3;
lip_cl = 0.25;
boss_d = 8;          // back cover bosses along the walls, clear of the fan
boss_inset = 6.5;    // back cover boss axes from the left and right faces
boss_bottom = 10;    // ... and of the lower pair above the head floor: its screw pocket must stay
                     // inside the cover, whose lower edge sits on the floor
cover_gap = 0.3;     // the back cover runs the full height of the head (user, 2026-09-22); its lower edge
                     // keeps this much off the joint plane, otherwise it grinds along the base rim on its
                     // way off and the path check sees the facets of two coplanar faces touching
grid_bar = 2.5;      // intake and exhaust grid
grid_gap = 9;
grid_r = 1.2;
exhaust_sq = 121;
scoop = [16, 2];     // finger scoops at both side edges of the intake face: diameter, depth (45 degree cone)
guide = [2.4, 16];   // L-ribs guiding the fan onto its seat: thickness, leg length
guide_c = 1.2;       // 45-degree lead-in on the two inner edges at the rear of each guide
fan_post_d = 8;      // spacer posts on the back cover, carrying the fan and its inserts
fan_cable_slot = [32, 48, 56.7]; // x limits and front y; open to the rear for lateral cable insertion

/* [Fan: Arctic P12 Pro, 120 x 120 x 25 mm PWM, 0.33 A at 12 V] */
fan_size = 120;
fan_t = 25;
fan_pitch = 105;     // mounting hole spacing (120 mm fans)
fan_hole_d = 4.5;
fan_blade_d = 113;
fan_cl = 0.4;        // clearance per side in the corner guides

/* [Filter cassette: four M3 screws into heat-set inserts] */
cass_t = 4;          // no magnet cavities; the recessed M3 x 8 retains 2.1 mm bearing stock
cass_recess = 1.9;   // the complete 1.65 mm button head sits 0.25 mm below the outer face
cass_c = 1.2;        // 45 degree bevel on the finished contour; 2.8 mm of the rim stays straight
cass_inset = 1;      // flange inside the head outline, leaves a ledge beside the finger scoops
cass_corner_r = corner_r; // four complete tangent rounds, matching the head's upper R6 corners
cass_screw_off = 62.5; // axes from the head centre; the four retained 10-mm-inset corner positions
cass_boss_d = 8.4;   // 2.2 mm radial stock around the 4 mm Ruthex bore, clear of the rounded mat
cass_boss_len = 9;   // 7 mm front-open pocket plus 2 mm blind end

/* [Battery, 3.2 V 6000 mAh LiFePO4 pack, lying across the bay] */
bat_d = 32.5;        // measured cell body without the protection board (LEO-AC1, 2026-09-15)
bat_l = 71.6;        // measured cell-body length; cable end to the right
bat_bms = [20, 4];   // protection board, here facing up: width, thickness
bat_x0 = 4;
bat_cy = 35;         // well forward: everything behind the cell is ballast (user, 2026-09-22). Not
                     // further, or the tilted run-outs of the front head screw bosses reach the cell
bat_cz = 22;
bat_clear = 0.5;
cradle_x = [12, 40, 68];
cradle_t = 4;
cradle_out = 2.5;    // saddle material beyond the cell: every mm here is a mm less ballast trough
bat_stop_gap = 0.5;  // axial clearance to the base's right-hand battery stop
bat_stop_w = 3;      // floor-rooted end wall thickness
bat_stop_y = [30, 51]; // stays ahead of the ballast lid
bat_stop_top = 29;   // below the BMS and upper cable exit
bat_stop_c = 0.4;    // soften the top against the cell's insulating wrap
bat_stop_link_overlap = 1; // embed the floor-rooted stop connection into the trough front wall
bat_tie_x = [26, 54]; // two floor-rooted loops between the three existing saddles
bat_tie_slot = [4, 1.8]; // clear tunnel width and height, for ties up to 3.6 x 1.2 mm
bat_tie_floor = 1.85; // solid floor remaining below the recessed tie tunnels
bat_tie_roof = 1.6;
bat_tie_span = 8;     // bridge length along the tie route (Y)
bat_tie_wall = 2;
bat_tie_head_clearance = [8.8, 18, 13, 1.7]; // retained head relief: x width, y start, y span, depth
bat_tie = [3.6, 1.2, 150];                // conservative band width/thickness, minimum nominal length
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

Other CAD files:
stl/foot.stl

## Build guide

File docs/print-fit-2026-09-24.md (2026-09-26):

# Battery and USB-board fit correction — 2026-09-24

The first printed base exposed two assembly defects: the battery could slide
lengthwise out of its open saddles, and the USB board could not be threaded into
its channel. Its seated envelope fitted, but the fixed front stop blocked the
motion needed to engage the receptacle in the rear wall.

## Changes

- The ballast lid extends beside the battery's right end, with 0.5 mm axial
  clearance. The 8 mm wide, 3 mm thick tongue has rounded corners, chamfered edges
  and a wider root. It remains below the BMS and the upper cable exit. The left
  housing wall supplies the other axial stop; the open base still permits upward
  battery removal.
- The fixed USB front stop is removed from the base. A removable stop on the
  screwed ballast lid takes its place. It catches the lower PCB edge rather than
  relying on the component envelope, and leaves the central wire opening free.
  The original 45-degree support gussets and rear board seat remain.
- With the head and loaded lid removed, the USB board can move 20 mm forwards
  and then 30 mm upwards, fully outside the base. Reverse this path to install
  it, then fit the lid and its stop.
- Two optional test pieces are cropped from the actual base and lid. Three
  fixture pads replace the screw-post seats outside the crop and place the test
  lid at its actual height. They are included only in the test base.
- Local reliefs at the lid's rear corners and USB slots provide room for its
  complete removal. The lower slot seam stays narrow to contain the ballast;
  the upper slot sides open on 45-degree ramps. The small recess under the USB
  seat leaves 2.7 mm of lid thickness.

## What to print

First print [the USB fit test](../stl/fumex_usb_fit.3mf) and check the real board,
receptacle and soldered wires. After a successful fit, print the revised
[base](../stl/base.stl) and [ballast lid](../stl/ball_lid.stl). Other production
parts are unchanged.

The battery extension alone is compatible with the original base, but the new
lid also includes the USB stop: the complete fix requires removing the original
fixed stop or using the revised base. Replacing only the lid does not solve the
USB insertion defect of the already printed base.

## Verification and limits

The geometric checks now separate support, positive retention and assembly
access. Battery retention is checked in nine shifted/raised poses. The USB path
has a continuous swept-volume check against the base, as well as a sampled path
with the other fitted components. A thin lower PCB-edge probe independently
checks the new stop. The original fixed USB stop fails the path check.

The [negative controls](print-fit-2026-09-24/negative-controls.json) reproduce both
defects with the original printed-base and lid meshes: the old USB stop causes
20.910724 mm³ of swept interference, and the old lid fails the battery-stop
existence check. The corrected geometry must pass these same checks.

The complete loaded-lid path removes the head, battery and two lid screws,
then lifts 11.4 mm, rolls the right edge upwards 5.9 degrees, moves 20 mm forwards
and lifts fully outside the base. It is checked in 497 poses with a minimum
0.15 mm clearance gate after the initial lift. The USB board, PWM controller and
switch stay installed. PWM removal now requires removing the loaded lid first.

These tests use measured overall hardware dimensions and simplified component
envelopes. They do not prove fit with actual solder joints and wires, printed
strength, retention force or manufacturing tolerances. The small test print
addresses the actual USB fit before another complete base is printed.

Final mesh, path and slicing figures are recorded in
[verification.json](verification.json) and [slicer-summary.json](slicer-summary.json).

Final geometry source SHA256: `a05f927b9d51141d7d27e9c4f06de12cda11b39044b67b257b1b7135bd99a771`. Ten closed exported meshes contain eight production types (eleven pieces) and two optional test pieces. All 528 assembly pairs, 443 coaxial feature pairs, ten standard paths, the PWM path and the complete loaded-lid path pass. The latter has a measured minimum clearance of 0.15755 mm during its roll and withdrawal.

Islands, overhangs and fins are CLEAN on all ten meshes. Thickness reports only the two authorised 0.8 mm LED skins; both new test pieces and the modified lid have no findings. The known head ray-sampling numerical warnings remain visible in the saved thickness log.

All ten individual types, all four production plates and the fit-test plate slice with supports disabled and no warnings. Production plates total 477.1 g / 15.8 h; the two-piece USB fit test totals 11.8 g / 1.2 h (the single plate estimate is 1.17 h). The six other production STL files are byte-identical to the previous commit.

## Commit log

2026-09-26 FUMEX: solder fume extractor, 120 mm fan with an intake-side filter mat
    Battery-powered bench extractor built on the LEO-AC1 electronics with an
    Arctic P12 Pro. The housing stands upright over the electronics bay and
    bends 15 degrees forward so the intake looks down at the work.
    Instead of a flat fan seat plate with a round bore, which would have been
    a 4400 mm2 flat overhang over the filter chamber, the chamber corners
    fill in at 45 degrees and carry the fan inserts. Every part prints
    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
    [base.stl, cassette.stl, foot.stl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]
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2026-09-26 Charge module: heatsink through the back wall instead of a closed bay
    The CN3058E is a linear charger and turns about 1.6 W into heat at 1 A,
    right while the LiFePO4 cell is being charged. Standing upright in the
    middle of a sealed bay, 4.4 mm from the cell, that heat had nowhere to
    go (user: it gets warm and has no air).
    The board now lies flat on the inside of the back wall and its heatsink
    reaches through a cut-out into ambient air, 4 mm proud of the back face.
    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
    [base.stl, fumex.scad, fumex_all_parts.3mf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]
2026-09-26 Ballast troughs and the front feet 5 mm forward: 13.9 to 20.5 degrees of tip angle
    The head leans 36 mm out over the front of the base, which left only
    20.4 mm of margin to the front foot edge - a 0.8 N nudge at the top.
    Two measures, both asked for by the user. The front feet move to y = 5
    so the pads stand 3 mm proud of the front face: the tipping edge is
    where the pad reaches, not where the housing ends, and that alone is
    worth 3.6 degrees. Behind the battery two troughs with their own dam
    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
    [base.stl, fumex.scad, fumex_all_parts.3mf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]
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2026-09-26 Charge module into the airflow, one big ballast trough with a lid, four cover screws
    Six changes from one round of feedback:
    The charge module leaves the base. It now lies on the inside of the back
    cover with its heatsink a few millimetres behind the fan, so nothing
    sticks out of the housing and its 1.6 W never reach the cell. The plenum
    grew to 14.3 mm and the body to 74 mm deep for it. Its ledges bear only
    on the last 19 mm of the long edges, where the board has no tall parts.
    Ballast: the cell moved forward to y 35, everything behind it is one
    trough of 39 cm3 (about 184 g of loose iron) with a screwed lid instead
    of potting. The lid takes M3 plastic-forming screws straight into
    printed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
    [ball_lid.stl, base.stl, fumex.scad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]
2026-09-26 Charge module onto the head floor in its own holder, ballast over the full width
    The board now stands upright in the plenum on the head floor (user), so
    the back cover comes off without it and its wires drop straight into the
    base. It sits in chg_holder, a part of its own screwed to the floor with
    two M3 x 8: anything standing in the plenum blocks the fan on its way
    out, and a bracket cast into the head would have trapped the fan for
    good. Its grooves take the short edges of the board, because the long
    ones carry parts right up to them.
    The ballast trough now runs the full width and is lower, with the USB-C
    socket above it. 44.5 cm3, about 209 g, and 24.5 degrees of tip angle at
    1.04 kg. Ev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
    [ball_lid.stl, base.stl, chg_holder.stl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]
2026-09-26 Charge module back in the bay, with a vent over it and slots in the back wall
    Third and best placement (user). The board stands in two grooved
    brackets on the bay floor, which in print are plain vertical walls, and
    its wires stay short. Nothing stands in the fan's way out any more, so
    the separate holder part is gone again.
    The vent works because the head already carries a channel: the 5.75 mm
    gap between the filter tube and the shell runs under the fan into the
    plenum. Slots in the head floor meet it, so the fan pushes filtered air
    down over the board and out of the new slots in the back wall, and with
    the fan off the same path is a chimney. Nothing bypasses the mat.
    The vent is six slots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
    [base.stl, chg_holder.stl, fumex.scad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]
2026-09-26 Back wall slots in one straight row
    The stagger was there against the collinear-corner trap that once left a
    degenerate triangle in every backend. At 12 slots of 2 mm on a 5 mm
    pitch it does not reappear, so they line up as asked.
    [base.stl, fumex.scad, fumex_all_parts.3mf]
2026-09-26 Switch behind the board and lower, knob right, feet inside the chamfer, lid screws reachable
    The switch moves behind the PWM board in y instead of above it in z,
    which is what lets it sit 8 mm lower and the knob move 8 mm right at the
    same time; the ballast trough's front wall steps back on the right to
    make room for its body.
    The front feet stood proud of the chamfered bottom edge, so all four
    pads move 2 mm inside the outline. The ballast lid's screw posts move
    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
    [ball_lid.stl, base.stl, fumex.scad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]
2026-09-26 Head outline square at the bottom, so its side walls meet the base without a step
    The head carried the 6 mm corner radius on its lower edge too, so at the
    joint plane it measured 133 mm across while the base rim measures 145.
    Its side walls curved away from the base and left a visible step right
    where the two parts meet. Rounded at the top, square at the bottom.
    [cassette.stl, fumex.scad, fumex_all_parts.3mf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]
2026-09-26 Bevel the cassette rim, round all four corners of the back cover
    The cassette cannot sit flush in the intake face - the head prints with that face on the bed, so a
    recess for it would be a 5687 mm2 horizontal ceiling over the filter chamber - and it cannot get
    thinner than 4.5 mm either, because the magnet pockets are 3.2 deep and the minimum wall is 1.2.
    What is left is the rim: a 2.0 mm 45 degree bevel instead of the 1.2 mm bed chamfer takes the
    visible step from 4.5 mm down to 2.5 mm. 2.0 is the limit, and an assert holds it there - one tenth
    more and the bevel would break into the magnet pockets.
    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
    [cassette.stl, fumex.scad, fumex_all_parts.3mf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]
2026-09-26 Radius on all four corners of the cassette, and break the acute rim edge at the back
    The cassette lies on the intake face and lands on nothing, so like the back cover it now keeps the
    6 mm radius on all four corners instead of the shell's square bottom. Only the head shell itself
    still needs the square corners, where its side walls meet the base rim.
    At the back the joint plane rises 15 degrees and meets the vertical back face at 75 degrees, which
    left an acute edge across the full 145 mm - the one the back cover lands on. It is now cut at 45
    degrees to the joint plane. The cover's own lower edge turned out to carry only 0.9 mm of the rim
    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
    [base.stl, cassette.stl, fumex.scad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]
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2026-09-26 Check driver access on every screw, and move the ones that had none
    The user asked whether every screw can actually be reached. Four of four head screws could not, and
    two of four ballast lid screws could not.
    drivers_*() now put a Torx bit and its holder - 4 mm tip, 6.35 mm shank, 13 mm holder - on every
    screw head, pointing away from it. They are ordinary assembly bodies, so the pairwise overlap check
    is the test: a screw nobody can reach shows up as a collision. The ALLOWED_OVERLAPS entries for them
    are assembly stages, not excuses - the head screws go in before the back cover, the ballast lid is
    closed before the head goes on.
    Head screws: from four in the corners to two in one row at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
    [ball_lid.stl, base.stl, fumex.scad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]
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2026-09-26 Carry a 2 mm radius through the joint, in the head and in the base rim
    Whatever radius the head has at its two bottom corners, the base rim has to have as well, or the
    head's side walls curve away from the base and leave a step - which is why those corners were square
    and why every rounded thing on the head had the square shell corner standing 2.5 mm proud behind it.
    6 mm does not fit through a 3 mm wall, and that was built before it was dropped: necking the base rim
    to 133 mm removes the whole side wall over its top 3 mm and the export comes back as 7 bodies, and
    the head's bottom face would be 133 mm wide against a 139 mm bay opening, bearing on the front and
    back rim only. At 2 mm the ri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
    [base.stl, cassette.stl, fumex.scad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]
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2026-09-26 AGENTS: the charger-heat note still described the heatsink poking out of the back wall
    That layout was replaced on 2026-09-22 by the board against the inside of the front wall with a
    vent over it, and the note was never rewritten. It now says where the board actually is - x 24-56,
    z 5-16 - and flags the old wording as stale so it does not come back.
2026-09-26 Charge module onto the ballast lid, under the vent, where the air actually moves
    The user was right: the board stood at the bottom of the front wall, its vent slots were 25 mm above
    it and the outlet was at the far end of the bay. That is the one corner a draught never reaches.
    It now lies flat in a printed tray on the ballast lid at the back, heatsink up, with six slots in
    the head floor directly over it opening into the plenum - the side the fan blows into - and the back
    wall slots a few centimetres behind. Filtered air is pushed down onto the heatsink and straight out;
    fan off, the same short path is a chimney. Still nothing of the filtered stream is lost, because the
    plenum is downstrea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
    [ball_lid.stl, base.stl, fumex.scad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]
2026-09-26 Work through the 2026-09-23 audit: ten findings fixed, two accepted
    G1, the one the user pointed at: the cassette's side bevel was being cut off. cassette_body() made a
    2 mm rim bevel from the head outline, then cass_prism() trimmed the whole part 0.5 mm further in, so
    both long sides came out as a square 4.5 mm wall. cass_face() is now the finished contour - head
    outline intersected with the width the shared footprint leaves - and the bevel is taken from that.
    cass_c drops 2.0 -> 1.2, because the bevel now starts at plan_r and still has to clear the magnet
    pockets; the assert says so.
    A1: the switch notch in the ballast lid sat over live trough volume - a 9 x 3.5 mm hole from the
    iron into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
    [ball_lid.stl, base.stl, cassette.stl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]
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2026-09-26 Require viewer rebuilds and document flexible filter clearance limits
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2026-09-26 Reinforce the filter support cross and widen its bearing pads
    [base.stl, filter_support.stl, fumex.scad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]
2026-09-26 Fix battery retention and USB board insertion with removable lid stops
    [ball_lid.stl, base.stl, fumex.scad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]
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2026-09-28 Add fan-independent cross grip and tighten magnet pockets
    [base.stl, cassette.stl, filter_support.stl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]
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2026-09-28 Reinforce front insert roots in the base
    [base.stl, filter_support.stl, fumex.scad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]
2026-09-28 Tighten USB board guides and make both covers grey
    [base.stl, filter_support.stl, fumex.scad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]
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2026-09-29 Replace cassette magnets with fully recessed M3 fasteners
    [base.stl, cassette.stl, filter_support.stl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]
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2026-10-06 Give the charge module's larger heatsink room on a minimal holder
    The user replaced the 14 x 14 x 6 mm heatsink with a 20 x 20 x 10 mm part
    and found the previous holder too close to it. The board now stands 3.8 mm
    higher and 0.4 mm farther forward, so the heatsink clears the lid and back
    wall. At the OUT end only one web with a central bearing, one lower-edge
    seat and the cable-tie passage remain; the tie moves to 3.35-5.85 mm from
    OUT and the holder ends 8.2 mm before the heatsink. Only the ballast lid
    changes. Checks, air probes, slices, views and viewer are regenerated, and
    slice_check.py is reinstalled from the shared skill.
    [ball_lid.stl, base.stl, filter_support.stl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]
2026-10-06 Clip the charge module into a LEO-AC1 style holder, 2 mm higher
    The minimal lid-integrated holder is replaced by a separate grey holder
    modelled on LEO-AC1: the OUT end goes into an end L, then the board is
    pressed back until two jaws hook 0.9 mm over the part side at both long
    edges, and one cable tie through the web secures it. The jaws spring
    vertically here, so the holder prints with its back plate on the bed and
    is glued with CA gel over two new pads on the ballast lid. The board sits
    2 mm higher; with the centred 20 x 20 x 10 mm heatsink this leaves about
    0.25 mm to the head floor. A spread-jaw unclip path replaces chg_off.
    The shared print_tools.py and slice_check.py are reinstalled,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
    [ball_lid.stl, base.stl, chg_holder.stl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]
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2026-10-07 Record the printed build: everything fits
    The user printed and assembled revision 04de3ae and reports that all
    former open fit items pass. README gets a status line; AGENTS.md
    replaces the open-item list with the build result and the values that
    remain unmeasured (masses, temperatures, long-term creep, pressure drop).
2026-10-07 Close all open items after the confirmed build
    The user confirmed that the printed device fits and that its weight is
    fine; no open items remain. print_project.py no longer emits the
    physical-check reminders, so `opp check --strict` passes, and the
    regenerated report lists no open measurements. AGENTS.md records the
    closure; the tipping model keeps its estimated masses.
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2026-10-18 opp 1.9.0: failure close-ups, change picture, print log
    A failing geometry check now leaves a close-up in build/fail/, and opp
    dev shows what changed since the last run in build/changes.png. New
    commands: opp printed (print log in docs/prints.json), opp measure and
    opp params (measurement sheet, measured values into the model), opp lib
    (parts library) and opp makerworld (upload package). opp all PASS;
    STLs, 3MF and plate totals (480.1 g, 16.3 h) unchanged: only the pin.
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
